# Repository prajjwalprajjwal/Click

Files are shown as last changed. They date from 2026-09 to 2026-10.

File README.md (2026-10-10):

# Clicker Project 🎮

Official repository for the Clicker handheld device ecosystem, encompassing production firmware, hardware schematics, PCB designs, automated asset build pipelines, and browser-based WebSerial flashing tools.

---

## 📁 Repository Structure

```text
Click/
├── README.md                          <-- Master documentation and system overview
├── PROJECT_RULES.md                  <-- Protected subsystems, NVS rules & coding freeze
├── CHANGELOG.md                      <-- Comprehensive release history & architecture decisions
├── platformio.ini                    <-- PlatformIO configuration & automated build flags
├── build_release.bat                 <-- 1-Click Interactive firmware release packager
├── run_flasher.bat                   <-- 1-Click Localhost WebSerial server runner
├── flash_device.bat                  <-- 1-Click Desktop CLI serial flasher
├── hardware/                         <-- Electrical schematics & mechanical designs
│   ├── vector_designs.ai             <-- Vector graphics & enclosure laser/artwork
│   └── PCB/                          <-- KiCad PCB manufacturing & CAD files
│       ├── Click1/                   <-- Active prototype KiCad PCB & schematic (ESP32-WROOM-32E)
│       ├── Click4/                   <-- Next-Gen RP2354A PCB (JLCPCB PCBA Production V0.0.1)
│       └── Resources/                <-- Edge cut DXF files and mechanical templates
├── server/                           <-- Cloudflare Worker + D1 Serverless Leaderboard Backend
│   ├── worker.js                     <-- Edge API routes (/api/leaderboard, /api/sync)
│   ├── schema.sql                    <-- D1 SQLite schema (devices, global_stats, sync_log)
│   ├── wrangler.toml                 <-- Cloudflare Worker deployment configuration
│   └── README.md                     <-- 3-minute zero-cost deployment guide
├── firmware/                         <-- Modular C++ embedded firmware
│   ├── assets/screens/               <-- 1-bit screen bitmaps & sprites (.png)
│   ├── scripts/
│   │   ├── pre_build_assets.py       <-- PlatformIO pre-build hook (auto-converts assets)
│   │   ├── convert_assets.py         <-- Converts PNGs to C PROGMEM bitmap headers
│   │   ├── flash.sh                  <-- Flashing utility for macOS / Linux
│   │   └── flash.bat                 <-- Flashing utility for Windows
│   └── src/                          <-- Application source code & applets
│       ├── main.cpp                  <-- Application entry point, serial protocol & registry
│       ├── system/                   <-- Core OS, drivers & power management (untouched by applets)
│       │   ├── Applet.h              <-- Base class interface for all applets
│       │   ├── OSManager.h / .cpp    <-- Applet scheduler & sleep lifecycle
│       │   ├── PowerManager.h        <-- Light/Deep sleep, UART isolation & I2C recovery
│       │   ├── Display.h             <-- SSD1306 OLED singleton & 400kHz fast I2C
│       │   ├── InputManager.h / .cpp <-- Debounced button state machine & hold triggers
│       │   ├── battery.hpp           <-- Battery voltage, percentage & charging status
│       │   └── device_info.hpp / .cpp<-- eFuse MAC ID & customizable owner name
│       ├── applets/                  <-- Self-contained, modular games & apps
│       │   ├── clicker/              <-- Sisyphus uphill clicker game & physics engine
│       │   ├── timing_game/          <-- "Just 10 Seconds" accuracy timing game
│       │   ├── flappy_bird/          <-- Flappy Bird arcade obstacle game
│       │   ├── settings/             <-- Hardware status, voltage & device ID screen
│       │   └── screensaver/          <-- Snowfall particle animation on idle
│       ├── fonts/                    <-- Custom Adafruit GFX typography headers
│       ├── screens/                  <-- Legacy milestone overlay renderers
│       └── generated_assets/         <-- Auto-generated C bitmap headers
├── web_flasher/                      <-- WebSerial flashing & leaderboard site (flashclick.uprajjwal.com.np)
│   ├── index.html                    <-- Web application entry point
│   ├── flasher.html                  <-- Full-featured WebSerial flasher, personalizer & leaderboard UI
│   ├── app.js                        <-- WebSerial engine, personalization & leaderboard sync
│   ├── style.css                     <-- Cyberpunk terminal responsive styling
│   ├── manifest.json                 <-- ESP Web Tools manifest configuration
│   └── versions.json                 <-- Firmware release registry
├── tools/                            <-- Build & developer utilities
│   ├── release/release_manager.py    <-- Interactive version bumper & binary packager
│   ├── flasher/serve_flasher.py      <-- Zero-config HTTP server for web_flasher
│   └── converters/                   <-- TTF font and image conversion scripts
└── docs/                             <-- Architectural specifications
    ├── hardware_and_pinouts.md       <-- Detailed pin profiles (ESP32 vs RP2354A)
    ├── device_identification_and_leaderboard.md <-- eFuse MAC & database schema
    └── leaderboard_architecture.md   <-- Cloudflare Worker API & score sync model
```

---

## ⚡ Hardware Platforms & Pin Profiles

Detailed technical schematics and electrical specifications can be found in [`docs/hardware_and_pinouts.md`](docs/hardware_and_pinouts.md).

> [!NOTE]
> **Active Hardware & Production Platforms**:
> - **Active Production Platform (Click 4 - RP2354A)**: Turnkey PCBA featuring the **Raspberry Pi RP2354A** MCU (Dual Cortex-M33, 512KB RAM, 4MB Flash). Features high-precision calibrated Li-Ion battery telemetry, 12MHz active sleep with $< 1\text{ mA}$ power consumption, dual SK6812 RGB LEDs, piezo sound, and PCF8563 RTC. Active default build environment: `env:rp2354`. Design files in `hardware/PCB/Click4/`.
> - **Legacy Prototype (Click 1 - ESP32-WROOM-32E)**: Hand-assembled prototype board maintained for backward compatibility under `env:esp32doit-devkit-v1`. Design files in `hardware/PCB/Click1/`.
> - **Power & Battery Deep-Dive**: For full architectural documentation on power management, battery discharge modeling, and silicon gotchas, read [**`docs/power_management_and_battery_architecture.md`**](docs/power_management_and_battery_architecture.md).

### Active Production Hardware Specs (Click 4: RP2354A)
- **Microcontroller**: Raspberry Pi RP2354A (Dual Cortex-M33 @ 48MHz, 512KB SRAM, 4MB on-chip Flash)
- **Display & RTC I2C Bus**: `CLICK_I2C = Wire1` (SDA = GP2, SCL = GP3, 400kHz Fast I2C)
- **User Inputs**: MODE = GP0 (Active LOW), ACTION = `BOOTSEL` / `QSPI_SS` (Active LOW)
- **Power & Battery**: STAT = GP1 (Active LOW charging from ETA6003 with 10k pullup), BAT_ADC = GP29 (ADC3 via 100k/100k divider)
- **Audio & Visual**: Buzzer = GP27 (via NPN BJT), RGB LEDs = GP11 (2× SK6812 DIN via PIO)
- **Power Management**: Same-Button Double-Click Wake protection (double-clicking the same key within 500ms), 3-stage sleep profile (8s dim, 15s display off, 30s deep sleep at 12MHz down-clocking $< 1\text{ mA}$), I2C bus preservation (0µA idle)

### Legacy Prototype Specs (Click 1: ESP32-WROOM-32E)
- **Microcontroller**: ESP32-WROOM-32E (Xtensa Dual-Core 240MHz, 4MB Flash)
- **Display I2C**: SDA = GPIO 21, SCL = GPIO 22 (400kHz Fast I2C)
- **User Inputs**: MODE = GPIO 14 (RTC ext0 wake), ACTION = GPIO 32 (RTC ext1 wake)
- **Power & Battery**: STAT = GPIO 33, BAT_ADC = GPIO 35 (100k/100k divider)
- **Sleep States**: Light sleep at 20s (OLED off, I2C pullups held), Deep sleep at 45s (RTC wakeup)

---

## 🕹️ Applet Ecosystem & Gameplay

The firmware features an event-driven `OSManager` hosting four built-in applets and an idle screensaver:

### 1. Sisyphus Clicker (Default Applet)
* **Theme**: Sisyphus rolling his eternal boulder up a steep mountain slope.
* **Dynamics**:
  * **Boulder Physics**: Smooth rotation and position tracking based on player clicks.
  * **Stamina & Fatigue**: Continuous clicking builds fatigue; stopping causes Sisyphus to catch his breath.
  * **Auditory Feedback**: 3 short beeps when the boulder rolls back downhill, with a gentle chime upon hitting bottom. Silent on startup into Sisyphus.
  * **Milestone Celebrations**: Overlay banners and RGB celebration pulses trigger on reaching milestone tiers.
  * **Persistence**: Dual-key NVS backup storage with checksum verification and wear-leveling.

### 2. Just Ten
* Precision stopwatch game challenging players to hold and release the button at exactly **10.0000 seconds**.
* Displays exact millisecond accuracy, tracks personal records, and flashes yellowish LEDs upon stopping.

### 3. Flappy Bird
* Real-time side-scrolling obstacle game featuring obstacle collision detection, velocity physics, and persistent high scores with red LED flash on game over.

### 4. Settings & System Applet
* Accessible by holding the **MODE** button.
* **Page 0 (SYSTEM)**: Shows live battery state (`[CHARGING]`, `[BATTERY]`, `[CHARGED]`), high-precision numerical voltage (`x.xxV`), and a graphical charge bar.
* **Page 1 (SYSTEM INFO)**: Center-aligned hardware telemetry displaying Firmware version, unique Device ID, and MCU specifications.

### 5. Snowfall Screensaver
* Ambient particle simulation that activates automatically when the device remains idle prior to entering sleep.

---

## 🎮 Controls & Navigation Guide

| Action | Control | Description |
|:---|:---|:---|
| **Cycle Applets** | `MODE` Button (Short Press) | Switch between **Clicker**, **Just Ten**, and **Flappy Bird** (click chime plays except before Sisyphus). |
| **Settings Menu** | `MODE` Button (Hold > 1s) | Toggle between the currently active applet and the **SYSTEM** settings screen. |
| **Toggle System Info** | `ACTION` Button (in Settings) | Toggle between Battery Telemetry (Page 0) and System Info (Page 1) screens. |
| **Primary Game Action** | `ACTION` Button (Short Press) | Push boulder in Sisyphus / Flap wings in Flappy Bird / Start & Stop in Just Ten. |
| **Wake from Sleep** | **Same-Button Double-Click** (two clicks on the same key within 500ms) | Wakes the device from low-power sleep back to the Sisyphus game (filters accidental single clicks & cross-key bumps). |
| **Factory Master Reset** | **Both Buttons Held** (> 4s) | Trigger master reset / clear NVS partitions and milestone progress. |

---

## 🛠️ Adding New Applets (Developer Guide)

The system firmware (`firmware/src/system/`) provides an isolated runtime environment. You or any contributor can add new games or micro-apps without touching, altering, or risking the core OS, sleep managers, or display drivers:

1. **Create an Applet Folder**: Create a directory in `firmware/src/applets/` (e.g., `firmware/src/applets/snake/`).
2. **Implement the `Applet` Interface**:
   ```cpp
   #pragma once
   #include "system/Applet.h"
   #include "system/Display.h"

   class SnakeApplet : public Applet {
   public:
       void init() override { /* Setup game state */ }
       void update() override { /* Real-time physics / tick loop */ }
       void draw() override { /* Draw frame on display */ }
       void cleanup() override { /* Teardown temporary state */ }
       void onActionClick() override { /* Handle ACTION button press */ }
   };
   ```
3. **Register in `firmware/src/main.cpp`**:
   ```cpp
   #include "applets/snake/SnakeApplet.h"
   SnakeApplet snakeApplet;

   // In setup():
   osManager.registerApplet(&snakeApplet);
   ```

All input debouncing, display clocking (400kHz Fast I2C), light sleep (15s), deep sleep (30s), and button wakeups continue working automatically in the background.

---

## 🚀 Building, Flashing & Updating

### 1. Web Flasher (Recommended)
* **Online**: Connect your device and visit [flashclick.uprajjwal.com.np](https://flashclick.uprajjwal.com.np).
* **Local Server**: Double-click [`run_flasher.bat`](run_flasher.bat) or run:
  ```bash
  python tools/flasher/serve_flasher.py
  ```

### 2. Desktop Command-Line Flashing
* **Windows**: Run [`flash_device.bat`](flash_device.bat).
* **macOS / Linux**:
  ```bash
  chmod +x firmware/scripts/flash.sh
  ./firmware/scripts/flash.sh
  ```

### 3. Building via PlatformIO
The project uses PlatformIO with an automated asset compilation hook:
```bash
# Compile firmware for Click 4 (Raspberry Pi RP2354A - Default target)
pio run -e rp2354

# Compile with interactive Hardware Diagnostics Suite enabled
pio run -e rp2354-debug

# Compile for legacy prototype (ESP32-WROOM-32E)
pio run -e esp32doit-devkit-v1

# Upload directly over USB serial
pio run --target upload

# Open serial monitor (115200 baud)
pio device monitor -b 115200
```

### 4. Automated Asset Pipeline
Screen graphics placed in `firmware/assets/screens/` are converted to C headers before every compile:
```bash
python firmware/scripts/convert_assets.py
```

### 5. Official Release Packaging
To build an official release, bump semantic versions, and generate 3-part manifests for WebSerial:
```bash
# Windows
.\build_release.bat

# Python direct
python tools/release/release_manager.py
```

## 🌐 Community Leaderboard & Edge Cloud Architecture

The Click ecosystem features a fully connected, zero-maintenance, zero-cost ($0/month) serverless stack running on **Cloudflare Workers** and **Cloudflare D1 (Serverless SQLite)**:

```mermaid
flowchart LR
    DEV["🎮 Clicker Device\n(ESP32 / RP2354A)"]
    WEB["💻 Web Flasher & Hub\n(flashclick.uprajjwal.com.np)"]
    CF["⚡ Cloudflare Worker\n(/api/sync, /api/leaderboard)"]
    D1[("🗄️ Cloudflare D1\n(SQLite at Edge)")]
    SITE["🏆 Community Leaderboard\n(click.uprajjwal.com.np)"]

    DEV <-->|"WebSerial (115200 Baud)\nGET_ID / GET_STATS / SET_NAME"| WEB
    WEB -->|"POST /api/sync\n(Atomic delta push)"| CF
    CF <-->|"ACID SQLite Queries\nAnti-Cheat Validation"| D1
    SITE <-->|"GET /api/leaderboard\n(Edge-cached JSON)"| CF
```

### 1. The "Community Boulder" Mechanic 🪨
* Unlike isolated single-player games, every single click registered on any Clicker device contributes to the **Global Community Boulder**.
* When players connect to the Web Flasher and sync their device, their delta clicks are atomically added to `global_stats.total_boulder_clicks`.
* The live web interface visualizes the worldwide community progress as one shared mountain ascent.

### 2. Anti-Cheat & Physical Rate Limiting 🛡️
* The Cloudflare Worker enforces strict human-velocity checks on every sync request:
  * Delta clicks are validated against elapsed time between syncs (enforcing a physical maximum cap of ~15–20 clicks per second).
  * Excessive or impossible spikes are flagged and rejected, ensuring the Community Boulder and leaderboard rankings remain authentic.
  * Every sync transaction is immutably audited in the `sync_log` table with delta claims and hash signatures.

### 3. Device Personalization & Custom Bootscreen ✨
* Clickers are uniquely identified by their hardware silicon signature:
  * **Raspberry Pi RP2354A**: Permanent 16-character hex Unique Board ID queried via `pico_get_unique_board_id()` (e.g. `E6614104033C71BF`).
  * **ESP32-WROOM-32E**: Factory 12-character hex eFuse MAC address via `ESP.getEfuseMac()` (e.g. `3C71BF89A1B2`).
* Through the Web Flasher interface, players can set or personalize their custom owner name (e.g. `"Prajjwal's Click"`).
* Custom names can be baked into binary firmware via magic rodata signatures (`CLICK_NAME_MAGIC_PREFIX`) or saved persistently to NVS storage (`clicker_cfg` namespace).
* Upon boot, the physical SSD1306 OLED screen proudly renders the personalized owner name on the boot splash screen.

### 4. Interactive Serial Telemetry Protocol 🔌
The firmware exposes a high-speed telemetry interface over USB CDC serial (115200 baud) for browser-based synchronization:
* `GET_STATS` / `STATS` &rarr; Flushes active clicks to storage and returns structured JSON telemetry:
  `{"event":"stats","name":"CLICKER","chip_id":"...","clicks":35200,"flappy":42,"just_ten":10.004,"uptime_hrs":12}`
* `SET_CLICKS <val>` &rarr; Sets lifetime click count and returns:
  `{"event":"clicks_updated","clicks":<val>}`
* `SET_STATS CLICKS=<n> FLAPPY=<n> JUST_TEN=<f>` &rarr; Restores all mini-game scores and returns:
  `{"event":"stats_restored","clicks":<n>,"flappy":<n>,"just_ten":<f>}`
* `PING` &rarr; Returns heartbeat response: `{"event":"pong"}`

### 5. Live Links & Deployment
* **Live Community Leaderboard**: [click.uprajjwal.com.np](https://click.uprajjwal.com.np)
* **Web Flasher & Device Hub**: [flashclick.uprajjwal.com.np](https://flashclick.uprajjwal.com.np)
* **Backend Source & Deployment Guide**: [`server/README.md`](server/README.md)

---

## ⚖️ License

This project (Firmware, PCB schematics & layouts, 3D mechanical designs, and assets) is licensed under the **Creative Commons Attribution-NonCommercial-ShareAlike 4.0 International License ([CC BY-NC-SA 4.0](LICENSE))**.

* **Personal & Educational Use**: ✅ You are welcome to view, modify, download, and fabricate units for your personal, non-commercial use.
* **Commercial Manufacturing & Sale**: ❌ Manufacturing, assembling, packaging, or selling physical units, kits, PCBs, or parts for commercial gain is strictly prohibited without prior written permission from the author.
* See [LICENSE](LICENSE) for complete terms.

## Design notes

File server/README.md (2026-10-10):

# Click Leaderboard & Global Boulder API (Cloudflare Worker + D1)

Zero-cost ($0/month), zero-maintenance serverless backend for the Click Community Leaderboard.

## 🚀 Quick Deploy in 3 Minutes

### 1. Log in to Cloudflare
In your terminal, navigate to this `server/` directory:
```bash
cd server
npx wrangler login
```

### 2. Create the D1 Database
Run:
```bash
npx wrangler d1 create click_db
```
This command will output your `database_id` (a UUID).
Copy that `database_id` into [`wrangler.toml`](file:///Users/prajjwal/Documents/GitHub/Click/server/wrangler.toml) replacing `YOUR_D1_DATABASE_ID_HERE`.

### 3. Initialize the Tables & Deploy
Run:
```bash
# Apply SQLite Schema to remote D1 database
npx wrangler d1 execute click_db --remote --file=schema.sql

# Deploy the Worker
npx wrangler deploy
```

Once deployed, Wrangler will give you a public URL like:
`https://click-leaderboard-api.<your-subdomain>.workers.dev`

You can also bind a custom domain in Cloudflare dashboard (e.g. `https://api.uprajjwal.com.np`).

---

## 📡 API Endpoints

### `GET /api/leaderboard`
Returns current community boulder stats and Top 10 leaderboards across all three minigames:
```json
{
  "global_boulder_clicks": 1420580,
  "total_devices": 38,
  "top_sisyphus": [
    { "device_name": "Prajjwal's Click", "total_clicks": 35200, "last_synced_at": "2026-09-13T08:00:00Z" }
  ],
  "top_flappy": [
    { "device_name": "SkyMaster", "flappy_high_score": 42, "last_synced_at": "2026-09-13T08:00:00Z" }
  ],
  "top_timing": [
    { "device_name": "PrecisionKing", "just_ten_best_ms": 4, "just_ten_time": 10.004, "last_synced_at": "2026-09-13T08:00:00Z" }
  ]
}
```

### `POST /api/sync`
Syncs stats from Web Flasher with human-speed rate limiting (`chip_id` is the 16-character RP2354A Unique Board ID or 12-character ESP32 eFuse MAC):
```json
{
  "chip_id": "3C71BF89A1B2",
  "name": "Prajjwal's Click",
  "clicks": 35200,
  "flappy": 42,
  "just_ten": 10.004,
  "uptime_hrs": 12
}
```
Response:
```json
{
  "success": true,
  "credited_delta": 350,
  "total_boulder_clicks": 1420580,
  "message": "Successfully synced! +350 clicks added to the Community Boulder."
}
```

### `GET /api/user?device_id=3C71BF89A1B2`
Retrieves registered player profile and stats for the given hardware chip ID:
```json
{
  "found": true,
  "device": {
    "chip_id": "3C71BF89A1B2",
    "device_name": "Prajjwal's Click",
    "total_clicks": 35200,
    "flappy_high_score": 42,
    "just_ten_time": 10.004,
    "just_ten_best_ms": 4
  }
}
```

---

## 🛡️ Anti-Cheat & Community Boulder Engine

1. **Human Click Velocity Validation**:
   - Caps delta clicks at humanly possible physical boundaries ($\le 20\text{ clicks/second}$).
   - Any client claiming abnormal click deltas relative to elapsed time since last sync is rejected or clamped to prevent botting/scripting.
2. **Atomic D1 SQLite Transactions**:
   - Updates both the individual device profile in `devices` and the collective boulder count in `global_stats` within an ACID transaction.
3. **Audit Trail**:
   - All claims are stored in `sync_log` with timestamp, claimed delta, credited delta, and hashed client IP.

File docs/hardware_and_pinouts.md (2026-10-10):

# Hardware Architecture & Pin Profiles Specification

This document provides the authoritative hardware reference for the Clicker project, documenting the active **Click 4 PCBA Platform (RP2354A)** and the legacy **Click 1 Prototyping Platform (ESP32-WROOM-32E)**.

> [!IMPORTANT]
> **Active Production Hardware**:
> 1. **Click 4 (RP2354A) - Primary Active Platform**:
>    - KiCad & PCBA Files: `hardware/PCB/Click4/` (`Click4.kicad_sch`, `Click4.kicad_pcb`, `Click4.step`).
>    - Features the Raspberry Pi **RP2354A** MCU (Dual Cortex-M33 with 4MB embedded QSPI Flash).
>    - Active default PlatformIO environment: `env:rp2354` in `platformio.ini`.
>    - Supports native USB 2.0 Full Speed flashing and debugging via `picotool`.
> 2. **Click 1 (ESP32-WROOM-32E) - Initial Hand-Assembled Prototype**:
>    - KiCad Files: `hardware/PCB/Click1/` (`click.kicad_sch`, `click.kicad_pcb`).
>    - Maintained for legacy compatibility under `env:esp32doit-devkit-v1`.

---

## Active Hardware Pinout & Specs (Click 4 PCBA - Raspberry Pi RP2354A)
*Authoritative pin routing defined in [`firmware/src/system/PinConfig.h`](file:///Users/prajjwal/Documents/GitHub/Click/firmware/src/system/PinConfig.h)*

- **Microcontroller**: Raspberry Pi RP2354A (QFN-56 package, 30 GPIOs: GP0–GP29, 512KB SRAM, 4MB on-chip QSPI Flash)
- **Display & RTC I2C Bus (`CLICK_I2C = Wire1`)**:
  - **SDA**: `GP2` (I2C1 SDA, Pin 4)
  - **SCL**: `GP3` (I2C1 SCL, Pin 5)
  - **Bus Speed**: 400kHz Fast I2C
  - **Peripherals**: 128×64 SSD1306 Monochrome OLED (`0x3C`) + NXP PCF8563 Real-Time Clock (`0x51`)
- **User Inputs**:
  - **MODE Button (`S1`)**: `GP0` (Active LOW, internal pull-up, level-sensitive wake capable)
  - **ACTION Button (`S2`)**: `BOOTSEL` / `QSPI_SS` (Active LOW, dual-purpose game click & bootloader pin)
- **Power & Battery Subsystem**:
  - **Battery Voltage Sense**: `GP29` (ADC3 / Pad 41) via 100kΩ / 100kΩ divider (2.0x factor, 12-bit ADC)
  - **Charger Status (`STAT`)**: `GP1` (Pad 3) &rarr; Driven by ETA6003 `STAT` pin (Active LOW while charging, 10kΩ pullup `R9` to +3V3)
  - **Battery Charger**: ETA6003Q3Q switching Li-Ion charging controller (`U5`) with 2.2µH power inductor (`L3`)
  - **Voltage Regulator**: Diodes Inc. AP2112K-3.3 (`U2`) 3.3V 600mA ultra-low-dropout regulator (EN tied to slide switch `SW1`)
- **Visual & Auditory Feedback**:
  - **RGB Lighting**: 2× SK6812/WS2812 addressable RGB LEDs daisy-chained on `GP11` (DIN) driven by PIO state machine
  - **Audio Buzzer**: Magnetic piezo buzzer driven via MMBT3904 NPN BJT on `GP27`
- **Native USB Interface**:
  - Direct USB DP/DM routing on RP2354 pads to 16-pin USB Type-C receptacle (`J1`) with 5.1kΩ CC resistors.
  - Native CDC serial telemetry & WebSerial flashing at 115200 baud.

---

## Legacy Hardware Pinout & Specs (Click 1 Prototype - ESP32-WROOM-32E)
*Maintained under `firmware/src/system/PinConfig.h` for ESP32 builds*

- **Microcontroller**: ESP32-WROOM-32E (Xtensa Dual-Core 240MHz, 4MB Flash)
- **Display I2C (`J2`)**: 128×64 SSD1306 Monochrome OLED
  - **SDA**: `GPIO 21` (Pad 33)
  - **SCL**: `GPIO 22` (Pad 36)
  - Bus Speed: 400kHz Fast I2C
- **User Inputs**:
  - **MODE Button (`S1`)**: `GPIO 14` (Pad 13) &rarr; Active LOW, internal pull-up, RTC ext0 wake capable
  - **ACTION Button (`S2`)**: `GPIO 32` (Pad 8) &rarr; Active LOW, internal pull-up, RTC ext1 wake capable
- **Power & Battery Subsystem**:
  - **Battery Voltage Sense**: `GPIO 35` via 100kΩ / 100kΩ resistor divider (12-bit ADC)
  - **Charger Status (`STAT`)**: `GPIO 33` from ETA6003 charging IC (Active LOW)
  - **Battery Charger**: ETA6003Q3Q Li-Ion charging management IC
  - **Voltage Regulator**: HT7833 3.3V 500mA LDO
- **USB & Debug Interface**:
  - **USB-to-UART Bridge**: CH340C with built-in clock oscillator
  - **UART Console**: `TXD0` = `GPIO 1`, `RXD0` = `GPIO 3` (isolated with pad holds in sleep)
  - **Real-Time Clock**: NXP PCF8563TS I2C RTC with 32.768 kHz crystal (`Y2`)
- **Connector**: 16-pin USB Type-C receptacle (`J1`) with 5.1kΩ CC pull-downs

---

## 1. Side-by-Side Comparison Matrix

| Subsystem / Feature | Active Platform (Click 4: RP2354A) | Legacy Prototype (Click 1: ESP32) | Hardware & Pinout Rationale |
|:---|:---|:---|:---|
| **Board Revision** | **Click 4** (`hardware/PCB/Click4/`) | **Click 1** (`hardware/PCB/Click1/`) | Production PCBA vs. Initial manual prototype |
| **MCU Silicon** | Raspberry Pi RP2354A (Dual Cortex-M33) | ESP32-WROOM-32E (Xtensa Dual-Core) | RP2354A features 512KB RAM & 4MB internal QSPI flash |
| **Default Build Env** | `env:rp2354` (PlatformIO) | `env:esp32doit-devkit-v1` | Compiled with earlephilhower arduino-pico core |
| **I2C SDA (Display/RTC)** | `GP2` (I2C1 SDA) | `GPIO 21` | Shared 400kHz Fast I2C bus for SSD1306 and PCF8563 |
| **I2C SCL (Display/RTC)** | `GP3` (I2C1 SCL) | `GPIO 22` | External pull-ups to +3V3 rail |
| **Primary Input (ACTION)**| `BOOTSEL` / `QSPI_SS` | `GPIO 32` | Dual-purpose hardware game click & flash bootloader |
| **Secondary Input (MODE)** | `GP0` (Active LOW) | `GPIO 14` | Applet switching & settings hold trigger |
| **Key Switches** | Cherry MX style PCB sockets | Tactile pushbuttons | High-end mechanical switch tactile feedback |
| **Battery Charger** | ETA6003Q3Q (`U5`) + 2.2µH Inductor | ETA6003Q3Q | High-efficiency switching Li-Ion charging |
| **Charger Status (`STAT`)**| `GP1` (Active LOW, 10kΩ pullup `R9`) | `GPIO 33` | LOW = Charging, HIGH = Battery / Unplugged |
| **Battery Sense (`ADC`)** | `GP29` (ADC3 via 100k/100k divider) | `GPIO 35` (100k/100k divider) | Calibrated non-linear Li-Ion SoC plateau mapping |
| **Voltage Regulator** | AP2112K-3.3 (600mA Low-Dropout LDO) | HT7833 (500mA LDO) | Hardware slide switch `SW1` directly toggles `EN` line |
| **USB Interface** | Native USB 2.0 Full Speed (Type-C) | CH340C USB-to-UART + Type-C | Direct D+/D- routing eliminates discrete bridge IC |
| **Audio / Haptics** | Magnetic Buzzer (GP27 via MMBT3904) | N/A | High-pitch auditory feedback for clicks & game events |
| **RGB Lighting** | 2× SK6812/WS2812 DIN on `GP11` | N/A | Dual addressable LEDs driven by PIO state machine |
| **Real-Time Clock** | NXP PCF8563TS (I2C1: GP2/GP3) | N/A | Dedicated battery-backed 32.768kHz RTC |

---

## 2. Power Architecture & Battery Management

> [!TIP]
> **Complete Technical Deep-Dive**: For exhaustive coverage of power optimization, battery fuel gauging, sleep currents, and silicon gotchas, see the dedicated master guide:
> 🔗 **[`docs/power_management_and_battery_architecture.md`](power_management_and_battery_architecture.md)**

### Click 4 Production Power Architecture
```mermaid
flowchart TD
    USB[USB-C Receptacle\nJ1 16-pin] -->|VBUS 5V| ETA[ETA6003Q3Q\nU5 Charger]
    BATT[LiPo Battery\nBC-25-3P Contact] <-->|Charge / Discharge| ETA
    ETA -->|SYS Rail| SW[Slide Switch\nSW1]
    SW -->|EN Pin| LDO[AP2112K-3.3\n600mA LDO]
    LDO -->|+3V3 Rail| MCU[Raspberry Pi\nRP2354A MCU]
    LDO -->|+3V3 Rail| OLED[128x64 OLED\nI2C1: GP2/GP3]
    LDO -->|+3V3 Rail| RTC[PCF8563 RTC\nI2C1: GP2/GP3]
    LDO -->|+3V3 Rail| LED[2x SK6812 LEDs\nDIN: GP11]
    LDO -->|+3V3 Rail| BUZZ[Piezo Buzzer\nGP27 Driver]
    ETA -->|STAT: GP1| MCU
    BATT -->|R11/R12 Divider| MCU[BAT_ADC: GP29]
```

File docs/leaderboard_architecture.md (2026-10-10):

# Web-Connected Leaderboard & Flashing Architecture

This document specifies the end-to-end integration architecture connecting the hardware Clicker device, the browser-based WebSerial flasher, and the community leaderboard.

---

## 1. System Architecture

```mermaid
flowchart LR
    subgraph Client["Player Hardware"]
        DEV["Clicker Device\n(RP2354A / ESP32)"]
    end

    subgraph Flashing["WebSerial Interface"]
        WF["Web Flasher & Device Hub\n(flashclick.uprajjwal.com.np)"]
    end

    subgraph Cloud["Serverless Edge Backend"]
        API["Cloudflare Worker\n(/api/sync, /api/leaderboard)"]
        DB[("Cloudflare D1\n(Serverless SQLite at Edge)")]
    end

    subgraph Web["Public Interface"]
        SITE["Community Leaderboard\n(click.uprajjwal.com.np)"]
    end

    DEV <-->|"WebSerial (115200 Baud)\nGET_STATS, SET_CLICKS"| WF
    WF -->|"POST /api/sync\n(Delta submission & anti-cheat)"| API
    API <-->|"ACID SQLite Transactions"| DB
    SITE <-->|"GET /api/leaderboard\n(Edge cached)"| API
```

---

## 2. Device Identity & Personalization Protocol

1. **Hardware Identity & Telemetry Interrogation**:
   - The user connects the Clicker via USB to `flashclick.uprajjwal.com.np` and clicks "Connect Device".
   - The browser opens a WebSerial port at 115200 baud and issues `\r\nGET_STATS\r\n`.
   - The firmware immediately flushes any active session clicks to persistent NVS storage, reads unique hardware identity (RP2354A 16-hex Unique Board ID or ESP32 12-hex eFuse MAC), queries all applets, and returns structured JSON:
     ```json
     {"event":"stats","name":"Prajjwal's Click","chip_id":"E6614104033C71BF","clicks":35200,"flappy":42,"just_ten":10.004,"uptime_hrs":12}
     ```
2. **Personalization & Bootscreen Customization**:
   - The owner name can be embedded into the firmware image via binary magic rodata signatures (`__CLICK_NAME__:<name>:__END_NAME___`) during web flashing, or stored in NVS under `clicker_cfg`.
   - On every boot or reset, the SSD1306 OLED boot screen dynamically renders this custom handle.
3. **Delta Submission & Global Boulder Sync**:
   - The browser parses the JSON telemetry and issues a `POST /api/sync` payload to the Cloudflare Worker edge API:
     ```json
     {
       "chip_id": "E6614104033C71BF",
       "name": "Prajjwal's Click",
       "clicks": 35200,
       "flappy": 42,
       "just_ten": 10.004,
       "uptime_hrs": 12
     }
     ```

---

## 3. The "Community Boulder" Shared Mechanic 🪨

Rather than just isolated individual rankings, every click on every Clicker contributes to the **Global Community Boulder**:
* When a device syncs, the backend calculates:
  $$\Delta_{\text{clicks}} = \text{claimed\_clicks} - \text{last\_synced\_clicks}$$
* If valid, $\Delta_{\text{clicks}}$ is atomically added to `global_stats.total_boulder_clicks`:
  ```sql
  UPDATE global_stats SET total_boulder_clicks = total_boulder_clicks + ? WHERE id = 1;
  ```
* The web app renders the cumulative global progress as a shared mountain climb.

---

## 4. Server-Side Anti-Cheat & Physical Rate Limiting 🛡️

To prevent automated bot scripts or artificial click injection from corrupting the Community Boulder:
1. **Human Click Speed Cap**:
   - Maximum sustained human finger speed is capped at $\le 20 \text{ clicks/second}$.
2. **Elapsed Time Validation**:
   - Time difference $\Delta t = \text{current\_time} - \text{last\_synced\_at}$.
   - Maximum plausible delta: $\Delta_{\text{max}} = 20 \times \Delta t$.
   - Any payload claiming $\Delta_{\text{clicks}} > \Delta_{\text{max}}$ (or negative deltas) is flagged, rejected, or clamped.
3. **Audit Log**:
   - Every sync attempt is recorded in `sync_log` table with `chip_id`, `delta_claimed`, `delta_credited`, and hashed IP address.

---

## 5. Cloudflare Worker API Endpoints

### A. `GET /api/leaderboard`
Returns community stats and Top 10 rankings across all games:
```json
{
  "global_boulder_clicks": 1420580,
  "total_devices": 38,
  "top_sisyphus": [
    { "device_name": "Prajjwal's Click", "total_clicks": 35200, "last_synced_at": "2026-09-13T08:00:00Z" }
  ],
  "top_flappy": [
    { "device_name": "SkyMaster", "flappy_high_score": 42, "last_synced_at": "2026-09-13T08:00:00Z" }
  ],
  "top_timing": [
    { "device_name": "TimeLord", "just_ten_best_ms": 4, "just_ten_time": 10.004, "last_synced_at": "2026-09-13T08:00:00Z" }
  ]
}
```

### B. `POST /api/sync`
Submits hardware metrics with rate-limited crediting:
```json
{
  "chip_id": "3C71BF89A1B2",
  "name": "Prajjwal's Click",
  "clicks": 35200,
  "flappy": 42,
  "just_ten": 10.004,
  "uptime_hrs": 12
}
```
Response:
```json
{
  "success": true,
  "credited_delta": 350,
  "total_boulder_clicks": 1420580,
  "message": "Successfully synced! +350 clicks added to the Community Boulder."
}
```

### C. `GET /api/user?device_id=3C71BF89A1B2`
Retrieves stored profile and metrics for a specific hardware unit.

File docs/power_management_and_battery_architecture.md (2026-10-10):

# Power Management & Battery Architecture Deep-Dive ⚡🔋

*An engineering case study on micro-power optimization, battery fuel gauging, and silicon-level gotchas in the Clicker handheld ecosystem.*

---

## 📖 Executive Summary

The **Clicker** is an open-hardware, ultra-tactile gaming handheld featuring mechanical keyboard switches, a 128×64 SSD1306 OLED display, dual addressable SK6812/WS2812 RGB LEDs, a piezo buzzer, an NXP PCF8563 real-time clock, and a single-cell Li-Ion/LiPo battery, all driven by the high-density **Raspberry Pi RP2354A** microcontroller.

While creating games on microcontrollers is straightforward, engineering a production-grade battery-powered handheld is deceptively challenging:
1. **Tiny Battery, High Expectations**: A pocketable handheld relies on a small (150–350mAh) Lithium-Polymer cell. Without aggressive power management, standard 133MHz clocking, OLED charge pumps, and addressable LEDs will drain the battery in under 2 hours.
2. **The "Surface Charge" Illusion**: Users hate seeing battery gauges display 100% and drop to 85% within five seconds of unplugging. Mapping voltage linearly to percentage fails completely on real lithium chemistry.
3. **Silicon & Driver Traps**: Hardware register overrides in embedded USB stacks, floating CMOS input buffers, and addressable LED ghost leakage can quietly draw milliamps in standby, draining the cell while the device is in a drawer.

This document details every power challenge faced on the Clicker platform, the root causes identified through hardware debugging, the exact software/firmware solutions implemented, and key takeaways for engineers and tech writers.

---

## 🛠️ Hardware Power Topology

```mermaid
flowchart TD
    USB["🔌 USB Type-C Receptacle\n(5V VBUS + 5.1k CC)"] -->|5V Power| ETA["⚡ ETA6003Q3Q Charger\n(Switching Li-Ion Controller)"]
    ETA -->|STAT Pin / GPIO 1\n(Active LOW)| MCU["🧠 RP2354A MCU\n(Dual Cortex-M33 @ 48MHz)"]
    
    BATT["🔋 Li-Ion / LiPo Cell\n(3.7V Nom, 4.2V Max)"] <-->|Charge / Discharge| ETA
    BATT -->|100kΩ / 100kΩ Divider| ADC["📊 ADC3 / GPIO 29\n(Battery Voltage Monitor)"]
    
    ETA -->|SYS Power Rail| SW["🔘 Slide Switch (SW1)\n(Hardware Master Cut)"]
    SW -->|Enable Pin| LDO["🔌 AP2112K-3.3\n(600mA Ultra-Low-Dropout)"]
    
    LDO -->|+3V3 Main Power Rail| MCU
    LDO -->|+3V3 Main Power Rail| OLED["📺 SSD1306 128x64 OLED\n(I2C1: GP2 / GP3)"]
    LDO -->|+3V3 Main Power Rail| RTC["⏰ PCF8563 RTC\n(I2C1: GP2 / GP3)"]
    LDO -->|+3V3 Main Power Rail| LED["💡 2x SK6812 RGB LEDs\n(DIN: GP11)"]
    LDO -->|+3V3 Main Power Rail| BUZZ["🔊 Piezo Buzzer\n(BJT Driver: GP27)"]
```

### Component Breakdown
| Component | Function | Normal Draw | Sleep / Quiescent Draw | Key Challenge |
|:---|:---|:---|:---|:---|
| **RP2354A** | Dual Cortex-M33 MCU | 18–35 mA (at 133MHz) | < 0.8 mA (at 12MHz `__wfi()`) | QSPI BOOTSEL button cannot wake from `xosc_dormant()` |
| **ETA6003** | Li-Ion Switching Charger | N/A (Charging: 200–500mA) | < 10 µA standby | STAT pin requires pullup to detect unplugged state |
| **SSD1306** | 128×64 Monochrome OLED | 8–18 mA (charge pump active) | < 5 µA (`DISPLAYOFF`) | Contrast settings drastically impact active current |
| **2× SK6812** | Addressable RGB LEDs | 10–30 mA per LED when lit | 0.8–1.2 mA quiescent each | Floating DIN pin causes ghost glow and leakage |
| **PCF8563** | Real-Time Clock | 0.25 µA | 0.25 µA | Unused CLKOUT pin oscillates at 32.768kHz by default |
| **Piezo Buzzer** | Audio feedback | 15–25 mA during tone | 0.0 µA (transistor cut off) | Base pin must never float |

---

## 🔬 The 6 Major Power Mysteries & Engineering Solutions

---

### Case 1: The Phantom VBUS Trap (`sie_status` Silicon Override)

#### The Problem
When the USB-C cable was unplugged, the OLED display continued to report `[CHARGING]`, and the RGB LEDs stayed in their USB breathing pattern indefinitely. The device never knew it was running on battery power!

#### Root Cause Investigation
In firmware, we initially queried the RP2350 USB hardware register to detect cable presence:
```cpp
bool vbus_present = (usb_hw->sie_status & USB_SIE_STATUS_VBUS_DETECTED_BITS) != 0;
```
However, looking into the low-level Arduino-Pico / TinyUSB device controller driver (`dcd_rp2040.c`), we discovered this initialization sequence:
```c
usb_hw->pwr = USB_USB_PWR_VBUS_DETECT_BITS | USB_USB_PWR_VBUS_DETECT_OVERRIDE_EN_BITS;
```
Because the standard Raspberry Pi Pico board lacks a hardware VBUS sensing pin wired to the USB peripheral, the TinyUSB driver **hardcodes a silicon-level override** that forces `sie_status` to report VBUS as permanently present! Reading this register on RP2350 always returns `true`, even with no cable attached.

#### The Fix
We investigated the physical PCB schematic ([`hardware/PCB/Click4/Click4.kicad_pcb`](file:///Users/prajjwal/Documents/GitHub/Click/hardware/PCB/Click4/Click4.kicad_pcb)) and verified that **Pad 9 (`STAT`)** of the ETA6003 charge controller is connected directly to **RP2354 GPIO 1**, with an external 10kΩ pull-up resistor `R9` to `+3V3`:
- When USB is plugged in and the battery is actively charging, the ETA6003 pulls `STAT` **LOW** (0V).
- When the battery is full or the USB cable is unplugged, the internal open-drain transistor releases `STAT`, and `R9` pulls it **HIGH** (3.3V).

In [PinConfig.h](file:///Users/prajjwal/Documents/GitHub/Click/firmware/src/system/PinConfig.h#L46-L48) and [battery.hpp](file:///Users/prajjwal/Documents/GitHub/Click/firmware/src/system/battery.hpp#L104-L111):
```cpp
#define CHARGER_STAT_PIN 1

static bool isCharging() {
    return digitalRead(CHARGER_STAT_PIN) == LOW;
}
```
Now, the moment the USB cable is pulled, `digitalRead(1)` reads `HIGH` within 10 milliseconds, instantly stopping the breathing LED and transitioning to battery mode.

---

### Case 2: The Non-Linear Battery "Free Fall" (100% $\to$ 85% in Seconds)

#### The Problem
After fully charging the device and unplugging it, the battery percentage showed 100%, but within 5 to 10 seconds of clicking, it dropped to 95%, 90%, and 85%.

#### Why Lithium Batteries Are Not Linear
A standard linear conversion maps voltage directly between 3.3V (0%) and 4.2V (100%):
$$\text{Linear \%} = \frac{V - 3.30}{4.20 - 3.30} \times 100$$
This model fails on Lithium-Ion / Lithium-Polymer chemistry for three physical reasons:

1. **Surface Charge Relaxation**: When a battery finishes charging at 4.20V, a temporary electrostatic layer ("surface charge") forms on the electrode plates. As soon as charging stops, chemical diffusion equalizes the cell, and the open-circuit voltage naturally relaxes from 4.20V down to **4.08V–4.12V**, even with zero discharge!
2. **Internal Resistance ($IR$) Voltage Drop**: Under operating load, the battery terminal voltage is given by Ohm's Law:
   $$V_{\text{terminal}} = V_{\text{OCV}} - (I_{\text{load}} \times R_{\text{internal}})$$
   A compact 200mAh LiPo has an internal resistance of $0.5\Omega - 1.0\Omega$. When the RP2354 and OLED turn on ($I_{\text{load}} \approx 20\text{ mA}$), terminal voltage drops by 15–25mV instantly.
3. **The Flat Discharge Plateau**: Over 60% of a LiPo cell's stored energy is delivered between **3.70V and 3.90V**. Only 5% of energy exists above 4.10V.

If your code maps $4.08\text{V} \to 90\%$, then natural surface charge relaxation and turning on the screen will cause a 10% drop within seconds, alarming the user!

#### The Fix: Piecewise Li-Ion Calibration & Discharge Damping
We implemented an authentic consumer-grade fuel gauge model in [battery.hpp](file:///Users/prajjwal/Documents/GitHub/Click/firmware/src/system/battery.hpp#L57-L215):

```cpp
static int calculatePercentageFromVoltage(float v, bool charging) {
    float effectiveV = v;
    if (charging) {
        // Compensate for charging IR rise (~40mV)
        if (v < 4.00f) effectiveV = v - 0.04f;
        else if (v < 4.15f) effectiveV = v - 0.04f * (1.0f - (v - 4.00f) / 0.15f);
    }

    // Calibrated Non-Linear Li-Ion Plateau Model
    if (effectiveV >= 4.08f) return 100; // 100% cushion: holds 100% across natural relaxation
    if (effectiveV >= 4.00f) return 90 + (effectiveV - 4.00f) / (4.08f - 4.00f) * 10;
    if (effectiveV >= 3.90f) return 75 + (effectiveV - 3.90f) / (4.00f - 3.90f) * 15;
    if (effectiveV >= 3.80f) return 52 + (effectiveV - 3.80f) / (3.90f - 3.80f) * 23; // Nominal plateau
    if (effectiveV >= 3.72f) return 30 + (effectiveV - 3.72f) / (3.80f - 3.72f) * 22;
    if (effectiveV >= 3.62f) return 12 + (effectiveV - 3.62f) / (3.72f - 3.62f) * 18;
    if (effectiveV >= 3.48f) return 3  + (effectiveV - 3.48f) / (3.62f - 3.48f) * 9;  // Low knee
    if (effectiveV >= 3.35f) return (effectiveV - 3.35f) / (3.48f - 3.35f) * 3;
    return 0;
}
```

#### Temporal Damping Rules
- **Post-Unplug Grace Period**: A 2-minute relaxation timer freezes percentage decrements immediately following an unplug event, allowing the double-layer capacitance in the battery to stabilize.
- **Slew-Rate Limiting**: On battery, the displayed percentage is capped to decrement at most **1% every 35 seconds**. Rapid dips from brief buzzer chirps or LED flashes are filtered out entirely.

---

### Case 3: The Missing Decimal Bug (`Voltage: V`)

#### The Problem
In the Settings telemetry screen, the battery voltage rendered as `"Voltage: V"`, with the numbers completely blank!

#### Root Cause
The RP2354 firmware is compiled with GCC ARM Embedded using `newlib-nano` libc. To keep binary footprints small (saving ~12KB of flash), `newlib-nano` **omits floating-point formatters from `printf` and `snprintf` by default**.
When `snprintf(buf, sizeof(buf), "Voltage: %.2fV", voltage)` was executed:
- `%.2f` was treated as an unhandled specifier and produced an empty string.
- The output string became literally `"Voltage: V"`.

#### The Fix
1. **Integer Decomposition**: In [SettingsApplet.h](file:///Users/prajjwal/Documents/GitHub/Click/firmware/src/applets/settings/SettingsApplet.h#L53-L58), we broke the float into whole and fractional integer parts:
   ```cpp
   int vWhole = (int)voltage;
   int vFrac = (int)(voltage * 100.0f + 0.5f) % 100;
   snprintf(buf, sizeof(buf), "%d.%02dV", vWhole, vFrac);
   ```
   This is 100% portable, executes in under 1 microsecond, and uses zero heap/float library overhead.
2. **Linker Flag Safeguard**: In [platformio.ini](file:///Users/prajjwal/Documents/GitHub/Click/platformio.ini#L27), added `-Wl,-u,_printf_float` to link the floating-point `printf` routine across the firmware.

---

### Case 4: Accidental Pocket Clicks & Double-Click Wake Architecture

#### The Problem
When the device went to sleep in a user's pocket or bag, inadvertent bumps and single clicks would accidentally wake the device and cause unwanted game clicks. Furthermore, previous attempts to aggressively tear down the I2C bus and switch PLL clocks during sleep caused the OLED I2C peripheral to hang upon wake, forcing the user to power cycle via the physical ON/OFF switch (`SW1`).

#### Silicon Hardware Architecture
- The **MODE button** is on **GPIO 0**, which belongs to **IO_BANK0** (active LOW with internal pull-up).
- The **ACTION button** is connected to **`BOOTSEL` (`QSPI_SS`)**. On the RP2350/RP2354, the QSPI interface belongs to the **QSPI pad bank** and is read via the `BOOTSEL` hardware accessor.

#### The Solution: Same-Button Double-Click Wake & 3-Stage Sleep Architecture
1. **3-Stage Power-Saving Profile**:
   - **Stage 1 (8 seconds idle)**: OLED contrast drops to `0x05`, decreasing display current consumption by ~60%.
   - **Stage 2 (15 seconds idle - `lightSleepTimeout`)**: OLED display turns OFF completely (`SSD1306_DISPLAYOFF`).
   - **Stage 3 (30 seconds idle - `deepSleepTimeout`)**: The MCU enters true **DEEP SLEEP**:
     - System clock down-clocks from 48MHz to 12MHz direct crystal clock via `set_sys_clock_khz(12000, false)`.
     - Digital input buffers on unused CMOS GPIOs are disabled to prevent shoot-through.
     - ADC converter core is completely powered down (`hw_clear_bits(&adc_hw->cs, ADC_CS_EN_BITS)`).
     - WS2812 DIN and buzzer base pins are clamped to 0V GND.
     - CPU enters ARM Cortex-M33 `__wfi()` sleep, dropping total board current to **$< 1\text{ mA}$**.
2. **Double-Click on the SAME Button (`click-click` within 500ms)**:
   - The first click wakes the MCU core internally, but **does not turn on the device**: the OLED, LEDs, and buzzer remain completely OFF.
   - The system checks if a second click occurs on the **SAME button** within a **500ms window**:
     - If the user clicked `ACTION`, only a second click on `ACTION` wakes the device.
     - If the user clicked `MODE`, only a second click on `MODE` wakes the device.
     - Clicking one key and then pressing another key is rejected as accidental pocket contact, keeping the device asleep.
   - If no second click occurs, the window times out (500ms) and the MCU returns directly to `__wfi()` sleep.
   - Continuous holds ($> 3\text{s}$) from a button squeezed in a bag or pocket are ignored.
3. **I2C Bus Preservation**:
   - The I2C bus (`Wire1` on GP2/GP3) is kept intact during sleep. When idle, SDA and SCL remain pulled HIGH by external 4.7kΩ resistors, drawing $0\text{ µA}$.
   - The SSD1306 is placed in low-power standby via `SSD1306_DISPLAYOFF` without bus teardowns or glitchy SCL pulse trains.
   - Upon confirmed same-button double click, `set_sys_clock_khz(48000, false)` restores 48MHz, and `SSD1306_DISPLAYON` restores the display in $< 1\text{ ms}$ with 100% reliability.

#### Results
- Eliminates unwanted accidental pocket clicks completely.
- Clicking one key and then another will NOT wake the device; only double-clicking the **SAME** key within 500ms wakes it.
- Preserves the fast 30s deep sleep profile ($< 1\text{mA}$ micro-power standby) and 15s screen off.
- Display turns on instantly without any I2C lockups or power-switch resets.

---

### Case 5: Ghost LED Glow & Sleep Current Leakage

#### The Problem
When the device went to sleep, one of the two RGB LEDs sometimes remained dimly lit with a faint green or red glow, slowly draining the battery.

#### Root Cause
The SK6812/WS2812 NeoPixel protocol uses high-speed 800kHz single-wire pulse-width modulation. When the RP2354 goes to sleep, if the GPIO output pin is left floating (High-Z), capacitive charge on the PCB trace or inductive noise from the OLED power rail can couple into the LED's high-impedance `DIN` pin. The internal SK6812 shift register interprets this noise as valid data bits, turning on its internal constant-current driver.

#### The Fix: Hardware Latch & Ground Clamp
In [WS2812.h](file:///Users/prajjwal/Documents/GitHub/Click/firmware/src/system/WS2812.h#L111-L140), we created `clearAndHaltForSleep()`:
1. **Dual Zero Frame**: Send two consecutive frames of pure 0s (`0x000000`) and wait 10ms to ensure both cascaded SK6812 ICs latch into their zero state.
2. **Peripheral Disconnect**: De-mux GP11 from the PIO state machine and switch it to standard SIO GPIO output.
3. **Solid Ground Clamp & Pull-Down**: Clear the output bit, drive GP11 LOW (0V), and enable the internal hardware pull-down resistor (`gpio_pull_down(11)`).

In addition, we eliminated other standby leaks:
- **RTC CLKOUT**: The PCF8563 default state outputs a continuous 32.768kHz square wave on CLKOUT. In [main.cpp](file:///Users/prajjwal/Documents/GitHub/Click/firmware/src/main.cpp#L166-L170), we write `0x00` to register `0x0D`, disabling CLKOUT and saving ~15µA.
- **Floating CMOS Inputs**: Disabled digital input buffers on all unused Bank 0 GPIOs via `gpio_set_input_enabled(pin, false)` to prevent shoot-through currents in floating input transistors.

---

### Case 6: Charging Breathing LED vs. In-Game LED Effects

#### The Problem
1. While plugged into the charger, switching between applets caused the breathing LED to abruptly turn off and restart because applet `cleanup()` and `init()` routines called `WS2812Driver::clear()`.
2. Conversely, when we made charging breathing indestructible, in-game LED cues (like the yellow flash on Just Ten game over, or the red flash on Flappy Bird death) could not be seen while charging.

#### The Fix: Hierarchical Priority Engine
We established an intelligent state machine in [WS2812.h](file:///Users/prajjwal/Documents/GitHub/Click/firmware/src/system/WS2812.h) and [main.cpp](file:///Users/prajjwal/Documents/GitHub/Click/firmware/src/main.cpp#L343-L357):

```mermaid
stateDiagram-v2
    [*] --> Off: On Battery Idle
    Off --> InGameEffect: Flash / Celebration Triggered
    InGameEffect --> Off: Effect Timer Expires (clear())
    
    [*] --> ChargingBreathe: USB Plugged In
    ChargingBreathe --> ChargingBreathe: Applet Switch (clear() ignored)
    ChargingBreathe --> InGameEffect: Game Win / Over Triggered
    InGameEffect --> ChargingBreathe: Effect Timer Expires (clear() auto-resumes)
    ChargingBreathe --> Off: USB Unplugged
```

1. **Applet Switch Protection**: When `WS2812Driver::clear()` is called while charging, if the current effect is `CHARGING_BREATHE`, the call is ignored. The breathing cycle continues uninterrupted.
2. **Transient Game Preemption**: In-game triggers (`flash()`, `startCelebration()`) are allowed to temporarily override `CHARGING_BREATHE`.
3. **Seamless Resume**: In `main.cpp`, `loop()` checks `!WS2812Driver::isBusy()`. While the 500ms flash plays, the charging loop stays hands-off. As soon as the flash timer expires, `clear()` detects that `isChargingHardware()` is true and seamlessly switches back to `CHARGING_BREATHE`.

---

## 📊 Power Measurements & Battery Life Analysis

Calculated for a standard **300mAh 3.7V (1.11Wh) Lithium-Polymer cell**:

| Operating State | System Clock | Display State | Audio / LEDs | Current Draw | Estimated Battery Life |
|:---|:---|:---|:---|:---|:---|
| **Active Gameplay (Sisyphus)** | 48 MHz | ON (Normal Contrast) | Buzzer chirps, LED idle | ~18–22 mA | **~14–16 Hours** |
| **Idle Screen Dimmed** | 48 MHz | ON (Contrast 0x05) | OFF | ~11–13 mA | **~24 Hours** |
| **Standby Sleep Mode** | 12 MHz (`__wfi()`) | OFF (`DISPLAYOFF`) | Clamped to GND | **< 0.8 mA** | **~375+ Hours (~15 Days)** |
| **Hardware Cutoff (Switch Off)**| 0 Hz | OFF | Cut at AP2112K EN | **< 0.01 mA** | **Shelf Life (> 1 Year)** |

---

## ✍️ Gemini Notebook / Blog Post Writing Prompts

When you paste this documentation into Google Gemini or your blog writing workflow, use these prompts to generate engaging technical articles:

### Prompt 1: The Narrative Angle (Engineering Story)
> *"Write an engaging, first-person developer story about the hidden challenges of building a physical handheld gaming device. Use the Clicker project as the case study. Focus on the emotional rollercoaster of thinking hardware is broken vs. finding out that the USB silicon registers had hardcoded overrides. Emphasize why hardware-software co-design matters."*

### Prompt 2: The Deep-Tech Angle (Embedded Systems & Battery Physics)
> *"Generate a technical tutorial for embedded C++ developers explaining why naive battery voltage reading fails on Lithium-Polymer cells. Break down internal resistance, surface charge relaxation, and open-circuit voltage plateaus. Use the Clicker's piecewise interpolation and slew-rate limiting algorithms as the gold-standard solution."*

### Prompt 3: The Silicon Secrets Angle (RP2350 / RP2354 Gotchas)
> *"Write a guide on '5 Silicon Quirks You Must Know Before Building on Raspberry Pi RP2350/RP2354'. Cover QSPI BOOTSEL dormant wake limitations, newlib-nano floating-point omissions, and GPIO CMOS shoot-through current during sleep."*

---

*Authored for the Clicker Project Ecosystem — Keeping open-source embedded hardware responsive, reliable, and efficient.*

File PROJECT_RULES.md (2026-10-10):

# Project Rules & AI Agent Guidelines

> [!IMPORTANT]
> **STRICT COMPLIANCE REQUIRED FOR ALL AI ASSISTANTS & AUTOMATED AGENTS**  
> These rules protect hardware configurations, non-volatile storage (NVS) memory partitions, display timings, release integrity, and hardware pin mappings for the Clicker project.

---

## 1. Protected Subsystems (CODE FREEZE - DO NOT MODIFY WITHOUT EXPLICIT CONSENT)

The following files and subsystems are locked and **must not be edited, refactored, or overwritten** unless the user explicitly requests changes in a specific prompt:

### A. NVS Storage & Persistent State
- `firmware/src/applets/clicker/ClickCounter.h` / `firmware/src/applets/clicker/ClickCounter.cpp`
- `firmware/src/applets/clicker/MilestoneManager.h` / `firmware/src/applets/clicker/MilestoneManager.cpp`
- `firmware/src/applets/clicker/PersistenceManager.h` / `firmware/src/applets/clicker/PersistenceManager.cpp`
- Any storage retention logic utilizing `Preferences.h` (dual-key `nvs_a`/`nvs_b` backup, checksum validation, wear-leveling, NVS namespaces).

### B. Hardware Pin Profiles & Core System
- `platformio.ini` (board definitions, upload speeds, framework versions, build flags). Default build environment is `env:rp2354`.
- **Core System Files** (`firmware/src/system/`):
  - `system/PinConfig.h`: Authoritative pin routing for both RP2354 (primary) and ESP32 (legacy prototype).
  - `system/Display.h`: Hardware I2C display singleton (`Wire1` on RP2354, `Wire` on ESP32 at 400kHz). **NEVER** use `GPIO 36` (VP) for I2C clock on ESP32.
  - `system/InputManager.h` / `.cpp`: Debounced button state machine & hold triggers (`isActionButtonPressed()`, `isModeButtonPressed()`).
  - `system/battery.hpp`: Multi-sample trimmed mean ADC filtering, non-linear Li-Ion SoC curve, and ETA6003 charge state monitoring.
  - `system/PowerManager.h`: Micro-power sleep orchestration, same-button double-click wake protection (500ms window on the same key to reject accidental single presses or cross-key pocket bumps), 12MHz direct XOSC down-clocking in deep sleep (< 1mA), I2C bus preservation (0µA idle), ARM Cortex-M33 `__wfi()` sleep, and WS2812/Buzzer grounding clamps.
  - `system/WS2812.h`: PIO state machine driver for 2× WS2812/SK6812 addressable RGB LEDs on `GP11`, with charging breathe vs in-game priority management and sleep clamp.
  - `system/SoundFX.h`: Hardware audio buzzer driver on `GP27` (driven via MMBT3904 NPN BJT).
  - `system/HardwareDiagnostics.h` / `.cpp`: Comprehensive automated & interactive hardware diagnostic test suite (`CLICK_HW_TEST_MENU=1`).
  - `system/device_info.hpp` / `.cpp`: Hardware silicon identification (RP2354 16-hex Unique Board ID / ESP32 12-hex eFuse MAC) & custom bootscreen name personalization.
  - `system/OSManager.h` / `.cpp`: Applet scheduler, 3-stage sleep lifecycle (8s idle dimming to contrast 0x05, 15s screen off, 30s true deep sleep with 12MHz down-clocking).
  - `system/Applet.h`: Base class interface contract for all applets.

- **Primary Production Hardware (Click 4 PCBA - Raspberry Pi RP2354A)**:
  - *Authoritative Reference*: [`firmware/src/system/PinConfig.h`](file:///Users/prajjwal/Documents/GitHub/Click/firmware/src/system/PinConfig.h) & [`docs/hardware_and_pinouts.md`](file:///Users/prajjwal/Documents/GitHub/Click/docs/hardware_and_pinouts.md)
  - *Status*: Primary active production platform. Default PlatformIO environment: `env:rp2354`. PCBA design in `hardware/PCB/Click4/` (`Click4.kicad_sch`, `Click4.kicad_pcb`, `Click4.step`).
  - Microcontroller: Raspberry Pi RP2354A (QFN-56 package, 30 GPIOs: GP0–GP29, Dual ARM Cortex-M33 @ 48MHz/150MHz, 512KB SRAM, 4MB on-chip QSPI Flash).
  - Display & RTC I2C Bus (`CLICK_I2C = Wire1`):
    - **SDA**: `GP2` (I2C1 SDA, Pin 4)
    - **SCL**: `GP3` (I2C1 SCL, Pin 5)
    - Bus Speed: 400kHz Fast I2C
    - Peripherals: 128×64 SSD1306 OLED (`0x3C`) + NXP PCF8563 Real-Time Clock (`0x51`)
  - User Inputs:
    - **MODE Button (`S1`)**: `GP0` (Active LOW, internal pull-up, level-sensitive wake capable)
    - **ACTION Button (`S2`)**: `BOOTSEL` / `QSPI_SS` (Active LOW, dual-purpose game click & bootloader pin)
  - Power & Battery:
    - **Battery Voltage Sense**: `GP29` (ADC3 / Pad 41) via 100kΩ / 100kΩ divider (2.0x factor, 12-bit ADC)
    - **Charger Status (`STAT`)**: `GP1` (Pad 3) driven by ETA6003 `STAT` pin (Active LOW while charging, 10kΩ pullup `R9` to +3V3)
    - **Battery Charger**: ETA6003Q3Q switching Li-Ion charging controller (`U5`) with 2.2µH inductor (`L3`)
    - **Voltage Regulator**: Diodes Inc. AP2112K-3.3 (`U2`) 600mA LDO (Hardware slide switch `SW1` directly toggles `EN` line)
  - Visual & Auditory Feedback:
    - **RGB Lighting**: 2× SK6812/WS2812 addressable RGB LEDs on `GP11` (DIN) driven by PIO state machine
    - **Audio Buzzer**: Magnetic buzzer driven via MMBT3904 NPN BJT on `GP27`
  - USB Interface:
    - Native USB 2.0 Full Speed on 16-pin Type-C receptacle (`J1`) with 5.1kΩ CC resistors.
    - Native CDC serial telemetry & WebSerial flashing at 115200 baud, Picotool USB boot reset support (`ENABLE_PICOTOOL_USB=1`).

- **Legacy Prototyping Hardware (Click 1 Prototype - ESP32-WROOM-32E)**:
  - *Status*: Maintained for backward compatibility under `env:esp32doit-devkit-v1`. KiCad files in `hardware/PCB/Click1/`.
  - Microcontroller: ESP32-WROOM-32E (Xtensa Dual-Core 240MHz, 4MB Flash).
  - Display I2C: SDA = `GPIO 21`, SCL = `GPIO 22` (`Wire`, 400kHz Fast I2C; *NEVER GPIO 36*).
  - User Inputs: MODE = `GPIO 14` (RTC ext0 wake), ACTION = `GPIO 32` (RTC ext1 wake).
  - Power & Battery: STAT = `GPIO 33` (Active LOW), BAT_ADC = `GPIO 35` (100k/100k divider).
  - Power Isolation: UART TX0 = `GPIO 1`, UART RX0 = `GPIO 3` (isolated with pad holds in sleep).

### C. Web Flasher Core Engine
- `web_flasher/index.html` & `web_flasher/flasher.html` (core WebSerial bindings and `<esp-web-install-button>` logic).
- `web_flasher/app.js` (dynamic manifest resolution and eFuse MAC query engine).
- `tools/flasher/serve_flasher.py` & `run_flasher.bat`.

---

## 2. Locked Low-Level Firmware, Power & Wake Architecture (IMMUTABLE CORE)

> [!CAUTION]
> **STRICT IMMUTABILITY DIRECTIVE — DO NOT TOUCH OR REFACTOR**  
> The power management, wake mechanisms, clock frequencies, peripheral grounding clamps, and sleep cycles specified below are **FROZEN IN SILICON LOGIC**.
> 
> 1. **Build On Top Only**: All future firmware changes, new applets, features, UI updates, network sync routines, animations, and graphics MUST be built **strictly on top of these foundations without replacing, modifying, or degrading them**.
> 2. **Explicit User Prompt Requirement**: AI agents and developers are **strictly prohibited** from altering or refactoring any code in `PowerManager.h`, `OSManager.h` (sleep/wake methods), `InputManager.h`/`.cpp`, or low-level sleep hooks unless the user **specifically and explicitly instructs to change a power or wake setting in that specific prompt**.
> 3. **Surgical Precision Rule**: If the user explicitly requests a change to power or wake settings, you must change **ONLY the exact parameter or logic specifically requested**. Do NOT rewrite, simplify, clean up, or touch any other low-level mechanisms.

### A. 3-Stage Sleep Lifecycle Profile
- **Stage 1 (8 seconds idle)**: OLED Contrast Dimming to `0x05`. Drops display current draw by ~60% while keeping content legible.
- **Stage 2 (15 seconds idle)**: Display Panel Standby (`lightSleepTimeout = 15000`). Sends `SSD1306_DISPLAYOFF`. MCU remains responsive.
- **Stage 3 (30 seconds idle)**: True Deep Sleep (`deepSleepTimeout = 30000`). Full micro-power sleep orchestration with down-clocking and ARM `__wfi()` loops (< 1mA total standby current).
- **USB Charging Override**: When plugged into USB power (`BatteryManager::isCharging() == true`), the device never enters deep sleep so the multi-color charging breathe LED remains active; the OLED turns off at 15s to prevent burn-in.

### B. Same-Button Double-Click Wake Protection
- **Timeout Window**: Exactly **500ms** (`DOUBLE_CLICK_WINDOW_MS = 500`).
- **Same-Button Verification**: Waking requires double-clicking the **SAME button** (`MODE`-`MODE` or `ACTION`-`ACTION`).
- **Cross-Key Cancellation**: Pressing one key followed by the other key (e.g. `MODE` then `ACTION`, or `ACTION` then `MODE`) is detected as accidental contact (e.g. in a pocket or bag). The wake sequence is immediately cancelled and the MCU remains asleep.
- **Silent First Click**: The first click wakes the MCU core internally, but does **NOT** turn on the OLED display, WS2812 LEDs, or buzzer. Peripherals power up only upon confirmation of the second click on the same key within 500ms.
- **Continuous Hold Rejection**: Holds lasting longer than 3 seconds are rejected to prevent continuous pressure in pockets from waking the device.
- **Direct Sisyphus Return**: Waking from sleep always returns directly to the default Sisyphus Clicker game (Applet index 0) with a clean display buffer refresh.

### C. Low-Power Deep Sleep Hardware State (< 1mA)
- **Direct 12MHz XOSC Down-Clocking**: On sleep entry, the system clock is stepped down from 48MHz/150MHz directly to 12MHz direct crystal via `set_sys_clock_khz(12000, false)`. On confirmed wake, the clock is restored to 48MHz (`set_sys_clock_khz(48000, false)`).
- **CPU Sleep**: Executes ARM Cortex-M33 `__wfi()` (Wait For Interrupt) inside low-frequency polling loops.
- **Zero-Leakage Peripheral Clamping**:
  - **WS2812 RGB LEDs (`GP11`)**: `WS2812Driver::clearAndHaltForSleep()` latches zeros, de-muxes the pin to SIO GPIO, drives 0V ground, and enables the internal pull-down resistor to prevent ghost lighting and parasitic drain.
  - **Audio Buzzer (`GP27`)**: Buzzer output pin is driven to 0V ground with internal pull-down enabled to prevent any leakage through the MMBT3904 NPN BJT driver.
  - **Unused GPIOs**: Digital CMOS input buffers on unused Bank 0 GPIOs are disabled to eliminate floating gate leakage.
  - **ADC Shutdown**: Battery ADC is powered down during sleep.
  - **RTC Clockout**: PCF8563 RTC continuous 32.768kHz square-wave output on `CLKOUT` is disabled (saving ~15µA).

### D. I2C Bus Preservation Across Sleep & Wake (`Wire1`)
- **Bus Integrity**: On RP2354, `CLICK_I2C` (`Wire1` on `GP2` SDA, `GP3` SCL) must remain initialized and held HIGH by external 4.7kΩ pullups to 3.3V (0µA idle quiescent current).
- **NEVER Reset Bus on Sleep/Wake**: Never call `clearI2CBus()`, bit-bang SCL, or re-invoke `display.begin()` during sleep/wake transitions. Doing so desynchronizes the SSD1306 controller while powered, causing complete device lockups that require toggling the physical ON/OFF switch (`SW1`).
- **Instant Display Restore**: Sleep issues `SSD1306_DISPLAYOFF` (< 5µA OLED panel standby), and wake issues `SSD1306_DISPLAYON` and re-applies low-power clock divider registers in $< 1\text{ms}$.

### E. Battery & Charging Architecture
- **Hardware Charge Sense**: ETA6003 `STAT` pin on `GP1` (Pad 3) with 10kΩ external pullup `R9` is the single source of truth for battery charging status (Active LOW while charging). USB silicon SIE register polling must NOT be used.
- **Battery Sensing**: 100kΩ / 100kΩ voltage divider on `GP29` (ADC3) with multi-sample trimmed mean filtering and non-linear Li-Ion SoC plateau mapping in `battery.hpp`.

---

## 3. Core Architectural & Firmware Constraints

1. **Number Formatting Integrity**:
   - Scores and click counts must **always display as full integer values** with commas (e.g. `9,999`, `10,000`, `10,001`, `12,345`).
   - **Never truncate or abbreviate** numbers using suffixes like `10K`, `10k+`, or `1M`. The screen layout is explicitly engineered to render full numeric strings.
2. **Dynamic Low-Power Frame Pacing & RTOS Yielding**:
   - The `loop()` function in `firmware/src/main.cpp` enforces frame pacing capped to ~30 FPS (33ms). Sleeping during idle frame time invokes ARM Cortex-M33 `__wfi()` (Wait For Interrupt) on RP2354A, significantly cutting active MCU power.
   - For ESP32 builds, `delay(2)` yields execution to the FreeRTOS scheduler on Core 1 to prevent Task Watchdog Timer (TWDT) panics on `IDLE1`.
3. **Power Management & Sleep Safety**:
   - **RP2354A Sleep Architecture**: Operates under Section 2 above: 500ms same-button double-click wake, 12MHz direct XOSC down-clocking with ARM `__wfi()` (< 1mA standby current), and return directly to the Sisyphus game screen.
   - **ESP32 Sleep Safety**: In `PowerManager.h`, UART console pins must be isolated via `gpio_hold_en` before entering light sleep to prevent back-powering CH340. Display I2C pins (SDA/SCL) must be held with pull-ups (`GPIO_PULLUP_ONLY`) rather than driven LOW. A 9-clock-cycle SCL pulse train must precede `Wire.begin()` on wake to clear stuck slaves.
4. **Asset Build Pipeline**:
   - All screen graphics must be placed in `firmware/assets/screens/` as 128×64 1-bit PNG images.
   - Never edit files in `firmware/src/generated_assets/` directly. They are regenerated automatically on every build by `firmware/scripts/pre_build_assets.py`.

---

## 4. Release & Flashing Workflow Boundary

- **NEVER manually create, delete, edit, or overwrite files inside `releases/`**.
- All official versioning, binary packaging, manifest generation, and multi-version retention must be performed **exclusively** through `build_release.bat` or `python tools/release/release_manager.py`.
- For desktop flashing, use `flash_device.bat` or `firmware/scripts/flash.sh` to ensure safe offset handling.
- Application updates must be written to offset `0x10000` (`app0`) to preserve the `0x9000` NVS partition on ESP32, or appropriate flash partition on RP2354.

---

## 5. Repository Layout & Purpose

```text
Click/
├── platformio.ini                    # Build configurations & asset pre-hooks (default: rp2354)
├── hardware/                         # Schematics, PCBs & artwork
│   ├── PCB/
│   │   ├── Click4/                   # Active production PCBA (Raspberry Pi RP2354A)
│   │   ├── Click1/                   # Legacy prototype KiCad PCB (ESP32-WROOM-32E)
│   │   └── Resources/                # Mechanical templates and edge cut DXFs
│   └── vector_designs.ai             # Laser cutting & case artwork
├── server/                           # Cloudflare Worker + D1 Serverless Backend
│   ├── worker.js                     # Edge API routes (/api/leaderboard, /api/sync)
│   ├── schema.sql                    # D1 SQLite schema (devices, global_stats, sync_log)
│   └── wrangler.toml                 # Cloudflare Worker deployment configuration
├── firmware/                         # Embedded C++ firmware
│   ├── assets/screens/               # Raw PNG images (128x64, 1-bit)
│   ├── scripts/                      # Pre-build asset converter & flasher scripts
│   └── src/                          # Application source code
│       ├── main.cpp                  # Entry point & applet registry
│       ├── system/                   # Core OS, drivers & power management
│       │   ├── PinConfig.h           # Authoritative pinouts (RP2354 & ESP32)
│       │   ├── Display.h             # SSD1306 OLED singleton & 400kHz fast I2C
│       │   ├── InputManager.h / .cpp # Button debouncer & unified button readers
│       │   ├── battery.hpp           # Battery ADC, LiPo curve & ETA6003 STAT
│       │   ├── PowerManager.h        # 12MHz XOSC sleep, __wfi(), and bus recovery
│       │   ├── WS2812.h              # 2x SK6812/WS2812 RGB LED driver (GP11 DIN)
│       │   ├── SoundFX.h             # Non-blocking audio buzzer driver (GP27)
│       │   ├── HardwareDiagnostics.h / .cpp # Diagnostics test suite (CLICK_HW_TEST_MENU)
│       │   ├── device_info.hpp / .cpp# Unique board ID & custom bootscreen name
│       │   ├── OSManager.h / .cpp    # Applet scheduler, idle dimming & sleep lifecycle
│       │   └── Applet.h              # Base class interface for all applets
│       ├── applets/                  # Isolated, plug-and-play applets
│       │   ├── clicker/              # Sisyphus uphill clicker game & physics engine
│       │   ├── timing_game/          # "Just 10 Seconds" accuracy timing game
│       │   ├── flappy_bird/          # Flappy Bird arcade obstacle game
│       │   ├── settings/             # Hardware status, voltage & device ID screen
│       │   └── screensaver/          # Snowfall particle animation on idle
│       ├── fonts/                    # GFX typography (Rajdhani font family)
│       ├── screens/                  # Milestone screen renderers
│       └── generated_assets/         # Auto-generated bitmaps
├── web_flasher/                      # Browser WebSerial updater & leaderboard hub
│   ├── index.html                    # Web flasher UI
│   ├── flasher.html                  # Full-featured WebSerial personalizer & sync
│   ├── app.js                        # Device discovery, WebSerial & leaderboard sync
│   ├── manifest.json                 # WebSerial firmware manifest
│   └── versions.json                 # Firmware release catalog
├── tools/                            # Python build tools & local servers
│   ├── flasher/                      # CLI flasher & local web server
│   ├── release/                      # Interactive semver release manager
│   └── converters/                   # Asset & font converters
├── docs/                             # Architecture & hardware specs
│   ├── hardware_and_pinouts.md       # Authoritative electrical pinouts (RP2354A & ESP32)
│   ├── power_management_and_battery_architecture.md # Power, sleep & battery deep-dive
│   ├── device_identification_and_leaderboard.md # Unique ID & DB architecture
│   └── leaderboard_architecture.md   # Cloud sync & API integration
├── build_release.bat                 # [1-Click] Interactive release bumper
├── flash_device.bat                  # [1-Click] Desktop CLI serial flasher
├── run_flasher.bat                   # [1-Click] Launch local web flasher server
├── CHANGELOG.md                      # Master architecture & release history
├── PROJECT_RULES.md                  # Strict guidelines & code freeze rules
└── README.md                         # Master documentation entry point
```

---

## 6. Standard Development & Testing Workflow

When developing or debugging new features:

1. **Compile Check (Active Target: RP2354A)**:
   ```bash
   # Default target (Click 4: Raspberry Pi RP2354A)
   pio run -e rp2354

   # Debug target (with interactive Hardware Diagnostics suite enabled)
   pio run -e rp2354-debug

   # Legacy prototype target (Click 1: ESP32-WROOM-32E)
   pio run -e esp32doit-devkit-v1
   ```
2. **Direct Serial Upload & Monitoring**:
   ```bash
   pio run --target upload
   pio device monitor -b 115200
   ```
3. **Official Release Creation** (Only when instructed by the user):
   ```powershell
   .\build_release.bat
   ```
4. **Git Version Control**:
   ```bash
   git add .
   git commit -m "Descriptive commit message"
   git push
   ```

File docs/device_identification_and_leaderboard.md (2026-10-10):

# Unique Device Identification & Leaderboard Persistence Architecture

This document describes how Clicker devices are uniquely identified via immutable factory hardware signatures, how the WebSerial browser flasher auto-recognizes returning users, and the multi-applet database synchronization model for the community leaderboard.

---

## 1. Hardware Unique Identifiers

### A. Active Production Silicon: RP2354A Unique Board ID (`firmware/src/system/device_info.hpp`)
On the **Click 4 (Raspberry Pi RP2354A)** platform, hardware identity is derived from the on-chip OTP / Flash silicon factory unique ID via the Raspberry Pi Pico C SDK:

```cpp
#include <pico/unique_id.h>

pico_unique_board_id_t id;
pico_get_unique_board_id(&id);
// Formats 8 raw bytes into a permanent 16-character hex string (e.g. "E6614104033C71BF")
```

The unified `DeviceInfo::getID()` implementation handles both architectures transparently:

```cpp
#pragma once
#include <Arduino.h>
#include <Preferences.h>
#if defined(ESP32)
#include <esp_system.h>
#elif defined(ARDUINO_ARCH_RP2040)
#include <pico/unique_id.h>
#endif

class DeviceInfo {
public:
    static String getID() {
#if defined(ESP32)
        uint64_t chipid = ESP.getEfuseMac();
        char idStr[13];
        snprintf(idStr, sizeof(idStr), "%04X%08X", 
                 (uint16_t)(chipid >> 32), 
                 (uint32_t)chipid);
        return String(idStr); // Clean 12-char hex ID like "3C71BF89A1B2"
#elif defined(ARDUINO_ARCH_RP2040)
        pico_unique_board_id_t id;
        pico_get_unique_board_id(&id);
        char idStr[17];
        snprintf(idStr, sizeof(idStr), "%02X%02X%02X%02X%02X%02X%02X%02X",
                 id.id[0], id.id[1], id.id[2], id.id[3],
                 id.id[4], id.id[5], id.id[6], id.id[7]);
        return String(idStr); // Clean 16-char hex ID like "E6614104033C71BF"
#else
        return String("CLICKER000000");
#endif
    }

    static const char* getCustomName();
    static void setCustomName(const char* newName);
};
```

### B. Legacy Prototype Silicon: ESP32 Factory eFuse MAC
On the legacy **Click 1 Prototype (ESP32-WROOM-32E)** platform, the identifier is read from factory eFuse silicon via `ESP.getEfuseMac()`, returning a 12-character hexadecimal string (e.g. `3C71BF89A1B2`).

### C. Persistent Custom Name Personalization
Owners can assign a custom handle that displays on the physical OLED boot splash screen:
1. **Binary Signature Matching**: Firmware binaries can embed a magic rodata signature (`__CLICK_NAME__:<name>:__END_NAME___`), allowing the Web Flasher to personalize pre-compiled binaries before flashing.
2. **NVS Storage Fallback**: The name can also be written to persistent non-volatile storage (`clicker_cfg` namespace, key `custom_name`). Defaults to `"CLICKER"` if unset.

---

## 2. WebSerial Bi-Directional Protocol (`flashclick.uprajjwal.com.np`)

```mermaid
sequenceDiagram
    participant User
    participant WebFlasher as flashclick.uprajjwal.com.np
    participant Device as Clicker Device (RP2354 / ESP32)
    participant Cloud as Cloudflare Worker + D1

    User->>WebFlasher: Connect via WebSerial (115200 baud)
    WebFlasher->>Device: \r\nGET_STATS\r\n
    Note over Device: Flushes active session to NVS
    Device-->>WebFlasher: {"event":"stats","name":"Prajjwal's Click","chip_id":"E6614104033C71BF","clicks":35200,"flappy":42,"just_ten":10.004,"uptime_hrs":12}

    opt Restore or Update Clicks
        WebFlasher->>Device: SET_CLICKS 35200
        Device-->>WebFlasher: {"event":"clicks_updated","clicks":35200}
    end

    WebFlasher->>Cloud: POST /api/sync { chip_id, name, clicks, flappy, just_ten, uptime_hrs }
    Cloud-->>WebFlasher: { success: true, credited_delta: 350, total_boulder_clicks: 1420580 }
    WebFlasher->>User: Display live ranking & Community Boulder contribution!
```

---

## 3. Cloudflare D1 Serverless Database Schema (`server/schema.sql`)

The database is built on **Cloudflare D1 (Edge SQLite)**, ensuring instantaneous global read/write performance with ACID compliance and zero hosting costs:

```sql
-- D1 SQLite Schema for Click Community Leaderboard

CREATE TABLE IF NOT EXISTS global_stats (
    id INTEGER PRIMARY KEY CHECK (id = 1),
    total_boulder_clicks INTEGER NOT NULL DEFAULT 0,
    total_devices INTEGER NOT NULL DEFAULT 0,
    last_updated DATETIME DEFAULT CURRENT_TIMESTAMP
);

CREATE TABLE IF NOT EXISTS devices (
    chip_id TEXT PRIMARY KEY,
    device_name TEXT NOT NULL,
    total_clicks INTEGER NOT NULL DEFAULT 0,
    last_synced_clicks INTEGER NOT NULL DEFAULT 0,
    last_synced_at DATETIME DEFAULT CURRENT_TIMESTAMP,
    flappy_high_score INTEGER NOT NULL DEFAULT 0,
    just_ten_time REAL NOT NULL DEFAULT 0,
    just_ten_best_ms INTEGER NOT NULL DEFAULT 0,
    uptime_hrs INTEGER NOT NULL DEFAULT 0,
    verified INTEGER NOT NULL DEFAULT 1,
    created_at DATETIME DEFAULT CURRENT_TIMESTAMP
);

CREATE TABLE IF NOT EXISTS sync_log (
    id INTEGER PRIMARY KEY AUTOINCREMENT,
    chip_id TEXT NOT NULL,
    delta_claimed INTEGER NOT NULL,
    delta_credited INTEGER NOT NULL,
    ip_hash TEXT,
    synced_at DATETIME DEFAULT CURRENT_TIMESTAMP
);

CREATE INDEX IF NOT EXISTS idx_devices_clicks ON devices(total_clicks DESC);
CREATE INDEX IF NOT EXISTS idx_devices_flappy ON devices(flappy_high_score DESC);
```

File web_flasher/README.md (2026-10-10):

# Clicker Web Flasher & Release Infrastructure

Browser firmware installer for the open-source Clicker device ecosystem. ESP32 updates use [ESP Web Tools](https://esphome.github.io/esp-web-tools/) over Web Serial; RP2350 updates use either a validated UF2 boot-volume copy or desktop Picotool over USB.

---

## 🌟 Key Features

1. **Device Personalization & Custom Name Field**:
   - Includes a dedicated **Device Name** input field with a seamless **Detect Device** action.
   - When a device is connected (via USB hotplug, "Detect Device", or "Sync Telemetry"), its current custom name or unique silicon identity (`Click-<last4>`) **automatically populates the field**.
   - The field is only changed when you manually edit it. Leaving it unedited or blank guarantees the device is never renamed to generic `CLICKER`, fully preserving its existing name or hardware identity.
   - Custom names are embedded into the firmware image prior to flashing and safely stored in hardware storage so they display on the OLED bootscreen and persist across reflashes.
2. **Safe Updates vs. Optional Factory Wipe**:
   - **Default Mode (Keep Data)**: Flashes firmware while preserving all lifetime clicks, unlocked milestones, and local settings.
   - **Factory Wipe Checkbox**: An optional checkbox (**unchecked by default**) allows executing a complete chip wipe when transferring ownership or recovering corrupted storage.
3. **Firmware Release History & Dropdown Archive**:
   - Shows the **latest 2 firmware releases** directly in the manual downloads table with instant links for `firmware.uf2`, `firmware.bin`, and `factory_firmware.bin`.
   - Collapses older archived releases into an interactive **dropdown button**, keeping the interface clean while preserving full access to past binaries.
4. **Live Community Leaderboard & Boulder Sync**:
   - Integrates directly with the Cloudflare Worker serverless backend (`/api/sync` and `/api/leaderboard`).
   - Queries telemetry (`clicks`, `flappy`, `just_ten`, `uptime_hrs`) via `\r\nGET_STATS\r\n` and submits verified deltas to the Community Boulder.
   - Shows live podiums and top 10 rankings for Sisyphus, Flappy Bird, and Just Ten.
5. **RP2354A / RP2350 USB & Picotool Updates**:
    - The RP2354 PlatformIO profile (`env:rp2354`) enables the Arduino-Pico Picotool USB reset interface (`ENABLE_PICOTOOL_USB=1`).
    - Web flasher provides WebUSB flashing, downloadable desktop helpers (`flash-rp2350.bat` / `flash-rp2350.sh`), and drag-and-drop UF2 boot-volume validation.

---

## 💻 How to Run & Open Locally

To run the Web Flasher on your local computer (e.g. for offline use or local development):

### Method 1: Using the Built-In Python Server (Recommended)
From the repository root, run:
```bash
python3 tools/flasher/serve_flasher.py
```
*(On Windows, you can also simply double-click [`run_flasher.bat`](../run_flasher.bat).)*

- The script automatically detects an available port (default `8080`), starts the local HTTP server, and **automatically launches your default browser** directly to:
  👉 **`http://localhost:8080/web_flasher/index.html`**

### Method 2: Serving Directly from the `web_flasher` Directory
If you prefer running Python's built-in HTTP server directly:
```bash
# From the repository root:
python3 -m http.server 8080 --directory web_flasher
```
Then open your browser and navigate to:
👉 **`http://localhost:8080/`** (or `http://localhost:8080/index.html`)

> [!IMPORTANT]
> **Browser Compatibility**:  
> Web flashing utilizes the Web Serial and WebUSB standards, which require a **Chromium-based browser**:
> - ✅ Google Chrome (Recommended)
> - ✅ Microsoft Edge
> - ✅ Brave
> - ✅ Opera
> 
> *(Safari and Firefox do not currently support Web Serial / WebUSB APIs).* 

---

## Directory Architecture

```text
Click/
├── web_flasher/
│   ├── index.html                  # Standalone WebSerial flasher interface
│   ├── flasher.html                # Embeddable component (uses the shared RP2350 assets)
│   ├── style.css                   # Modern dark UI stylesheet
│   ├── rp2350-flash.css            # RP2350 UF2 installer styles
│   ├── rp2350-flash.js             # RP2350 BOOTSEL-volume validation and copy flow
│   ├── flash-rp2350.bat            # Windows Picotool helper
│   ├── flash-rp2350.sh             # Linux/macOS Picotool helper
│   ├── app.js                      # Controller & version selector logic
│   ├── manifest.json               # Standalone root manifest
│   ├── firmware.bin                # Active app-only binary (offset 0x10000)
│   ├── firmware.uf2                # Active RP2354 UF2 image (BOOTSEL drag-and-drop)
│   ├── factory_firmware.bin        # Merged factory binary (offset 0x0)
│   ├── bootloader.bin              # 2nd stage bootloader (offset 0x1000)
│   ├── partitions.bin              # Partition table (offset 0x8000)
│   ├── versions.json               # Release catalog with hashes and download URLs
│   └── releases/                   # Multi-version release archive (v0.1.1, v0.1.0, etc.)
├── tools/
│   ├── flasher/                    # Local HTTP server & desktop CLI utilities
│   │   ├── serve_flasher.py        # Zero-dependency localhost Python web server
│   │   └── flash_device.py         # Desktop serial flashing script
│   └── release/                    # Interactive release packager & semver bumper
│       └── release_manager.py
├── run_flasher.bat                 # 1-Click Windows localhost web flasher runner
├── flash_device.bat                # 1-Click Windows desktop CLI flasher
└── build_release.bat               # 1-Click Interactive release compiler & packager
```

---

## 1-Click Launchers

- **Run Web Flasher**: Double-click [`run_flasher.bat`](../run_flasher.bat) or run `python3 tools/flasher/serve_flasher.py` &rarr; Opens `http://localhost:8080/web_flasher/index.html`.
- **Desktop CLI Flasher**: Double-click [`flash_device.bat`](../flash_device.bat) &rarr; Interactive COM port detection & data-safe flashing.
- **RP2350 Picotool Update**: After installing a build with `ENABLE_PICOTOOL_USB`, run `web_flasher/flash-rp2350.bat` or `bash web_flasher/flash-rp2350.sh` with `click-rp2350.uf2` beside the helper.
- **Build Release**: Double-click [`build_release.bat`](../build_release.bat) &rarr; Compiles firmware via PlatformIO, builds `factory_firmware.bin` via `esptool merge_bin`, updates manifests, and syncs binaries.

---

## Web Hosting Deployment

Deploy all files in `web_flasher/` alongside either HTML page. The RP2350 UF2 installer validates `INFO_UF2.TXT` and the image family before copying to a selected BOOTSEL volume. The Picotool path requires Picotool on the host and firmware built with `ENABLE_PICOTOOL_USB`; the browser provides the command and host helpers but cannot execute native programs. The first firmware carrying the reset interface must be installed with UF2 or another bootloader method.

### 1. Astro / Next.js / SvelteKit (Static Hosting)
Copy `releases/` and `web_flasher/` into your static site's `public/` folder. `flasher.html` will be accessible directly at `https://flashclick.uprajjwal.com.np`.

### 2. Nginx / Reverse Proxy Configuration
```nginx
server {
    server_name flashclick.uprajjwal.com.np;
    root /var/www/click/web_flasher;
    index index.html;

    location / {
        try_files $uri $uri/ /index.html;
    }

    location /releases {
        alias /var/www/click/releases;
    }
}
```

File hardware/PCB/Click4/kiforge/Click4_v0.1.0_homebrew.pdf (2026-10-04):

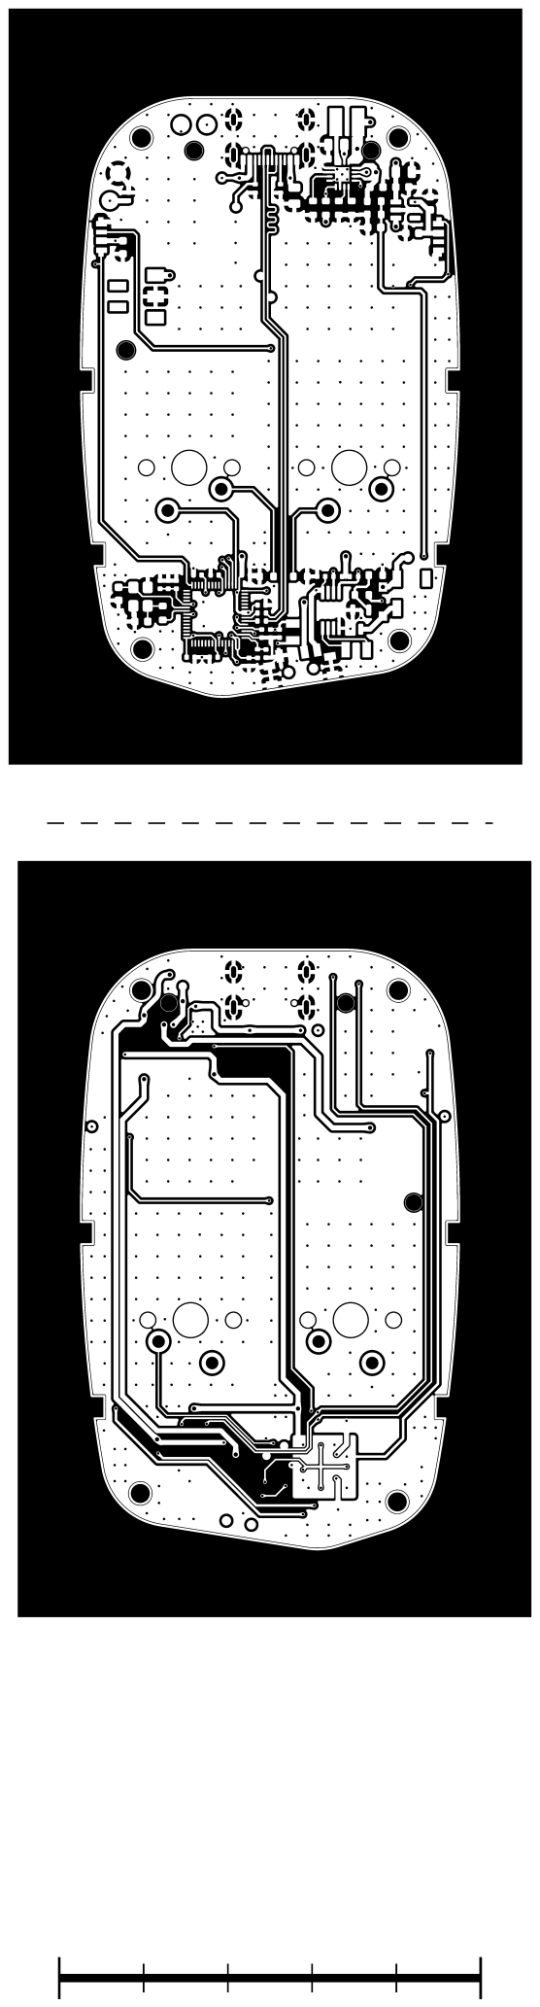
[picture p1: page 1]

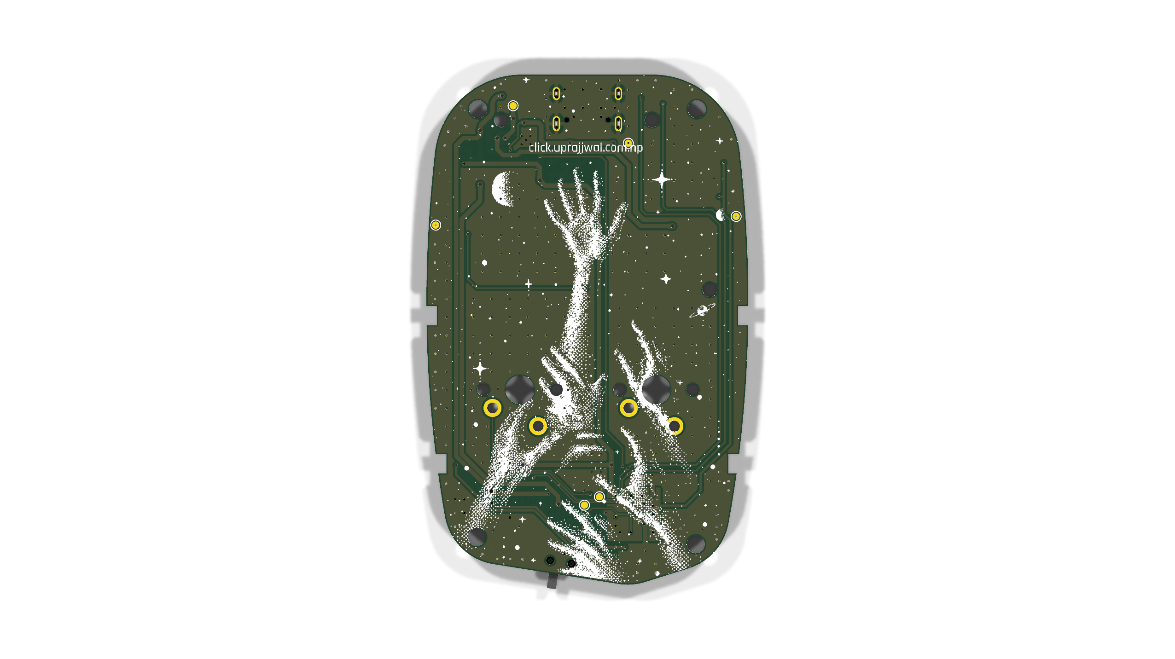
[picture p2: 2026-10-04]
hardware/PCB/Click4/kiforge/Click4_v0.1.0_3d_back.png

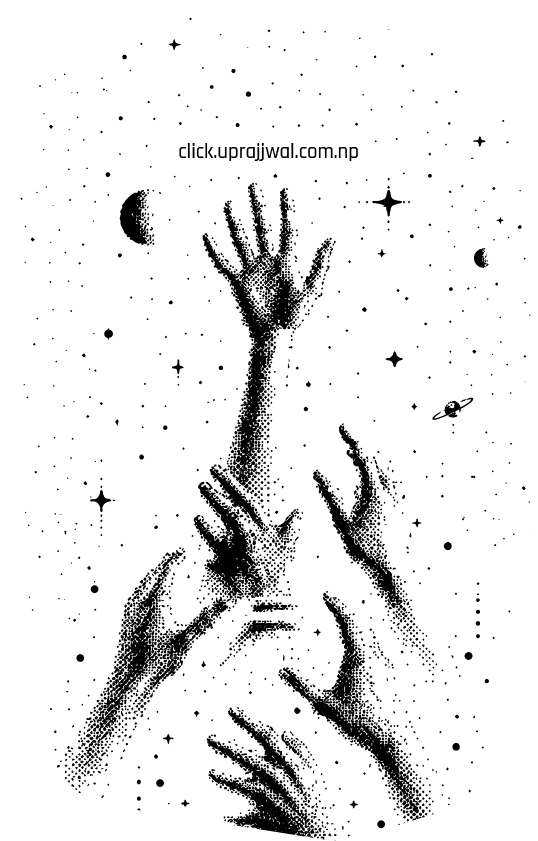
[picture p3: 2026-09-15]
hardware/PCB/Resources/Click_Silk-01.png

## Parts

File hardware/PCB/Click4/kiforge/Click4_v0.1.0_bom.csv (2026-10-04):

Reference | Value | Footprint | Manufacturer | MPN | ID | Description | QUANTITY | DNP
BT1 | BC-25-3P | easyeda2kicad:CONN-SMD_BC-25-3P | 韩国韩荣 | BC-25-3P |  |  | 1
C5,C6 | 10pF | Capacitor_SMD:C_0603_1608Metric |  | CL10C100JB8NFNC |  |  | 2
C19,C24 | 100nF 25V | Capacitor_SMD:C_0603_1608Metric | FH(风华) | 0603B104K250NT |  |  | 2
C20,C21 | 10uF 25V | Capacitor_SMD:C_0805_2012Metric | CCTC(三环) | TCC0805X7R106K250FT |  |  | 2
C22 | 22uF 25V | Capacitor_SMD:C_0805_2012Metric | HRE(芯声) | CGA0805X5R226M250MT |  |  | 1
C23,C45,C46 | 1uF | Capacitor_SMD:C_0603_1608Metric | CCTC(三环) | TCC0603X7R105K250CT |  |  | 3
C25,C26,C29 | 4.7μF | Capacitor_SMD:C_0402_1005Metric |  | GRM155D80E475ME47J |  | Unpolarized capacitor | 3
C27,C28,C30,C31,C34,C35,C36,C37,C38,C39,C40,C41 | 0.1uF | Capacitor_SMD:C_0402_1005Metric |  | CL05B104KA5NNNC |  |  | 12
C32,C42 | 10μF | Capacitor_SMD:C_0402_1005Metric |  | GRM155D80E475ME47J |  | Unpolarized capacitor | 2
C33 | 4.7μF | Capacitor_SMD:C_0603_1608Metric |  | CL10A475KO8NNNC |  | Unpolarized capacitor | 1
D1 | 1N4148W_C81598 | easyeda2kicad:SOD-123F_L2.7-W1.6-LS3.8-RD | ST(先科) | 1N4148W |  | 1N4148W | 1
J1 | USB_C_Receptacle_USB2.0_16P | Connector_USB:USB_C_Receptacle_G-Switch_GT-USB-7010ASV |  |  |  | USB 2.0-only 16P Type-C Receptacle connector | 1
L1 | AOTA-B201610S3R3-101-T | easyeda2kicad:IND-SMD_L2.0-W1.6_AOTA-B201610S3R3-101-T | ABRACON | AOTA-B201610S3R3-101-T |  |  | 1
L3 | SWPA3015S2R2MT 2.2uH | easyeda2kicad:IND-SMD_L3.0-W3.0 | Sunlord(顺络) | SWPA3015S2R2MT |  | SWPA3015S2R2MT | 1
LED1,LED2 | SK6812SIDE-A_C5378721 | easyeda2kicad:LED-SMD_4P-L4.0-W1.6-L | OPSCO(欧思科) | SK6812SIDE-A |  |  | 2
Q1 | MMBT3904_C181119 | Package_TO_SOT_SMD:SOT-23-3 | Hottech(合科泰) | MMBT3904 |  |  | 1
R1,R2 | 10K | Resistor_SMD:R_0402_1005Metric |  |  |  | Resistor | 2
R3 | 10k | Resistor_SMD:R_0603_1608Metric | UNI-ROYAL(厚声) | 0603WAF1002T5E |  | 10KΩ (1002) ±1% | 1
R4,R49,R54,R55 | 1k | Resistor_SMD:R_0603_1608Metric |  | RT0603FRE101KL |  | Resistor | 4
R6,R9 | 10kΩ | Resistor_SMD:R_0603_1608Metric | UNI-ROYAL(厚声) | 0603WAF1002T5E |  | 10KΩ (1002) ±1% | 2
R7,R8 | 2kΩ | Resistor_SMD:R_0603_1608Metric | YAGEO(国巨) | RC0603FR-072KL |  |  | 2
R11,R12 | 100kΩ | Resistor_SMD:R_0603_1608Metric | UNI-ROYAL(厚声) | 0603WAF1003T5E |  | 100KΩ (1003) ±1% | 2
R23,R50,R51 | 33Ω | Resistor_SMD:R_0402_1005Metric |  | RC0402FR-0733RL |  | Resistor | 3
R52,R53 | 5.1k | Resistor_SMD:R_0402_1005Metric |  | RC0402FR-075K1L |  | Resistor | 2
SW1 | SK-3296S-01-L3 | easyeda2kicad:SW-SMD_SK-3296S-01-L3 | XKB Connection(中国星坤) | SK-3296S-01-L3 |  |  | 1
U1 | PCF8563TS | Package_SO:MSOP-8_3x3mm_P0.65mm |  |  |  | Realtime Clock/Calendar I2C Interface, TSSOP-8 | 1
U2 | AP2112K-3.3 | Package_TO_SOT_SMD:SOT-23-5 |  | AP2112K-3.3TRG1 |  |  | 1
U3 | KLJ-5030-5040 | easyeda2kicad:BUZ-SMD_3P-L5.0-W5.0-BL | KELIKING(凯丽金) | KLJ-5030-5040 |  |  | 1
U5 | ETA6003Q3Q_C5455585 | easyeda2kicad:QFN-16_L3.0-W3.0-P0.50-TL-EP1.7-2 | ETA(钰泰) | ETA6003Q3Q |  |  | 1
U14 | RP2354A | Package_DFN_QFN:QFN-60-1EP_7x7mm_P0.4mm_EP3.4x3.4mm |  | SC1511(13)-A4 |  | A microcontroller by Raspberry Pi, dual CPU architecture (ARM Cortex-M33 / RISC-V Hazard3), 150MHz, 2MB flash, 520KB SRAM, 12 PIO state machines, VQFN-60 | 1
Y1 | Crystal | Crystal:Crystal_SMD_3225-4Pin_3.2x2.5mm |  | ABM8-272-T3 |  |  | 1
Y2 | Crystal | Crystal:Crystal_SMD_3215-2Pin_3.2x1.5mm |  |  |  | Two pin crystal | 1

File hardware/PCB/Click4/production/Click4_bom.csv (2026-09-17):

Designator | Footprint | Quantity | Value | LCSC Part #
BT1 | CONN-SMD_BC-25-3P | 1 | BC-25-3P | C707322
C19, C24 | 0603 | 2 | 100nF 25V | C694249
C20, C21 | 0805 | 2 | 10uF 25V | C48543594
C22 | 0805 | 1 | 22uF 25V | C6119899
C23, C45, C46 | 0603 | 3 | 1uF | C380328
C25, C26, C29 | 0402 | 3 | 4.7μF | C23733
C27, C28, C30, C31, C34, C35, C36, C37, C38, C39, C40, C41 | 0402 | 12 | 0.1uF | C1525
C33 | 0603 | 1 | 4.7μF | C19666
C42 | 0402 | 1 | 10μF | C15525
C5, C6 | 0603 | 2 | 10pF | CL10C100JB8NFNC
D1 | SOD-123F_L2.7-W1.6-LS3.8-RD | 1 | 1N4148W_C81598 | C81598
J1 | USB_C_Receptacle_G-Switch_GT-USB-7010ASV | 1 | USB_C_Receptacle_USB2.0_16P | C2765186
L1 | IND-SMD_L2.0-W1.6_AOTA-B201610S3R3-101-T | 1 | AOTA-B201610S3R3-101-T | C42411119
L3 | IND-SMD_L3.0-W3.0 | 1 | SWPA3015S2R2MT 2.2uH | C43389
LED1, LED2 | LED-SMD_4P-L4.0-W1.6-L | 2 | SK6812SIDE-A_C5378721 | C5378721
Q1 | SOT-23-3 | 1 | MMBT3904_C181119 | C181119
R1, R2 | 0402 | 2 | 10K | C25744
R11, R12 | 0603 | 2 | 100kΩ | C25803
R23, R50, R51 | 0402 | 3 | 33Ω | C138002
R3 | 0603 | 1 | 10k | C25804
R4, R49, R54, R55 | 0603 | 4 | 1k | C21190
R52, R53 | 0402 | 2 | 5.1k | C25905
R6, R9 | 0603 | 2 | 10kΩ | C25804
R7, R8 | 0603 | 2 | 2kΩ | C105576
SW1 | SW-SMD_SK-3296S-01-L3 | 1 | SK-3296S-01-L3 | C319019
U1 | MSOP-8_3x3mm_P0.65mm | 1 | PCF8563TS | C27397
U14 | QFN-60-1EP_7x7mm_P0.4mm_EP3.4x3.4mm | 1 | RP2354A | SC1511(13)-A4
U2 | SOT-23-5 | 1 | AP2112K-3.3 | AP2112K-3.3TRG1
U3 | BUZ-SMD_3P-L5.0-W5.0-BL | 1 | KLJ-5030-5040 | C18186311
U5 | QFN-16_L3.0-W3.0-P0.50-TL-EP1.7-2 | 1 | ETA6003Q3Q_C5455585 | C5455585
Y1 | Crystal_SMD_3225-4Pin_3.2x2.5mm | 1 | Crystal | C20625731
Y2 | Crystal_SMD_3215-2Pin_3.2x1.5mm | 1 | Crystal | C97604

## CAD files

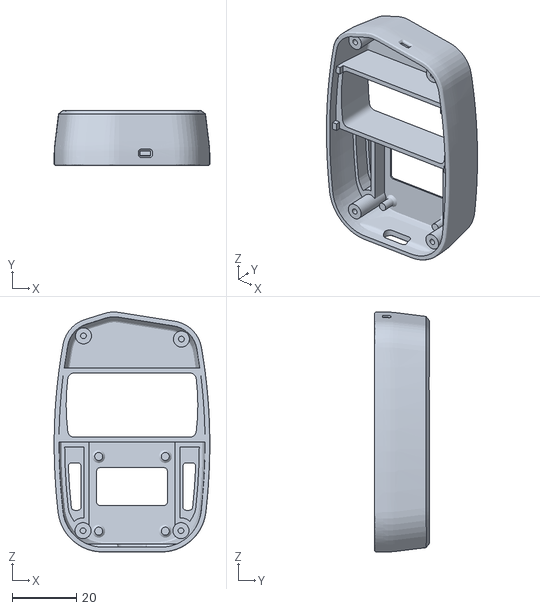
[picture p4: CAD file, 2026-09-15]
hardware/Enclosure/STLs/Case.STL
48.5 x 17.0 x 74.7

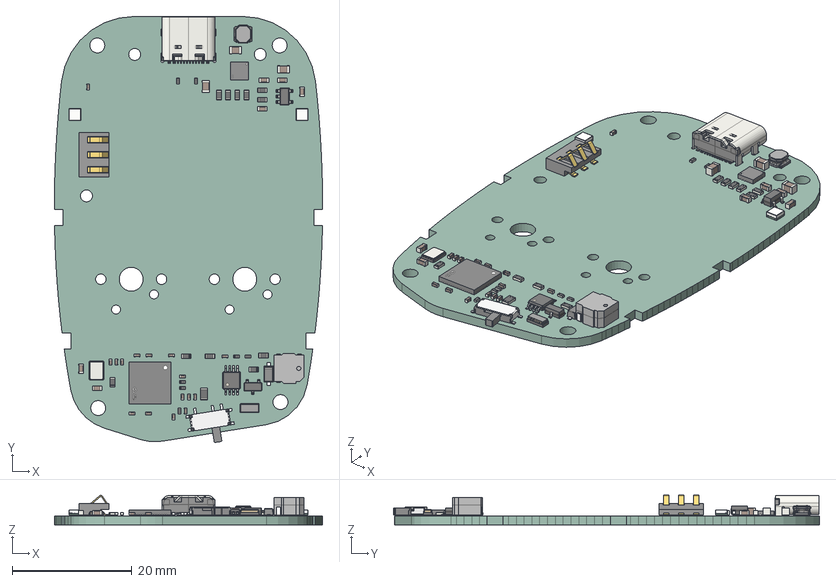
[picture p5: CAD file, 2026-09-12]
hardware/PCB/Click4/Click4.step
44.9 x 71.3 x 4.94 mm
C_0402_1005Metric x 16
C_0603_1608Metric x 6
R_0805_2012Metric
QFN-60_L7.0-W7.0-P0.40-TL-EP3.4
IND-SMD_L3.0-W3.0-H1.5
R_0603_1608Metric x 11
SOD-123F_L2.7-W1.6-LS3.8-RD
R_0402_1005Metric x 7
SOT-23-3
SOT-23-5
PCB x 2
POXY x 2
UNMASKED PCB x 2
PADS x 2
DIE PADS x 2
DIE PADS2 x 2
DIE RIM x 2
DIE x 2
DIODES x 2
BOND WIRES x 2
Crystal_SMD_3225-4Pin_3.2x2.5mm
Crystal_SMD_3215-2Pin_3.2x1.5mm
CONN-SMD_BC-25-3P
C_0805_2012Metric x 3
USB_C_Receptacle_16P_TopMnt_Horizontal_GCT_USB4105-xx-A
MSOP-8_3x3mm_P0.65mm
BUZ-SMD_3P-L5.0-W5.0-H3.0-BL
QFN-16_L3.0-W3.0-P0.50-TL-EP1.7-2
Click4_PCB

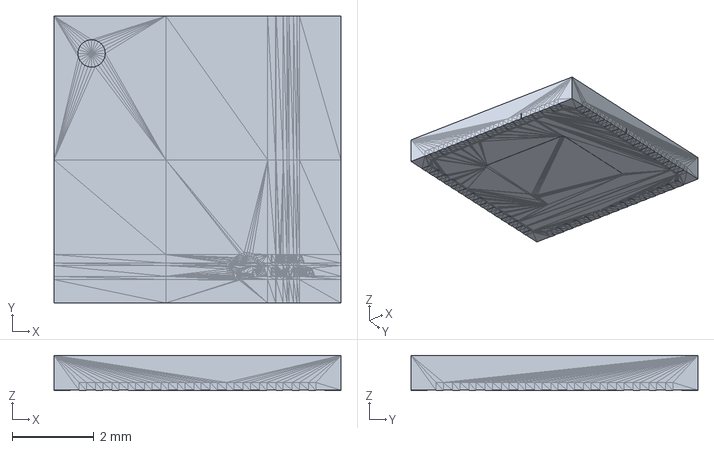
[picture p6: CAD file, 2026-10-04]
hardware/PCB/Click4/kiforge/3dmodels/QFN-60_L7.0-W7.0-P0.40-TL-EP3.4.step
7.00 x 7.00 x 0.861 mm

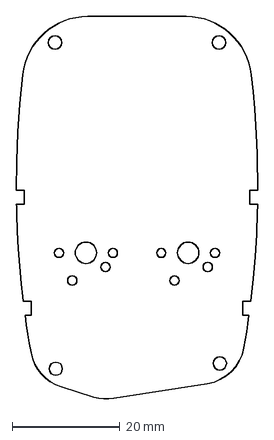
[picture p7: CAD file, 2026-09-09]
hardware/PCB/Resources/Click4Edgecut.DXF
44.9 x 71.2 mm

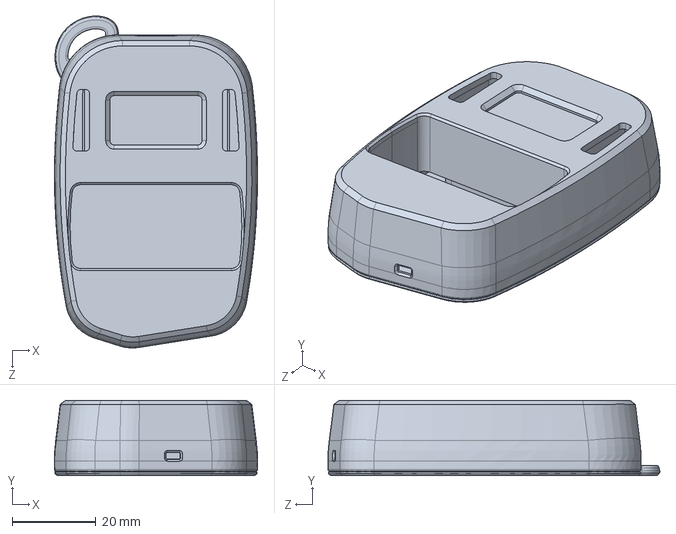
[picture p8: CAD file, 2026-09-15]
hardware/Enclosure/Click 4.SLDPRT
48.5 x 18.0 x 79.3 mm

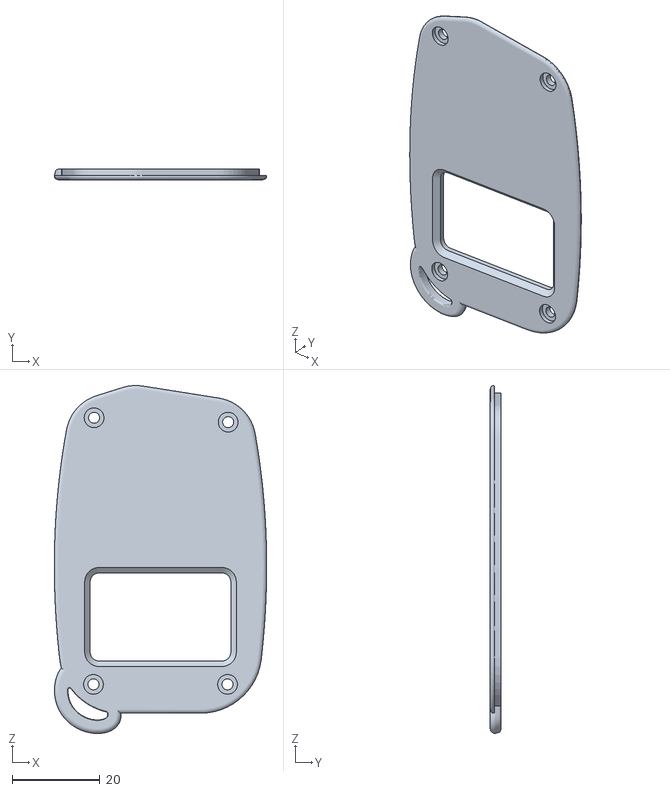
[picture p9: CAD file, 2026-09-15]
hardware/Enclosure/STLs/Back Plate w Hook.STL
48.3 x 2.40 x 79.2

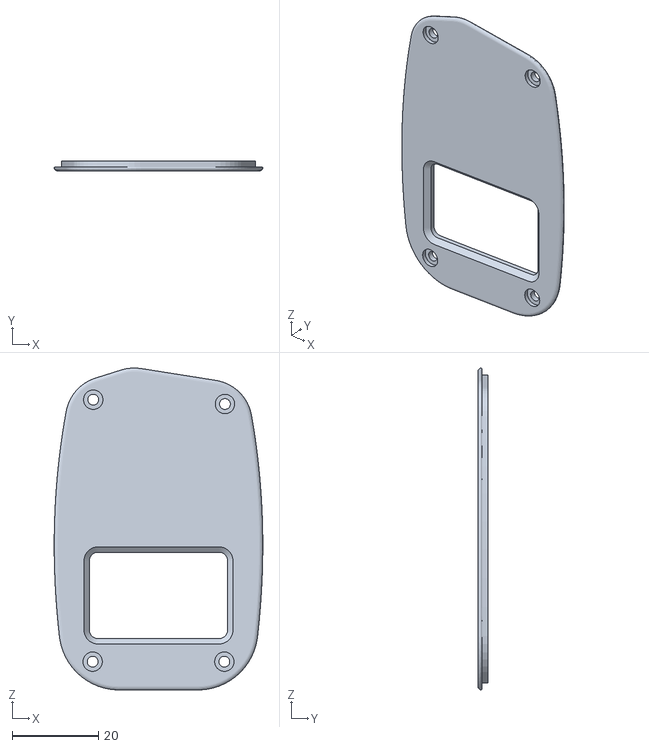
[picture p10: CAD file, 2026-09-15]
hardware/Enclosure/STLs/Back Plate w window.STL
48.3 x 2.40 x 74.6

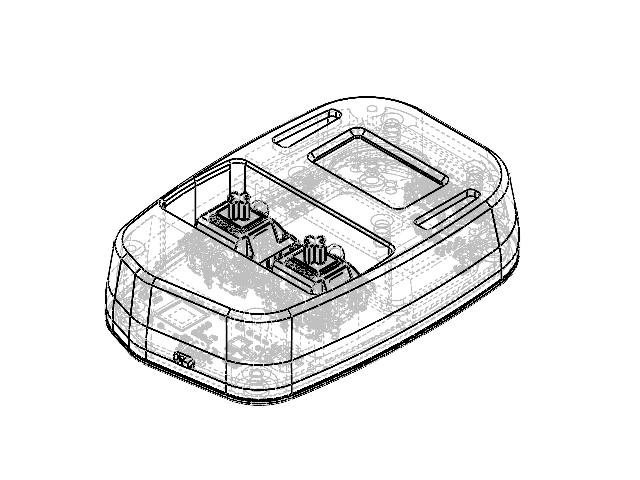
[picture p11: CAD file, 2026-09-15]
hardware/Enclosure/Assem4.SLDASM
Click 4
MX Series-Cherry Key x 2
Click4_PCB

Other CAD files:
hardware/Enclosure/Click4_PCB.SLDPRT
hardware/Enclosure/STLs/Case for Hook.STL

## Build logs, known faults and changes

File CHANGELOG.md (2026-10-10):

# Clicker Project Changelog & Architecture Master Log

> [!NOTE]
> **Living Document & AI Agent Instruction**: This document serves as the master record of all major architectural, memory storage, web updater, hardware revision, and firmware release decisions. AI agents and developers must append new entries to this changelog whenever significant system, storage, hardware, or release infrastructure changes occur.

---

## Core Architectural Decisions

### 1. NVS Partition Storage & Data Preservation Strategy
- **Partition Location**: `0x9000` (length `0x5000` / 20 KB).
- **Application Binary (`app0`)**: `0x10000` (65536 decimal, length `0x140000` / 1.25 MB).
- **Retention Guarantee**: Standard firmware updates strictly write to offset `0x10000` (`app0`). The `0x9000` NVS partition is preserved across updates, retaining all user lifetime clicks, completed cycles, unlocked milestones, and settings via `Preferences.h`.
- **Dual-Key Backup & Wear-Leveling**: Click stats and high scores are preserved using alternating NVS keys (`nvs_a` / `nvs_b`) with CRC checksum verification to safeguard against interrupted writes or power drops.
- **Power Efficiency**: Zero idle network activity (no background Wi-Fi/Bluetooth threads in core firmware) to preserve battery life.

### 2. Dual-Binary Distribution System
- **`firmware.bin` (Offset `0x10000`)**: Application-only binary used by WebSerial manifests and the `flash_device` CLI for data-preserving updates.
- **`factory_firmware.bin` (Offset `0x0`)**: All-in-one merged image combining bootloader (`0x1000`), partition table (`0x8000`), boot selector (`0xE000`), and application code (`0x10000`). Used for third-party tools ([web.esphome.io](https://web.esphome.io), raw `esptool.py` at `0x0`, and blank board recovery).

### 3. Supported Flashing Channels vs Third-Party Tools
- **Supported Data-Preserving Channels**:
  * **Official Web Flasher** (`web_flasher/index.html` or custom domain `flashclick.uprajjwal.com.np`): Safe browser-based updating with optional erase prompt.
  * **Desktop CLI Flasher** (`flash_device.bat` / `firmware/scripts/flash.sh`): Interactive terminal tool with safe offset `0x10000` preservation.
- **Third-Party Tool Caveat (`web.esphome.io`)**: Inherently destructive because it forces a full chip erase, wiping the `0x9000` NVS storage. Documented as a full factory reset / blank board recovery method only.

### 4. Release & Automation Architecture
- **Interactive Release Manager (`build_release.bat`)**: Automated compilation, 3-part binary packaging, semantic version bumping (`Major`, `Minor`, `Patch`), and 5-version retention in `releases/`.
- **Merged Binary Builder**: Automated creation of `factory_firmware.bin` (offset `0x0`) via `esptool merge_bin` to prevent unbootable devices on third-party flashers.
- **Automated Pre-Build Assets**: SCons pre-build hook (`firmware/scripts/pre_build_assets.py`) automatically compiles raw PNGs from `firmware/assets/screens/` into C PROGMEM headers prior to PlatformIO compilation.

---

## Release History & Changes

### [v0.1.1] - 2026-10-10

- **Persistent Custom Device Name Preservation Across Reflashes**:
  - **NVS-First Precedence & Auto-Persistence**: Updated `DeviceInfo::getCustomName()` so that whenever a custom name is flashed or set, it is immediately written to non-volatile storage (`clicker_cfg` -> `custom_name`). Subsequent reflashes with standard/unpatched binaries (where `g_device_name_signature` contains default `"CLICKER"`) no longer overwrite or mask the user's custom name.
  - **Serial Command Name Management**: Added `SET_NAME=<name>` and `RENAME <name>` serial command support in `firmware/src/main.cpp`, plus support for `NAME=` in `RESTORE` and `SET_STATS`. Preserves original casing.
  - **Web Flasher Cache & Memory**: Updated `web_flasher/app.js`, `flasher.html`, and `rp2350-flash.js` to cache device custom names in `localStorage` keyed by hardware unique ID (`click_name_<chip_id>`). When connecting or flashing, the modal input is automatically pre-filled with the device's existing name rather than resetting to blank or `"CLICKER"`.
  - **Cloudflare Worker D1 Leaderboard Protection**: Updated `/api/sync` in `server/worker.js` so that if an incoming sync request reports default `"CLICKER"`, any existing established custom name in the D1 database is preserved and returned, preventing leaderboard name wipes.
- **Dual-Target Release Automation (RP2354A + ESP32)**:
  - Enhanced `tools/release/release_manager.py` to compile both `rp2354` and `esp32doit-devkit-v1` targets, package `firmware.uf2` into `web_flasher/releases/v0.1.1/` alongside `firmware.bin` and `factory_firmware.bin`, and synchronize `versions.json`.

### [v1.0.4] - 2026-10-05

- **Same-Button Double-Click Wake Protection**:
  - Implemented accidental mistake click filter requiring two clicks on the **SAME key** (MODE-MODE or ACTION-ACTION within 500ms) to wake.
  - The first click wakes the MCU core internally, keeping the SSD1306 OLED, WS2812 RGB LEDs, and buzzer completely OFF.
  - Clicking one key and then pressing another key is rejected as accidental pocket contact, keeping the device asleep.
  - If no second click occurs on the same key within 500ms, the MCU remains asleep and returns to `__wfi()`. Continuous holds (> 3s) are safely rejected.
- **Fast 3-Stage Power Profile & Deep Sleep (< 1mA Standby)**:
  - Preserved the full 3-stage battery lifecycle optimized for fast wake: 8s idle contrast dimming (0x05), 15s display off (`lightSleepTimeout`), and 30s true deep sleep (`deepSleepTimeout`).
  - In deep sleep, MCU down-clocks to 12MHz direct crystal clock via `set_sys_clock_khz(12000, false)`, ADC is shut down, floating CMOS GPIO buffers disabled, and LEDs/buzzer clamped to 0V ground.
- **I2C Bus Preservation Across Sleep & Wake**:
  - Eliminated I2C peripheral teardown glitches that previously hung the SSD1306 controller and required physical ON/OFF switch (`SW1`) toggling.
  - `Wire1` remains intact during sleep with lines pulled HIGH (0µA idle), allowing instant, rock-solid wake in $< 1\text{ ms}$.
- **Raspberry Pi RP2354A Production Support (`env:rp2354`)**:
  - Full hardware and firmware integration for the Click 4 PCBA running dual Cortex-M33 at 48MHz with 4MB embedded QSPI Flash.
  - Native USB 2.0 Full Speed support for WebSerial communications and `picotool` flashing.
- **Micro-Power Sleep Mode (< 0.8mA Standby)**:
  - Implemented low-power ARM Cortex-M33 `__wfi()` sleep loop in `PowerManager.h`.
  - **Universal Button Wakeup**: Either button (`MODE` on GP0 or `ACTION` on `BOOTSEL`/`QSPI_SS`) participates in the double-click wake sequence.
  - Returns directly to Sisyphus on wake.
- **Hardware Charging Sense Fix (`STAT` on GP1)**:
  - Replaced faulty `usb_hw->sie_status` software detection (which is overridden to 1 permanently by the TinyUSB driver in silicon) with true hardware ETA6003 `STAT` pin sensing on GP1 with 10kΩ pullup `R9`. Unplugging USB cable is detected instantly.
- **Calibrated Non-Linear Li-Ion / LiPo SoC Curve**:
  - Replaced naive linear voltage mapping with an authentic piecewise Lithium-Polymer plateau curve in `battery.hpp`.
  - Added full-charge 100% cushion down to 4.08V to eliminate rapid post-unplug voltage drops.
  - Added 2-minute post-unplug surface charge relaxation freeze and 35-second-per-1% slew rate limiter to prevent sudden optical drops.
- **Reliable Battery Voltage Formatting (`x.xxV`)**:
  - Implemented integer decomposition in `SettingsApplet.h` to bypass `newlib-nano`'s default exclusion of `%f` floating-point formatters.
  - Added `-Wl,-u,_printf_float` linker flag in `platformio.ini`.
- **Intelligent Charging LED State Machine**:
  - Continuous, smooth multicolor breathing pattern while plugged into USB.
  - Applet switches via MODE button do not interrupt or flicker the breathing LED.
  - In-game transient event cues (Just 10 yellow stop flash, Flappy Bird red game-over flash, Sisyphus milestone celebration) temporarily display over the breathing pattern and automatically return to charging breathe when complete.
- **Ghost LED & Quiescent Leakage Elimination**:
  - Added `WS2812Driver::clearAndHaltForSleep()` which double-latches zeros, switches pin multiplexer from PIO to SIO, drives GP11 LOW (0V), and enables internal pull-down.
  - Disabled PCF8563 RTC CLKOUT continuous 32.768kHz oscillation.
  - Disabled digital input buffers on all unused Bank 0 GPIOs.
- **Documentation Master Release**:
  - Created [`docs/power_management_and_battery_architecture.md`](docs/power_management_and_battery_architecture.md): Exhaustive engineering deep-dive on micro-power optimization, battery fuel gauging, and silicon-level gotchas.
  - Updated [`docs/hardware_and_pinouts.md`](docs/hardware_and_pinouts.md) with authoritative RP2354A pin mapping and power architecture.

#### Added
- **Edge Serverless Leaderboard Backend (`server/`)**:
  - Zero-cost ($0/month), zero-maintenance edge backend powered by Cloudflare Workers and Cloudflare D1 (Serverless SQLite).
  - Schema defined in `server/schema.sql` (`global_stats`, `devices`, `sync_log`) with fast B-Tree indexing.
  - Endpoints:
    - `GET /api/leaderboard`: Returns real-time community boulder statistics and top 10 rankings for Sisyphus, Flappy Bird, and Just Ten.
    - `POST /api/sync`: Atomic score submission with rate limiting and delta crediting.
    - `GET /api/user`: Queries registered handle and stats by 12-character eFuse MAC.
- **The "Community Boulder" Shared Mechanic**:
  - Transforms solitary clicking into a global cooperative experience: all player clicks are aggregated into a single massive global boulder counter (`global_stats.total_boulder_clicks`).
  - Web interface visualizes the worldwide community progress as a shared ascent up Mount Olympus.
- **Server-Side Anti-Cheat & Human-Speed Rate Limiting**:
  - Algorithms enforce physical human limitations (~15–20 clicks/second maximum sustained rate).
  - Validates delta clicks against time elapsed since the device's previous sync.
  - Blocks impossible score injections and logs all delta claims into `sync_log`.
- **Custom Bootscreen Name & Device Personalization (`device_info.hpp` / `device_info.cpp`)**:
  - Persistent custom device name storage in NVS (`device` namespace).
  - Dynamically renders the owner's custom name (e.g. `"Prajjwal's Click"`) directly on the SSD1306 OLED boot screen.
- **WebSerial Bi-Directional Command Protocol (`main.cpp`)**:
  - Integrated ASCII serial interface over UART0 (115200 baud):
    - `GET_ID`: Returns unique 12-char factory eFuse MAC (`ID:<chip_id>`).
    - `GET_NAME`: Returns saved owner name (`NAME:<name>`).
    - `SET_NAME:<name>`: Writes new owner handle to NVS without reflashing firmware.
    - `GET_STATS`: Extracts live metrics from active applets (`CLICKS:<n>,FLAPPY:<n>,JUST_TEN:<n>`).
    - `RESET_STATS`: Allows zeroing active applet metrics.
- **Unified Web Flasher & Live Leaderboard Hub (`web_flasher/`)**:
  - Re-architected `flasher.html`, `index.html`, and `app.js` with responsive dark cyberpunk aesthetic.
  - Embedded live leaderboard tab with real-time podium cards for all three mini-games.
  - Two-way WebSerial connection tool to personalize device names and sync scores in one click.
  - Automatic fallback to bundled `leaderboard.json` if edge API is unreachable.

---

### [v0.1.0] - 2026-09-12

#### Added
- **Modular Firmware Architecture (`firmware/src/system/` & `firmware/src/applets/`)**:
  - Isolated core system firmware from game and applet logic to make adding new applets trivial without touching core OS/hardware code.
  - Core system layer (`Display.h`, `OSManager`, `PowerManager`, `InputManager`, `battery.hpp`, `device_info.hpp`, `Applet.h`) centralized into `firmware/src/system/`.
  - Applets organized into self-contained directories (`applets/clicker/`, `applets/timing_game/`, `applets/flappy_bird/`, `applets/settings/`, `applets/screensaver/`).
  - Removed obsolete legacy `input.hpp`.
  - Updated `platformio.ini` include flags so system and applet headers are resolved cleanly.
- **Sisyphus Clicker Game Engine (`CounterApplet`, `CounterRenderer`, `SisyphusSprites`)**:
  - Complete thematic overhaul: Sisyphus rolling a boulder up a mountain slope.
  - Multi-frame sprite animations: 25 FPS pushing cycle, 8 FPS walking cycle, and 10 FPS ambient cloud drift.
  - Physics-based boulder rotation and progress tracking.
  - Dynamic stamina and fatigue gauge: Sustained rapid clicking induces physical fatigue; Sisyphus rests and recovers stamina when clicking pauses.
  - Full integer display formatting: Fixed issues where counts over 10,000 were truncated or suffixed with abbreviations; numbers now render with full comma separators (e.g. `10,000+`, `25,480`).
  - Milestone celebration overlays: Graphic banners trigger upon crossing milestones (1, 5, 10, 50, 100, 500, 1000, 5000, 10000+).
- **Flappy Bird Minigame (`FlappyBirdApplet`)**:
  - Full arcade obstacle game featuring real-time collision detection, flapping velocity mechanics, score rendering, and persistent high score tracking.
- **Advanced Power Management Architecture (`PowerManager.h`)**:
  - **Light Sleep (20s Idle)**: Shuts down SSD1306 OLED, releases RF/ADC, and arms RTC GPIO wakeups.
  - **Deep Sleep (45s Idle)**: Complete power domain shutdown with instantaneous button wake.
  - **UART Pad Isolation**: Enforces `gpio_hold_en` on `UART_TX0` (GPIO 1) and `UART_RX0` (GPIO 3) during sleep to eliminate phantom current leakage back-feeding into the CH340 USB-UART converter.
  - **Display Bus Lockup Prevention**: Keeps I2C SDA and SCL pulled HIGH during sleep rather than driven to 0V.
  - **9-Cycle SCL Bus Recovery**: Sends 9 clock pulses on SCL upon wake to unstick any hung I2C slave devices before calling `Wire.begin()`.
- **Hardware Documentation & PCB Archival**:
  - **Active Prototype Board (Click 1)**: Added KiCad schematic and PCB layout files to `hardware/PCB/Click1/`. Documents the manually assembled ESP32-WROOM-32E prototype that actively executes all current embedded firmware in `firmware/`.
  - **Production Board (Click 4 - JLCPCB PCBA)**: Added complete turnkey PCBA design files to `hardware/PCB/Click4/` (schematic, PCB layout, and 3D STEP models).
  - Microcontroller: RP2354A (QFN-56 package, 30 GPIOs: GP0-GP29, 512KB SRAM, 4MB Flash)
  - *Finalized Production Routing (Implemented in v1.0.4 & `PinConfig.h`)*:
    - Display & RTC I2C: SDA = GP2, SCL = GP3 (`Wire1` at 400kHz)
    - User Inputs: MODE = GP0, ACTION = BOOTSEL / QSPI_SS
    - Power & Battery: STAT = GP1 (Active LOW, ETA6003), BAT_ADC = GP29 (ADC3)
    - Audio & LEDs: Buzzer = GP27 (NPN BJT), 2× WS2812/SK6812 DIN = GP11
    - Voltage Regulator: AP2112K-3.3 with EN tied to physical slide switch SW1

#### Fixed & Optimized
- **Display Stabilization**: Added 500ms delay in `setup()` to allow SSD1306 power-on reset (POR) capacitors to stabilize before issuing initialization commands.
- **FreeRTOS Watchdog Panic**: Inserted `delay(2)` yield in `main.cpp` `loop()` to feed the Core 1 Task Watchdog Timer (`IDLE1` task).
- **Memory Leaks**: Eliminated heap fragmentation and unreleased display buffers in `CounterRenderer` and `PersistenceManager`.
- **Battery Curve Precision**: Calibrated 32-sample oversampled EMA filter with piece-wise LiPo discharge table and 5% hysteresis lock in `battery.hpp`.

---

### [v1.0.2] - 2026-08-26

#### Added
- Pre-build automated asset conversion pipeline integrated into PlatformIO (`pre_build_assets.py`).
- Pin assignment swaps and power optimization for battery voltage monitoring on GPIO 35 and charger status on GPIO 33.
- Web flasher binary and manifest synchronization.

---

### [v1.0.1] - 2026-08-23

#### Added
- Multi-applet architecture managed by `OSManager`.
- Timing game applet ("Just 10 Seconds") with millisecond accuracy evaluation.
- Snowfall screensaver (`HomeApplet`) activating on system idle.
- Battery percentage and hardware identification display in `SettingsApplet`.

---

### [v1.0.0] - 2026-08-20

#### Added
- Interactive Desktop CLI Flasher (`flash_device.bat` / `tools/flasher/flash_device.py`).
- All-in-One Factory Binary Merger (`factory_firmware.bin` at `0x0`).
- Interactive Release Manager (`build_release.bat` / `tools/release/release_manager.py`).
- Web Flasher Interface (`web_flasher/index.html` & `web_flasher/flasher.html`).
- Code freeze rules and project guidelines (`PROJECT_RULES.md`).

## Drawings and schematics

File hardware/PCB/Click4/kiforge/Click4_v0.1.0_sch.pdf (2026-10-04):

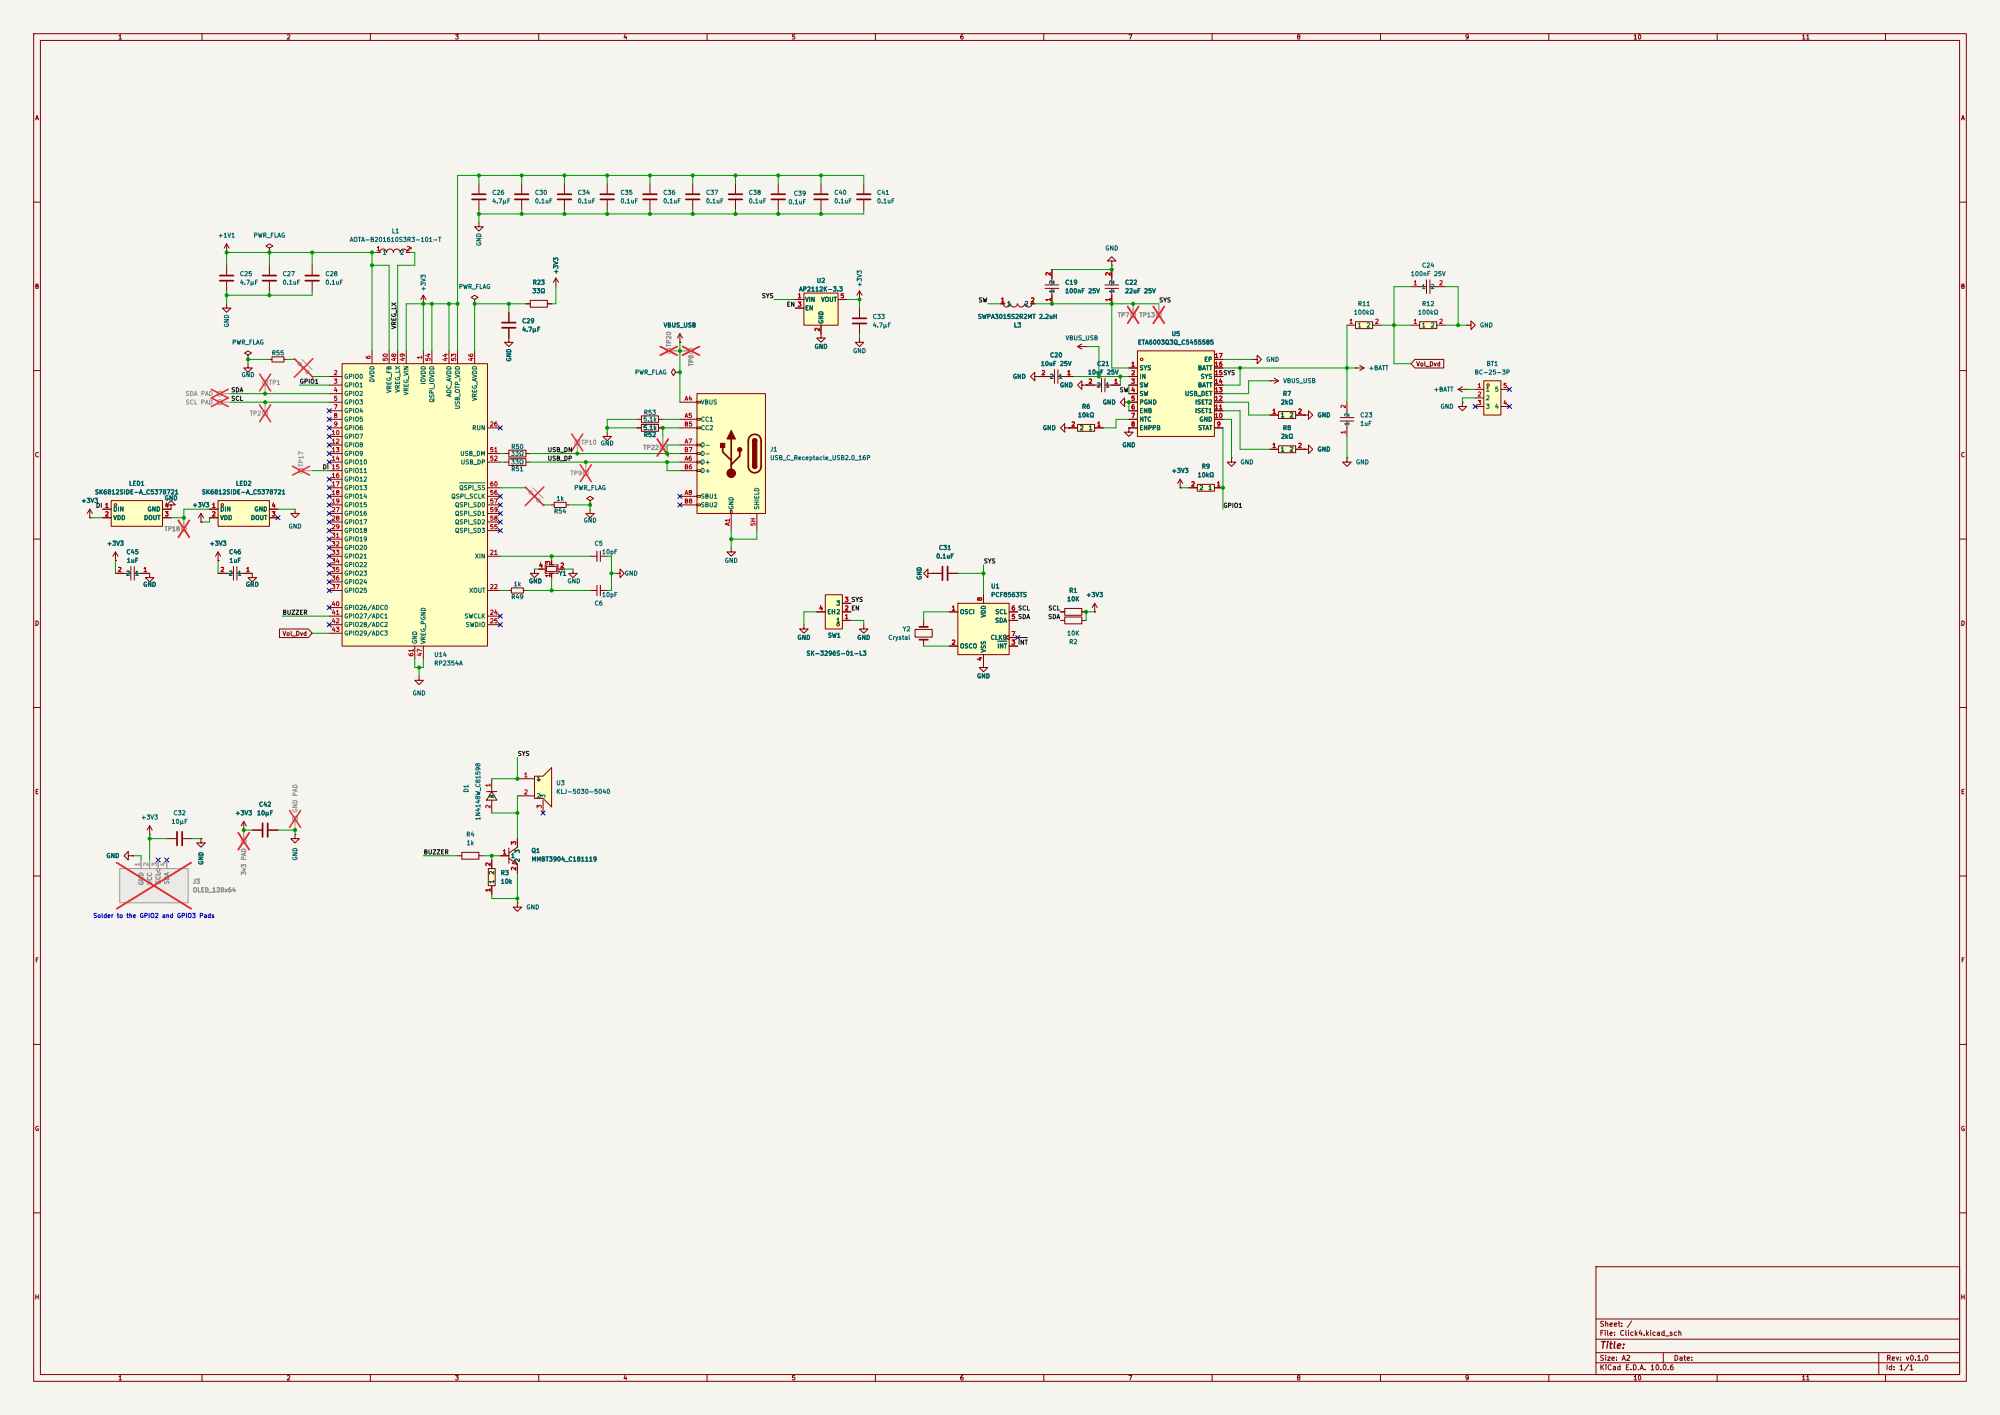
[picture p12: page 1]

2 SCL 3 SDA 4 GND 3v3 PAD +3V3 GND

Solder to the GPIO2 and GPIO3 Pads

Size: A2 | Rev: v0.1.0
KiCad E.D.A. 10.0.6 | Id: 1/1

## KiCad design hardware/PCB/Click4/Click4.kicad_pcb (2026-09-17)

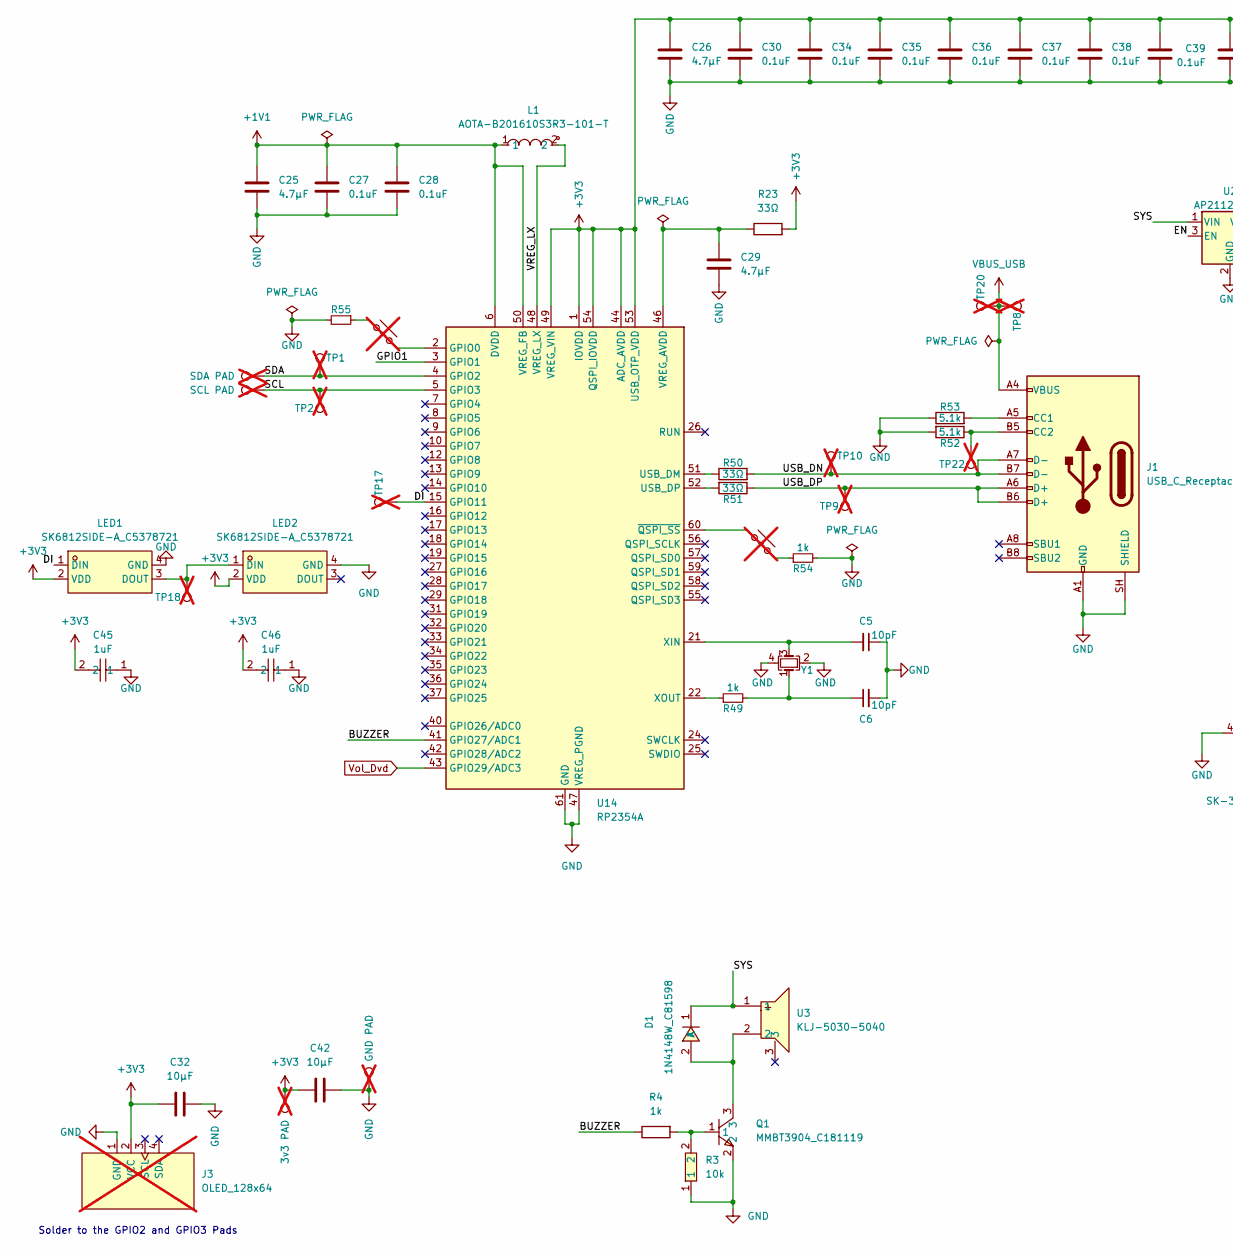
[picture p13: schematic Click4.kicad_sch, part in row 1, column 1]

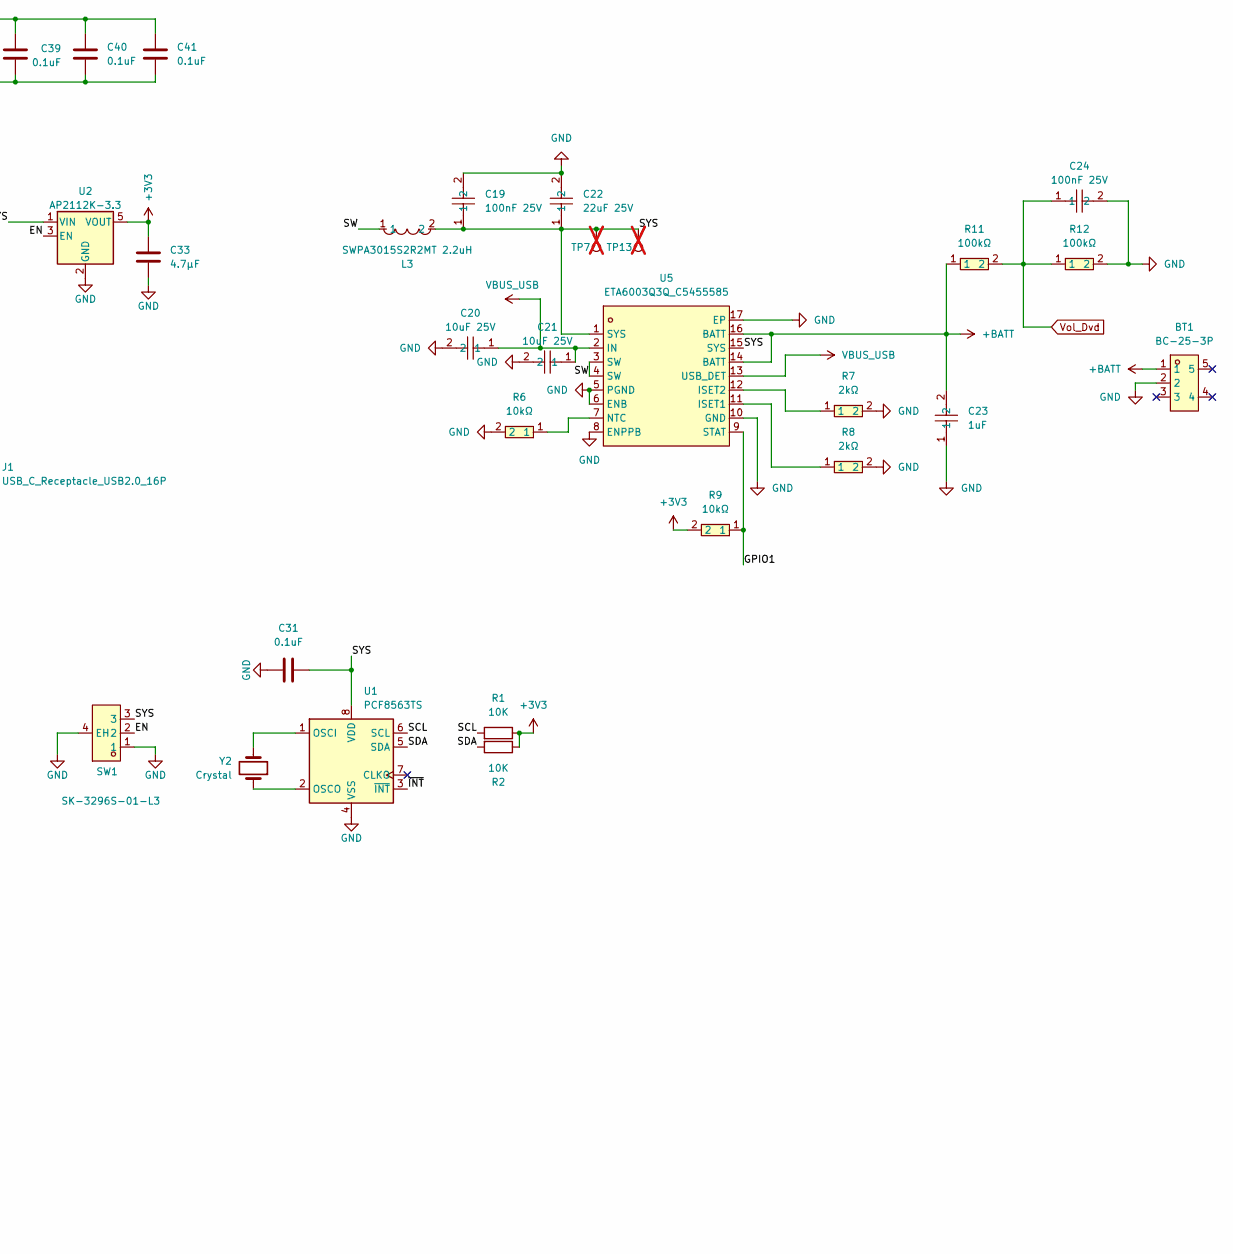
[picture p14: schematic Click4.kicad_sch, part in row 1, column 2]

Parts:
BT1: BC-25-3P; CONN-SMD_BC-25-3P; MPN BC-25-3P; LCSC Part C707322
C5, C6: 10pF; C_0603_1608Metric; MPN CL10C100JB8NFNC
C19, C24: 100nF 25V; C_0603_1608Metric; MPN 0603B104K250NT; LCSC Part C694249
C20, C21: 10uF 25V; C_0805_2012Metric; MPN TCC0805X7R106K250FT; LCSC Part C48543594
C22: 22uF 25V; C_0805_2012Metric; MPN CGA0805X5R226M250MT; LCSC Part C6119899
C23, C45, C46: 1uF; C_0603_1608Metric; MPN TCC0603X7R105K250CT; LCSC Part C380328
C25, C26, C29: 4.7μF; C_0402_1005Metric; MPN GRM155D80E475ME47J; LCSC Part C23733
C27, C28, C30, C31, C34, C35, C36, C37, C38, C39, C40, C41: 0.1uF; C_0402_1005Metric; MPN CL05B104KA5NNNC; LCSC Part C1525
C32: 10μF; C_0402_1005Metric; MPN GRM155D80E475ME47J
C33: 4.7μF; C_0603_1608Metric; MPN CL10A475KO8NNNC; LCSC Part C19666
C42: 10μF; C_0402_1005Metric; MPN GRM155D80E475ME47J; LCSC Part C15525
D1: 1N4148W_C81598; SOD-123F_L2.7-W1.6-LS3.8-RD; MPN 1N4148W; LCSC Part C81598
J1: USB_C_Receptacle_USB2.0_16P; USB_C_Receptacle_G-Switch_GT-USB-7010ASV; LCSC Part C2765186
J3: OLED_128x64; not fitted
L1: AOTA-B201610S3R3-101-T; IND-SMD_L2.0-W1.6_AOTA-B201610S3R3-101-T; MPN AOTA-B201610S3R3-101-T; LCSC Part C42411119
L3: SWPA3015S2R2MT 2.2uH; IND-SMD_L3.0-W3.0; MPN SWPA3015S2R2MT; LCSC Part C43389
LED1, LED2: SK6812SIDE-A_C5378721; LED-SMD_4P-L4.0-W1.6-L; MPN SK6812SIDE-A; LCSC Part C5378721
Q1: MMBT3904_C181119; SOT-23-3; MPN MMBT3904; LCSC Part C181119
R1, R2: 10K; R_0402_1005Metric; LCSC Part C25744
R3: 10k; R_0603_1608Metric; MPN 0603WAF1002T5E; LCSC Part C25804
R4, R49, R54, R55: 1k; R_0603_1608Metric; MPN RT0603FRE101KL; LCSC Part C21190
R6, R9: 10kΩ; R_0603_1608Metric; MPN 0603WAF1002T5E; LCSC Part C25804
R7, R8: 2kΩ; R_0603_1608Metric; MPN RC0603FR-072KL; LCSC Part C105576
R11, R12: 100kΩ; R_0603_1608Metric; MPN 0603WAF1003T5E; LCSC Part C25803
R23, R50, R51: 33Ω; R_0402_1005Metric; MPN RC0402FR-0733RL; LCSC Part C138002
R52, R53: 5.1k; R_0402_1005Metric; MPN RC0402FR-075K1L; LCSC Part C25905
S1, S2: MX_PCB_1.00u; not fitted
SW1: SK-3296S-01-L3; SW-SMD_SK-3296S-01-L3; MPN SK-3296S-01-L3; LCSC Part C319019
TP1, TP2, TP7, TP8, TP9, TP10, TP13, TP17, TP18, TP20, TP22: TestPoint; TestPoint_Pad_D1.0mm; not fitted
TP3: SDA PAD; TestPoint_Pad_D2.0mm; not fitted
TP4: SCL PAD; TestPoint_Pad_D2.0mm; not fitted
TP5: 3v3 PAD; TestPoint_Pad_D2.0mm; not fitted
TP6: GND PAD; TestPoint_Pad_D2.0mm; not fitted
U1: PCF8563TS; MSOP-8_3x3mm_P0.65mm; LCSC Part C27397
U2: AP2112K-3.3; SOT-23-5; MPN AP2112K-3.3TRG1
U3: KLJ-5030-5040; BUZ-SMD_3P-L5.0-W5.0-BL; MPN KLJ-5030-5040; LCSC Part C18186311
U5: ETA6003Q3Q_C5455585; QFN-16_L3.0-W3.0-P0.50-TL-EP1.7-2; MPN ETA6003Q3Q; LCSC Part C5455585
U14: RP2354A; QFN-60-1EP_7x7mm_P0.4mm_EP3.4x3.4mm; MPN SC1511(13)-A4
Y1: Crystal; Crystal_SMD_3225-4Pin_3.2x2.5mm; MPN ABM8-272-T3; LCSC Part C20625731
Y2: Crystal; Crystal_SMD_3215-2Pin_3.2x1.5mm; LCSC Part C97604

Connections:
+1V1: C25.1, C27.2, C28.2, L1.1, U14.6 (DVDD), U14.23 (DVDD), U14.39 (DVDD), U14.50 (VREG_FB)
+3V3: C26.1, C30.2, C32.1, C33.1, C34.2, C35.2, C36.2, C37.2, C38.2, C39.2, C40.2, C41.2, C42.1, C45.2, C46.2, J3.2 (VCC), LED1.2 (VDD), LED2.2 (VDD), R1.1, R2.1, R9.2, R23.2, TP5.1 (1_1), U2.5 (VOUT), U14.1 (IOVDD), U14.11 (IOVDD), U14.20 (IOVDD), U14.30 (IOVDD), U14.38 (IOVDD), U14.44 (ADC_AVDD), U14.45 (IOVDD), U14.49 (VREG_VIN), U14.53 (USB_OTP_VDD), U14.54 (QSPI_IOVDD)
+BATT: BT1.1, C23.2, R11.1, U5.14 (BATT), U5.16 (BATT)
/BUZZER: R4.1, U14.41 (GPIO27/ADC1)
/DI: LED1.1 (DIN), TP17.1 (1_1), U14.15 (GPIO11)
/EN: SW1.2, U2.3 (EN)
/GPIO1: R9.1, U5.9 (STAT), U14.3 (GPIO1)
/SCL: R1.2, TP2.1 (1_1), TP4.1 (1_1), U1.6 (SCL), U14.5 (GPIO3)
/SDA: R2.2, TP1.1 (1_1), TP3.1 (1_1), U1.5 (SDA), U14.4 (GPIO2)
/SW: L3.1, U5.3 (SW), U5.4 (SW)
/SYS: C19.1, C22.1, C31.1, D1.1 (K), L3.2, SW1.3, TP7.1 (1_1), TP13.1 (1_1), U1.8 (VDD), U2.1 (VIN), U3.1, U5.1 (SYS), U5.15 (SYS)
/USB_DN: J1.A7 (D-), J1.B7 (D-), R50.2, TP10.1 (1_1)
/USB_DP: J1.A6 (D+), J1.B6 (D+), R51.1, TP9.1 (1_1)
/VREG_LX: L1.2, U14.48 (VREG_LX)
/~INT: U1.3 (~INT)
GND: BT1.2, C5.1, C6.2, C19.2, C20.2, C21.2, C22.2, C23.1, C24.2, C25.2, C26.2, C27.1, C28.1, C29.2, C30.1, C31.2, C32.2, C33.2, C34.1, C35.1, C36.1, C37.1, C38.1, C39.1, C40.1, C41.1, C42.2, C45.1, C46.1, J1.A1 (GND), J1.A12 (GND), J1.B1 (GND), J1.B12 (GND), J1.SH (SHIELD), J3.1 (GND), LED1.4 (GND), LED2.4 (GND), Q1.2, R3.1, R6.2, R7.2, R8.2, R12.2, R52.2, R53.1, R54.2, R55.2, SW1.1, SW1.4 (EH), TP6.1 (1_1), U1.4 (VSS), U2.2 (GND), U5.5 (PGND), U5.6 (ENB), U5.8 (ENPPB), U5.10 (GND), U5.17 (EP), U14.47 (VREG_PGND), U14.61 (GND), Y1.2, Y1.4
unnamed: C6.1, R49.2, Y1.1
unnamed: D1.2 (A), Q1.3, U3.2
unnamed: J1.A5 (CC1), R53.2
unnamed: J1.B5 (CC2), R52.1, TP22.1 (1_1)
unnamed: LED1.3 (DOUT), LED2.1 (DIN), TP18.1 (1_1)
unnamed: Q1.1, R3.2, R4.2
unnamed: R54.1, S2.2
unnamed: R55.1, S1.1
unnamed: U1.1 (OSCI), Y2.2
unnamed: U1.2 (OSCO), Y2.1
unnamed: R8.1, U5.11 (ISET1)
unnamed: R7.1, U5.12 (ISET2)
unnamed: R6.1, U5.7 (NTC)
unnamed: S1.2, U14.2 (GPIO0)
unnamed: R50.1, U14.51 (USB_DM)
unnamed: R51.2, U14.52 (USB_DP)
unnamed: C29.1, R23.1, U14.46 (VREG_AVDD)
unnamed: C5.2, U14.21 (XIN), Y1.3
unnamed: R49.1, U14.22 (XOUT)
unnamed: S2.1, U14.60 (~QSPI_SS)
VBUS_USB: C20.1, C21.1, J1.A4 (VBUS), J1.A9 (VBUS), J1.B4 (VBUS), J1.B9 (VBUS), TP8.1 (1_1), TP20.1 (1_1), U5.2 (IN), U5.13 (USB_DET)
Vol_Dvd: C24.1, R11.2, R12.1, U14.43 (GPIO29/ADC3)

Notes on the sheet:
Solder to the GPIO2 and GPIO3 Pads

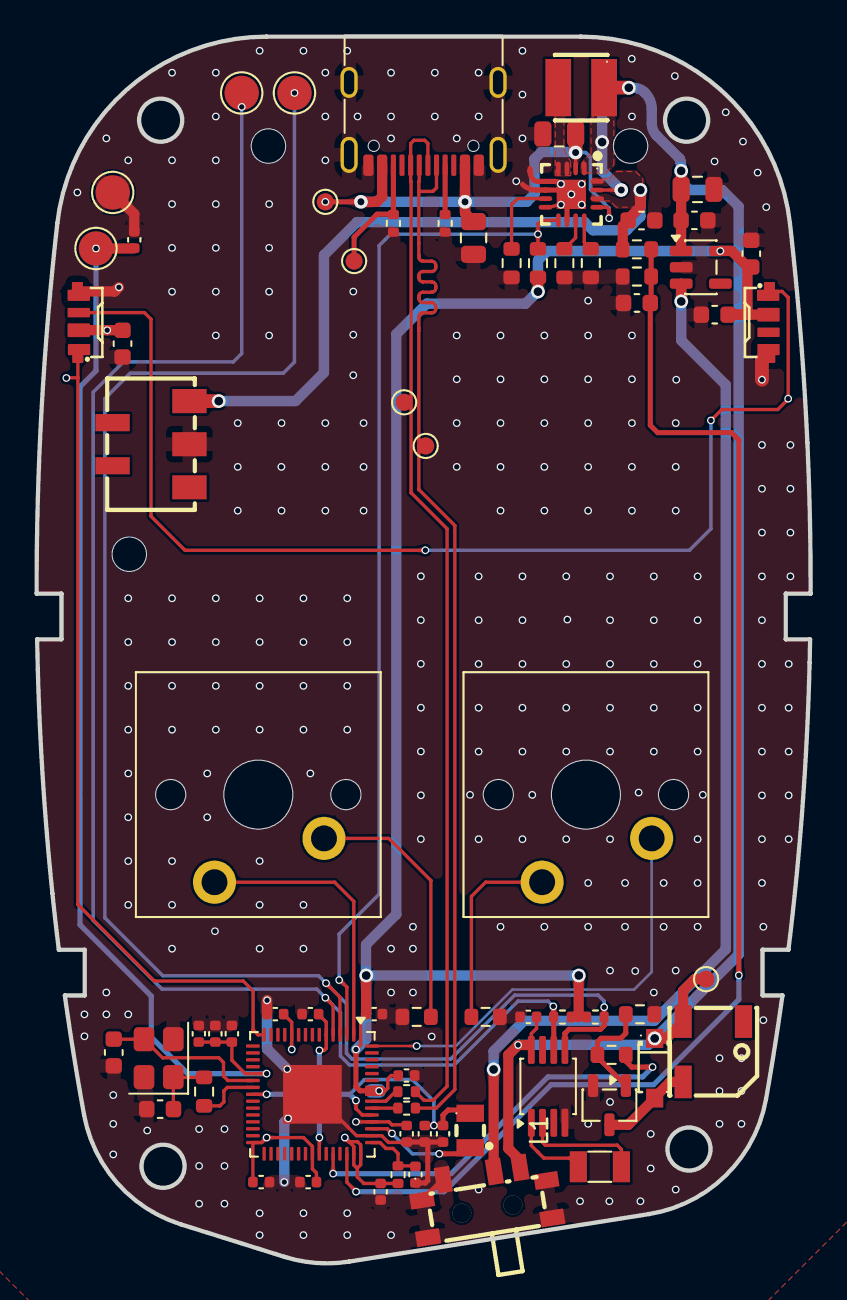
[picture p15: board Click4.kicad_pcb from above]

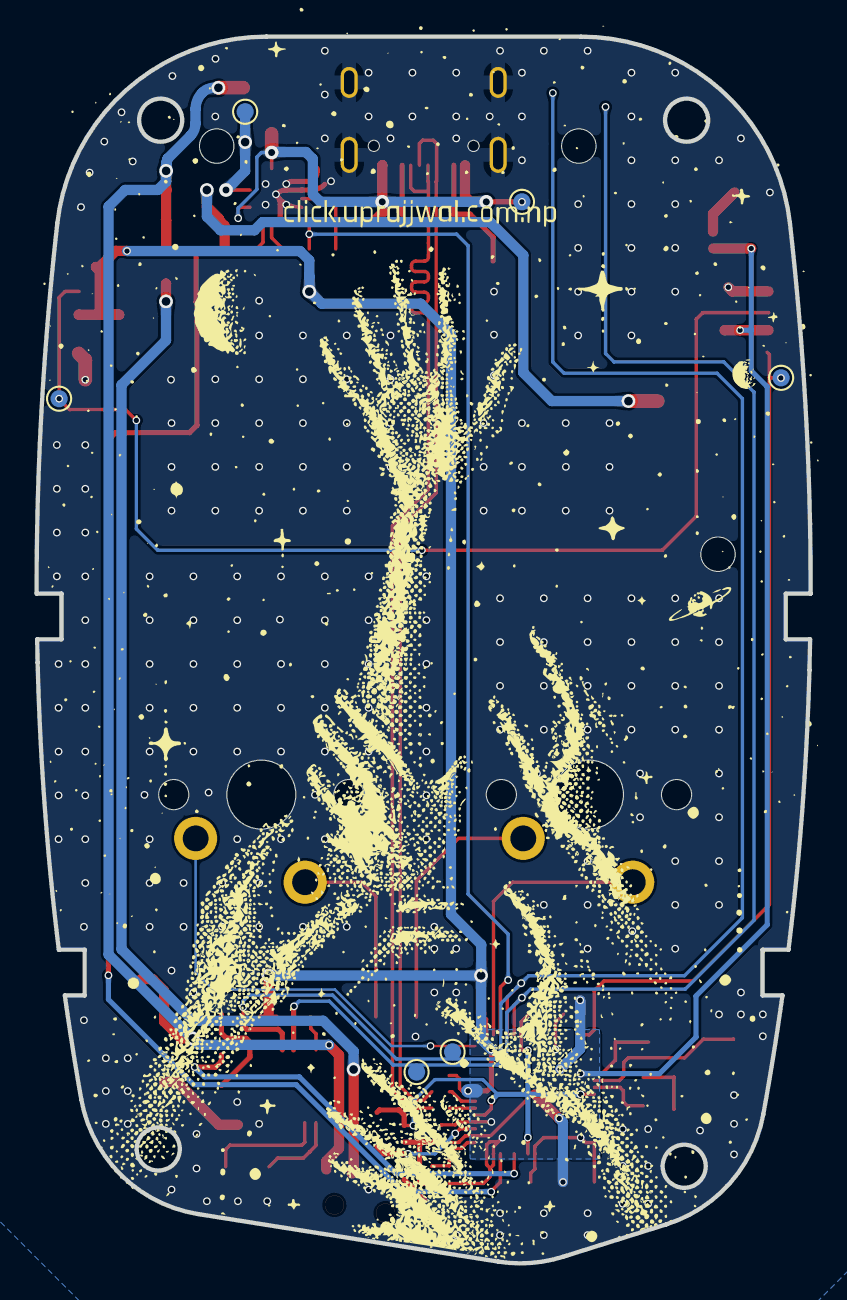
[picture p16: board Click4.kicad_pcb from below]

Board: 2 copper layers, 44.9 x 71.1 mm, 78 parts (6 on the bottom side), 37 nets.

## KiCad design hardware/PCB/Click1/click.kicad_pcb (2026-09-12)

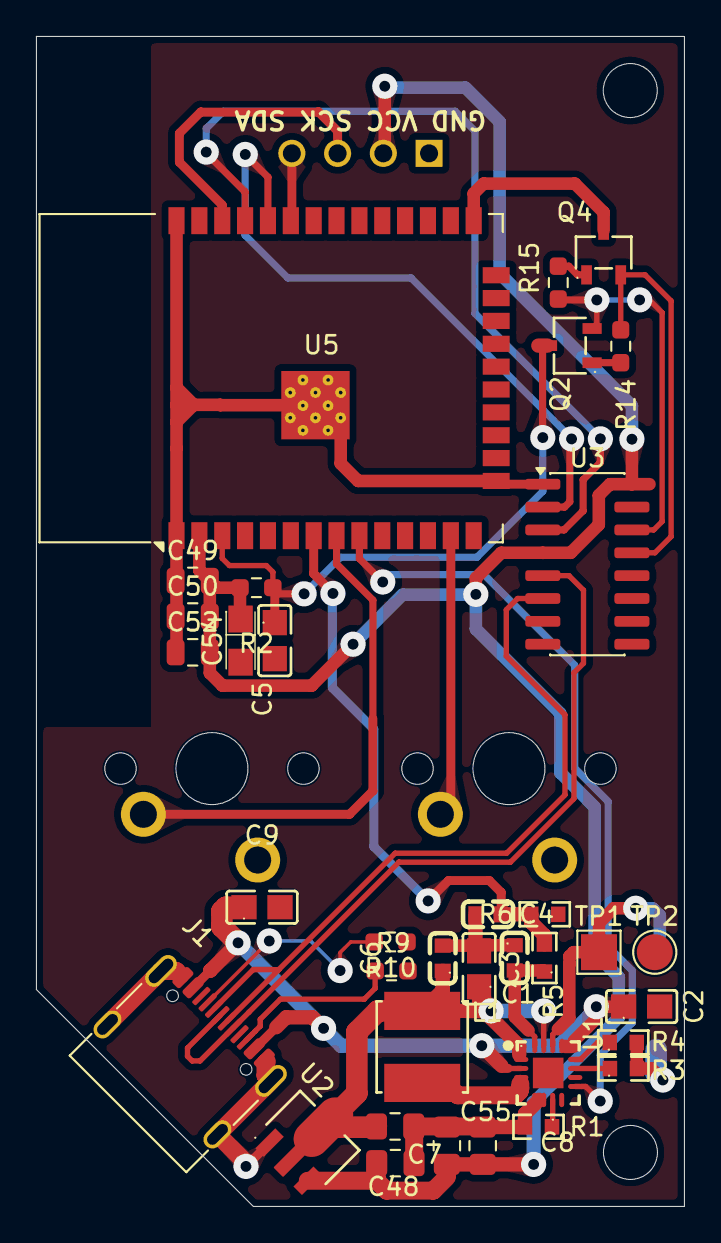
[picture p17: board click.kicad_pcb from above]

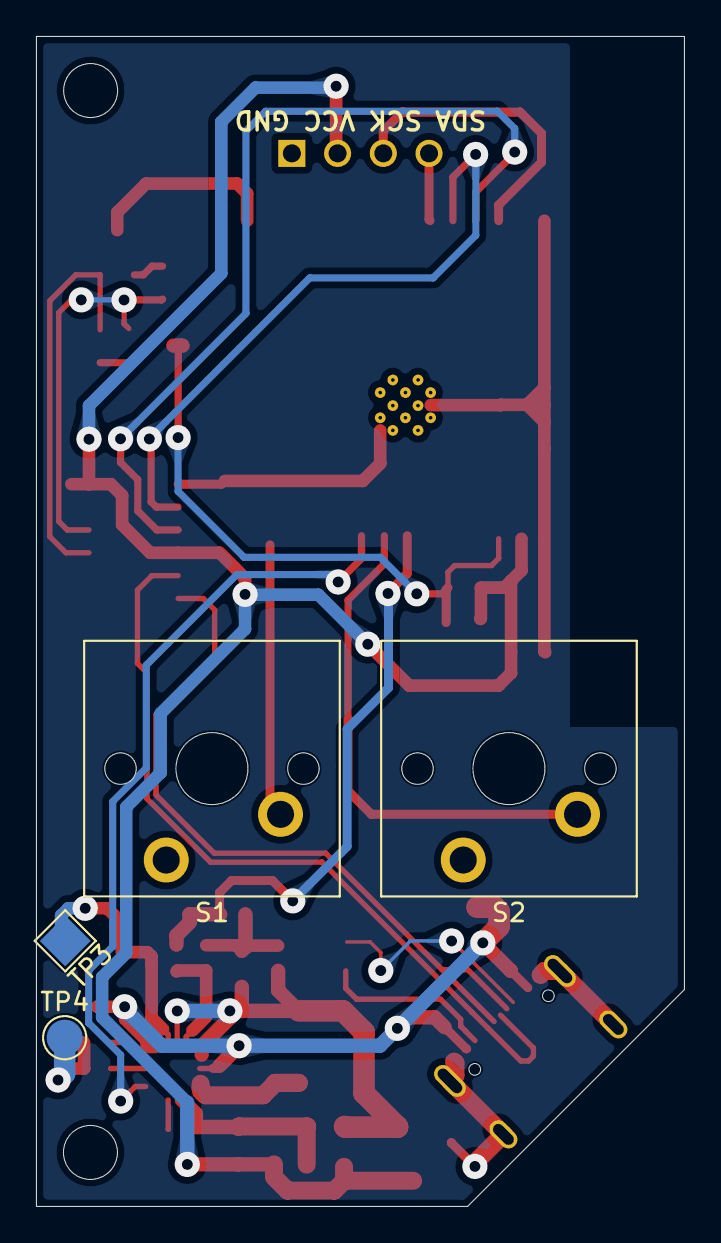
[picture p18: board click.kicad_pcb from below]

Board: 2 copper layers, 36.0 x 65.0 mm, 40 parts (5 on the bottom side), 27 nets.

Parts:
C1: 1uF; C0603
C2, C9: 10uF 25V; C0805
C3: 22uF 25V; C0805
C4, C6: 100nF 25V; C0603
C5: CL21B105KBFNNNE; C0805
C7, C8: 22uF X5R 25V; C_0805_2012Metric_Pad1.18x1.45mm_HandSolder
C48, C55: 100n; C_0805_2012Metric_Pad1.18x1.45mm_HandSolder
C49: 33pF C0G 50V; C_0805_2012Metric
C50: 100nF X7R 50V; C_0805_2012Metric
C52: 22uF X5R 25V; C_0805_2012Metric
C54: TAN 100uF 6.3V; CASE-A_3216
J1: USB_C_Receptacle_USB2.0_16P; USB_C_Receptacle_G-Switch_GT-USB-7010ASV
J2: OLED_128x64
L1: 2.2uH 3.2A; IND-SMD_L5.0-W5.0
Q2, Q4: MMBT3904_C181119; SOT-23-3_L2.9-W1.6-P1.90-LS2.8-BR
R1: 10kΩ; R0603
R2: 10K 1%; R_0603_1608Metric_Pad0.98x0.95mm_HandSolder
R3, R4: 2kΩ; R0603
R5, R6: 100kΩ; R0603
R9, R10: 5k1; R_0603_1608Metric_Pad0.98x0.95mm_HandSolder
R14, R15: 10k; R_0603_1608Metric_Pad0.98x0.95mm_HandSolder
S1, S2: MX_PCB_1.00u
TP1, TP3: TestPoint; TestPoint_Pad_2.0x2.0mm
TP2, TP4: TestPoint; TestPoint_Pad_D2.0mm
U1: ETA6003Q3Q_C5455585; QFN-16_L3.0-W3.0-P0.50-TL-EP1.7-2
U2: HT7833; SOT-89_L4.5-W2.5-P1.50-LS4.2-BR
U3: CH340C; SOIC-16_3.9x9.9mm_P1.27mm
U5: ESP32-WROOM-32E; ESP32-WROOM-32D

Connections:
+3V3: C8.2, C48.1, C49.2, C50.2, C52.2, C54.1, C55.1, J2.2 (VCC), R2.2, U2.3 (OUT), U3.4 (V3), U3.16 (VCC), U5.2 (VDD)
+BATT: C1.2, R5.1, TP1.1 (1_1), TP3.1 (1_1), U1.14 (BATT), U1.16 (BATT)
/D+: J1.A6 (D+), J1.B6 (D+), U3.5 (UD+)
/D-: J1.A7 (D-), J1.B7 (D-), U3.6 (UD-)
/DTR: Q4.2, R14.1, U3.13 (~DTR)
/EN: C5.1, Q2.3, R2.1, U5.3 (EN)
/IO0: Q4.3, U5.25 (IO0)
/RTS: Q2.2, R15.1, U3.14 (~RTS)
/RXD: U3.3 (RXD), U5.35 (TXD0/IO1)
/STAT: U1.9 (STAT), U5.9 (IO33)
/TXD: U3.2 (TXD), U5.34 (RXD0/IO3)
ETA_VOUT_PWR: C3.1, C6.1, C7.2, L1.2, U1.1 (SYS), U1.15 (SYS), U2.2 (IN)
GND: C1.1, C2.2, C3.2, C4.2, C5.2, C6.2, C7.1, C8.1, C9.2, C48.2, C49.1, C50.1, C52.1, C54.2, C55.2, J1.A1 (GND), J1.A12 (GND), J1.B1 (GND), J1.B12 (GND), J1.SH (SHIELD), J2.1 (GND), R1.2, R3.2, R4.2, R6.2, R9.1, R10.1, S1.2, S2.2, TP2.1 (1_1), TP4.1 (1_1), U1.5 (PGND), U1.6 (ENB), U1.8 (ENPPB), U1.10 (GND), U1.17 (EP), U2.1 (GND), U3.1 (GND), U5.1 (GND), U5.15 (GND), U5.38 (GND), U5.39 (GND)
unnamed: J1.A5 (CC1), R10.2
unnamed: J1.B5 (CC2), R9.2
unnamed: J2.3 (SCL), U5.36 (IO22)
unnamed: J2.4 (SDA), U5.33 (IO21)
unnamed: L1.1, U1.3 (SW), U1.4 (SW)
unnamed: Q2.1, R14.2
unnamed: Q4.1, R15.2
unnamed: R3.1, U1.11 (ISET1)
unnamed: R4.1, U1.12 (ISET2)
unnamed: R1.1, U1.7 (NTC)
unnamed: S1.1, U5.13 (IO14)
unnamed: S2.1, U5.8 (IO32)
VBUS_USB: C2.1, C9.1, J1.A4 (VBUS), J1.A9 (VBUS), J1.B4 (VBUS), J1.B9 (VBUS), U1.2 (IN), U1.13 (USB_DET)
Vol_Dvd: C4.1, R5.2, R6.1, U5.7 (IO35)

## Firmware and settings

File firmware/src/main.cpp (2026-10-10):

#include <Arduino.h>
#include <Wire.h>

// Core System
#include "system/Display.h"
#include "system/OSManager.h"
#include "system/device_info.hpp"
#include "system/WS2812.h"
#include "system/SoundFX.h"

// Modular Applets
#include "applets/clicker/CounterApplet.h"
#include "applets/timing_game/TimingGameApplet.h"
#include "applets/flappy_bird/FlappyBirdApplet.h"
#include "applets/settings/SettingsApplet.h"
#include "applets/screensaver/HomeApplet.h"

// Typography
#include "fonts/ThemeFonts.h"

#if __has_include("generated_assets/bootscreen.h")
  #include "generated_assets/bootscreen.h"
#endif

Adafruit_SSD1306 display(128, 64, &CLICK_I2C, OLED_RST_PIN);

OSManager osManager;
HomeApplet homeApplet;
CounterApplet counterApplet;
TimingGameApplet timingGameApplet;
SettingsApplet settingsApplet;
FlappyBirdApplet flappyBirdApplet;

void onModeButtonClick() {
    if (osManager.recordActivity(1)) {
        return; // Screen was asleep/off; first click wakes the screen silently
    }
    // Requirement 2: Do NOT beep just before Sisyphus game!
    uint8_t curIdx = osManager.getCurrentAppletIndex();
    uint8_t nextIdx = (curIdx + 1) % 4; // 0 is Sisyphus
    if (nextIdx != 0) {
        SoundFX::playClick(); // Only click when switching into other applets!
    }
    Applet* applet = osManager.getCurrentApplet();
    if (applet == &homeApplet) {
        osManager.switchToApplet(0); // Exit screensaver back to Clicker
        return;
    }
    if (applet) {
        applet->onModeClick();
    }
    osManager.switchToNextApplet();
}

void onModeButtonHold() {
    if (osManager.recordActivity(1)) {
        return;
    }
    Applet* applet = osManager.getCurrentApplet();
    if (applet) {
        applet->onModeHold();
    }
    // Hold MODE button toggles Settings page
    if (applet == &settingsApplet) {
        osManager.switchToApplet(0); // Return to Clicker
    } else {
        osManager.switchToApplet(3); // Jump to Settings
    }
}

void onActionButtonClick() {
    if (osManager.recordActivity(2)) {
        return; // Screen was off; wake display
    }
    Applet* applet = osManager.getCurrentApplet();
    if (applet == &homeApplet) {
        osManager.switchToApplet(0); // Wake from screensaver to Clicker
        return;
    }
    if (applet) {
        applet->onActionClick();
    }
}

void onActionButtonHold() {
    if (osManager.recordActivity(2)) {
        return;
    }
    Applet* applet = osManager.getCurrentApplet();
    if (applet == &homeApplet) {
        osManager.switchToApplet(0); // Wake from screensaver to Clicker
        return;
    }
    if (applet) {
        applet->onActionHold();
    }
}

void onBothButtonsHeld() {
    if (osManager.recordActivity(0)) {
        return;
    }
    Applet* applet = osManager.getCurrentApplet();
    if (applet) {
        applet->onBothHeld();
    }
}

static Preferences sysPrefs;
static uint32_t totalUptimeMinutes = 0;
static uint32_t lastUptimeCheckMs = 0;
static void handleSerialTelemetry();

#if defined(CLICK_HW_TEST_MENU)
#include "system/HardwareDiagnostics.h"
#endif

void setup() {
#if defined(CLICK_HW_TEST_MENU)
    HardwareDiagnostics::run();
#endif

    Serial.begin(115200);

    // Early preload of state so telemetry can answer immediately even during boot
    counterApplet.preloadState();
    flappyBirdApplet.preloadState();
    timingGameApplet.preloadState();
    sysPrefs.begin("sys_uptime", false);
    totalUptimeMinutes = sysPrefs.getUInt("minutes", 0);
    lastUptimeCheckMs = millis();

    // Responsive early delay loop checking for incoming telemetry
    for (int i = 0; i < 50; i++) {
        handleSerialTelemetry();
        delay(10);
    }

#if defined(ARDUINO_ARCH_RP2040)
    CLICK_I2C.setSDA(OLED_SDA_PIN);
    CLICK_I2C.setSCL(OLED_SCL_PIN);
    CLICK_I2C.begin();
#else
    CLICK_I2C.begin(OLED_SDA_PIN, OLED_SCL_PIN);
#endif

    if (!display.begin(SSD1306_SWITCHCAPVCC, 0x3C)) {
        while (1) {
            handleSerialTelemetry();
            delay(100);
        }
    }

    display.setRotation(2); // Rotate display 180 degrees
    display.ssd1306_command(SSD1306_SETCONTRAST);
    display.ssd1306_command(0x3F); // High-contrast crisp white without burning 20mA

    // Solutions 43, 44, 45: SSD1306 Low-Power Controller Configuration
    display.ssd1306_command(0xD5); // Set Display Clock Divide Ratio / Oscillator Frequency
    display.ssd1306_command(0x80); // Optimal lower-power oscillator frequency
    display.ssd1306_command(0xD9); // Set Pre-charge Period
    display.ssd1306_command(0x22); // Phase 1: 2 DCLKs, Phase 2: 2 DCLKs (drops charge pump load)
    display.ssd1306_command(0xDB); // Set VCOMH Deselect Level
    display.ssd1306_command(0x20); // 0.77 x Vcc (reduces drive current)

    // Solution 73: Disable PCF8563 RTC CLKOUT pin to eliminate continuous 32.768kHz high-frequency switching
    CLICK_I2C.beginTransmission(0x51);
    CLICK_I2C.write(0x0D); // CLKOUT_control register
    CLICK_I2C.write(0x00); // 0 = Disable CLKOUT (tri-state pin, 0µA current)
    CLICK_I2C.endTransmission();

    // Initialize RGB LEDs, Sound Buzzer, and Battery Monitoring
    WS2812Driver::init();
    SoundFX::init();
    BatteryManager::init();
    SoundFX::playStartup(); // Requirement 2: Startup chime on boot
    WS2812Driver::flash(0, 180, 255, 500);

    // Set 400kHz Fast I2C mode for smooth SSD1306 refresh
    CLICK_I2C.setClock(400000);

    // Boot screen: display custom device name (default: CLICKER) and "Starting up..."
    display.clearDisplay();

    const char* bootName = DeviceInfo::getCustomName();
    if (!bootName || bootName[0] == '\0') {
        bootName = "Click";
    }

    const GFXfont* nameFont = &Rajdhani24pt7b;
    int16_t xA = 0, yA = 0, xB = 0, yB = 0;
    uint16_t wA = 0, hA = 0, wB = 0, hB = 0;
    ThemeFonts::measure(nameFont, bootName, xA, yA, wA, hA);
    if (wA + 1 > 120) {
        nameFont = &Rajdhani18pt7b;
        ThemeFonts::measure(nameFont, bootName, xA, yA, wA, hA);
    }
    if (wA + 1 > 120) {
        nameFont = &Rajdhani12pt7b;
        ThemeFonts::measure(nameFont, bootName, xA, yA, wA, hA);
    }

    const GFXfont* subFont = &Rajdhani12pt7b;
    ThemeFonts::measure(subFont, "Starting up...", xB, yB, wB, hB);

    // Treat name and "Starting up..." as a single unified visual group
    const int16_t gap = 4;
    const int16_t effectiveWA = static_cast<int16_t>(wA + 1);
    const int16_t totalH = static_cast<int16_t>(hA + gap + hB);
    const int16_t topY = static_cast<int16_t>((64 - totalH) / 2);

    // Pixel-perfect baseline cursor calculation for both texts
    const int16_t cursorYA = static_cast<int16_t>(topY - yA);
    const int16_t cursorYB = static_cast<int16_t>(topY + hA + gap - yB);

    const int16_t cursorXA = static_cast<int16_t>((128 - effectiveWA) / 2 - xA);
    const int16_t cursorXB = static_cast<int16_t>((128 - static_cast<int16_t>(wB)) / 2 - xB);

    // Draw device name with thicker / bold weight (1px horizontal overstrike)
    display.setFont(nameFont);
    display.setTextSize(1);
    display.setTextColor(SSD1306_WHITE);
    display.setCursor(cursorXA, cursorYA);
    display.print(bootName);
    display.setCursor(cursorXA + 1, cursorYA);
    display.print(bootName);

    // Draw subtitle
    display.setFont(subFont);
    display.setTextSize(1);
    display.setTextColor(SSD1306_WHITE);
    display.setCursor(cursorXB, cursorYB);
    display.print("Starting up...");

    display.display();

    // Bootscreen delay (500ms): service serial telemetry & LED timing, then shut LED off cleanly
    for (int i = 0; i < 50; i++) {
        handleSerialTelemetry();
        WS2812Driver::update();
        delay(10);
    }
    WS2812Driver::clear();

    // Register playable main applets (index 0 is active on boot)
    osManager.registerApplet(&counterApplet);     // index 0: Clicker (Default on boot)
    osManager.registerApplet(&timingGameApplet);  // index 1: Just Ten
    osManager.registerApplet(&flappyBirdApplet);  // index 2: Flappy Bird
    osManager.registerApplet(&settingsApplet);    // index 3: Settings (Hold MODE)
    
    // Set snowfall applet as screensaver on inactivity
    osManager.setScreensaverApplet(&homeApplet);

    osManager.init();
    counterApplet.preloadState();

    InputManager* inputMgr = osManager.getInputManager();
    inputMgr->onModeClick    = onModeButtonClick;
    inputMgr->onModeHold     = onModeButtonHold;
    inputMgr->onActionClick  = onActionButtonClick;
    inputMgr->onActionHold   = onActionButtonHold;
}

static void handleSerialTelemetry() {
    if (!Serial.available()) return;
    static char cmdBuf[64];
    static char rawCmdBuf[64];
    static uint8_t cmdIdx = 0;
    while (Serial.available()) {
        char c = static_cast<char>(Serial.read());
        if (c == '\n' || c == '\r') {
            if (cmdIdx > 0) {
                cmdBuf[cmdIdx] = '\0';
                memcpy(rawCmdBuf, cmdBuf, cmdIdx + 1);
                // Case-insensitive uppercase conversion for cmdBuf commands
                for (uint8_t i = 0; i < cmdIdx; i++) {
                    if (cmdBuf[i] >= 'a' && cmdBuf[i] <= 'z') {
                        cmdBuf[i] -= 32;
                    }
                }
                if (strstr(cmdBuf, "GET_STATS") != nullptr || strstr(cmdBuf, "STATS") != nullptr) {
                    // Flush any active session clicks immediately to NVS before reading
                    counterApplet.persistNow();

                    String idStr = DeviceInfo::getID();
                    const char* chipId = idStr.c_str();
                    const char* dName = DeviceInfo::getCustomName();
                    if (!dName || dName[0] == '\0') {
                        dName = "Click";
                    }

                    uint64_t clicks = counterApplet.getLifetimeClicks();
                    uint16_t flappy = flappyBirdApplet.getHighScore();
                    double justTen = timingGameApplet.getBestTimeSec();
                    uint32_t uptimeHrs = totalUptimeMinutes / 60;

                    Serial.printf("{\"event\":\"stats\",\"name\":\"%s\",\"chip_id\":\"%s\",\"clicks\":%llu,\"flappy\":%u,\"just_ten\":%.4f,\"uptime_hrs\":%u}\n",
                                  dName, chipId, clicks, flappy, justTen, uptimeHrs);
                } else if (strstr(cmdBuf, "SET_NAME") != nullptr || strstr(cmdBuf, "RENAME") != nullptr) {
                    char* p = strstr(cmdBuf, "SET_NAME");
                    uint8_t kwLen = p ? 8 : 6;
                    if (!p) p = strstr(cmdBuf, "RENAME");
                    int offset = (p - cmdBuf) + kwLen;
                    char* rawP = rawCmdBuf + offset;
                    while (*rawP == ' ' || *rawP == '=') rawP++;
                    char* end = rawP;
                    while (*end && *end != '\r' && *end != '\n') end++;
                    *end = '\0';
                    if (strlen(rawP) > 0) {
                        DeviceInfo::setCustomName(rawP);
                        Serial.printf("{\"event\":\"name_updated\",\"name\":\"%s\"}\n", DeviceInfo::getCustomName());
                    }
                } else if (strstr(cmdBuf, "SET_CLICKS") != nullptr) {
                    char* p = strstr(cmdBuf, "SET_CLICKS") + 10;
                    while (*p == ' ' || *p == '=') p++;
                    uint64_t val = strtoull(p, nullptr, 10);
                    if (val > 0) {
                        counterApplet.setLifetimeClicks(val);
                        Serial.printf("{\"event\":\"clicks_updated\",\"clicks\":%llu}\n", val);
                    }
                } else if (strstr(cmdBuf, "SET_STATS") != nullptr || strstr(cmdBuf, "RESTORE") != nullptr) {
                    char* pName = strstr(cmdBuf, "NAME=");
                    if (pName) {
                        int nameOffset = (pName - cmdBuf) + 5;
                        char* rawName = rawCmdBuf + nameOffset;
                        char* end = rawName;
                        while (*end && *end != ' ' && *end != ',' && *end != '\r' && *end != '\n') end++;
                        char saved = *end;
                        *end = '\0';
                        if (strlen(rawName) > 0) {
                            DeviceInfo::setCustomName(rawName);
                        }
                        *end = saved;
                    }
                    char* pClicks = strstr(cmdBuf, "CLICKS=");
                    if (pClicks) {
                        uint64_t val = strtoull(pClicks + 7, nullptr, 10);
                        if (val > counterApplet.getLifetimeClicks()) {
                            counterApplet.setLifetimeClicks(val);
                        }
                    }
                    char* pFlappy = strstr(cmdBuf, "FLAPPY=");
                    if (pFlappy) {
                        uint16_t val = static_cast<uint16_t>(strtoul(pFlappy + 7, nullptr, 10));
                        flappyBirdApplet.setHighScore(val);
                    }
                    char* pJustTen = strstr(cmdBuf, "JUST_TEN=");
                    if (pJustTen) {
                        double sec = strtod(pJustTen + 9, nullptr);
                        if (sec > 0.0) {
                            timingGameApplet.setBestTimeUs(static_cast<uint32_t>(sec * 1000000.0));
                        }
                    }
                    Serial.printf("{\"event\":\"stats_restored\",\"name\":\"%s\",\"clicks\":%llu,\"flappy\":%u,\"just_ten\":%.4f}\n",
                                  DeviceInfo::getCustomName(),
                                  counterApplet.getLifetimeClicks(),
                                  flappyBirdApplet.getHighScore(),
                                  timingGameApplet.getBestTimeSec());
                } else if (strstr(cmdBuf, "PING") != nullptr) {
                    Serial.println("{\"event\":\"pong\"}");
                }
                cmdIdx = 0;
            }
        } else if (cmdIdx < sizeof(cmdBuf) - 1) {
            cmdBuf[cmdIdx++] = c;
        } else {
            // Buffer overflow recovery
            cmdIdx = 0;
        }
    }
}

void loop() {
    uint32_t frameStart = millis();

    // During charging, maintain an uninterrupted breathing LED of multi-colors,
    // but allow game effects (flashes, celebrations) to temporarily display
    static bool wasCharging = false;
    bool charging = BatteryManager::isCharging();
    if (charging) {
        if (!WS2812Driver::isChargingBreatheActive() && !WS2812Driver::isBusy()) {
            WS2812Driver::startChargingBreathe();
        }
    } else if (wasCharging) {
        WS2812Driver::stopChargingBreathe();
    }
    wasCharging = charging;

    SoundFX::update();
    WS2812Driver::update();

    osManager.update();
    osManager.draw();

    // Check serial telemetry requests (non-blocking)
    handleSerialTelemetry();

    // Track active runtime (persist once every hour to safeguard flash longevity)
    uint32_t now = millis();
    if (now - lastUptimeCheckMs >= 60000) {
        lastUptimeCheckMs = now;
        totalUptimeMinutes++;
        if (totalUptimeMinutes % 60 == 0) {
            sysPrefs.putUInt("minutes", totalUptimeMinutes);
        }
    }

    // Dynamic low-power frame pacing:
    // Cap rendering to ~30 FPS (33ms). Sleeping during idle frame time invokes
    // ARM __wfi() (Wait For Interrupt), dramatically cutting active MCU current!
    uint32_t elapsed = millis() - frameStart;
    if (elapsed < 33) {
        delay(33 - elapsed);
    } else {
        delay(2);
    }
}

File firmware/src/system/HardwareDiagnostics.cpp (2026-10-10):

#include "HardwareDiagnostics.h"
#include "Display.h"
#include "PinConfig.h"
#include "WS2812.h"
#include "battery.hpp"
#include "device_info.hpp"
#include <Wire.h>

static void drawOledHeader(const char* title) {
    display.clearDisplay();
    display.setTextSize(1);
    display.setTextColor(SSD1306_WHITE);
    display.setCursor(0, 0);
    display.print("== ");
    display.print(title);
    display.println(" ==");
    display.drawLine(0, 10, 127, 10, SSD1306_WHITE);
    display.setCursor(0, 14);
}

// BCD helper for PCF8563
static uint8_t bcdToDec(uint8_t val) {
    return ((val / 16 * 10) + (val % 16));
}

void HardwareDiagnostics::testBuzzer() {
    Serial.println("\n--- [1] Testing Buzzer on GP27 ---");
    drawOledHeader("BUZZER TEST");
    display.println("Pin: GP27 (NPN Driver)");
    display.println("1. Click Ticks");
    display.display();

    pinMode(BUZZER_PIN, OUTPUT);

    // 1. Click ticks
    Serial.println(" -> Playing click ticks (2400 Hz)...");
    for (int i = 0; i < 3; i++) {
        tone(BUZZER_PIN, 2400, 30);
        delay(120);
    }

    // 2. Chime (C5, E5, G5, C6)
    drawOledHeader("BUZZER TEST");
    display.println("Pin: GP27");
    display.println("2. Chime (C-E-G-C)");
    display.display();
    Serial.println(" -> Playing ascending chime...");
    const uint16_t notes[] = {523, 659, 784, 1046};
    for (uint16_t n : notes) {
        tone(BUZZER_PIN, n, 80);
        delay(100);
    }
    noTone(BUZZER_PIN);

    // 3. Frequency Sweep
    drawOledHeader("BUZZER TEST");
    display.println("Pin: GP27");
    display.println("3. Frequency Sweep");
    display.display();
    Serial.println(" -> Playing frequency sweep (600 Hz -> 2600 Hz)...");
    for (uint16_t f = 600; f <= 2600; f += 100) {
        tone(BUZZER_PIN, f, 15);
        delay(15);
    }
    noTone(BUZZER_PIN);

    drawOledHeader("BUZZER TEST");
    display.println("Buzzer test completed!");
    display.display();
    Serial.println(" [OK] Buzzer test completed.");
}

void HardwareDiagnostics::testRGBLEDs() {
    Serial.println("\n--- [2] Testing WS2812 / SK6812 RGB LEDs on GP11 (DIN) ---");
    WS2812Driver::init();

    struct ColorTest {
        const char* name;
        uint8_t r, g, b;
    } tests[] = {
        {"RED",     255,   0,   0},
        {"GREEN",     0, 255,   0},
        {"BLUE",      0,   0, 255},
        {"YELLOW",  255, 200,   0},
        {"CYAN",      0, 255, 255},
        {"MAGENTA", 255,   0, 255},
        {"WHITE",   255, 255, 255},
        {"OFF",       0,   0,   0}
    };

    for (const auto& c : tests) {
        Serial.printf(" -> LED Color: %s\n", c.name);
        drawOledHeader("RGB LED TEST");
        display.println("Type: WS2812 (GP11 DIN)");
        display.printf("Color: %s\n", c.name);
        display.display();

        WS2812Driver::setAll(c.r, c.g, c.b);
        delay(350);
    }

    // Rainbow cycle animation
    Serial.println(" -> Running smooth rainbow cycle...");
    drawOledHeader("RGB LED TEST");
    display.println("Rainbow Cycle...");
    display.display();

    for (int hue = 0; hue < 360; hue += 15) {
        float h = hue / 60.0f;
        int i = static_cast<int>(h);
        float f = h - i;
        uint8_t q = static_cast<uint8_t>(255 * (1.0f - f));
        uint8_t t = static_cast<uint8_t>(255 * f);

        uint8_t r = 0, g = 0, b = 0;
        switch (i) {
            case 0: r = 255; g = t;   b = 0;   break;
            case 1: r = q;   g = 255; b = 0;   break;
            case 2: r = 0;   g = 255; b = t;   break;
            case 3: r = 0;   g = q;   b = 255; break;
            case 4: r = t;   g = 0;   b = 255; break;
            default:r = 255; g = 0;   b = q;   break;
        }

        WS2812Driver::setPixel(0, r, g, b);
        WS2812Driver::setPixel(1, b, r, g);
        WS2812Driver::show();
        delay(30);
    }

    WS2812Driver::clear();
    Serial.println(" [OK] WS2812 RGB LEDs test completed.");
}
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

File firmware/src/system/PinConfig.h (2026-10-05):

#pragma once

#include <Arduino.h>

#if defined(TARGET_RP2354) || defined(ARDUINO_ARCH_RP2040)
#include <Wire.h>
// ==============================================================================
// Hardware Pinout: Click 4 PCBA (Raspberry Pi RP2354A)
// ==============================================================================
#ifndef I2C_SDA
#define I2C_SDA             2   // GP2: I2C1 SDA (SSD1306 OLED & PCF8563 RTC)
#endif

#ifndef I2C_SCL
#define I2C_SCL             3   // GP3: I2C1 SCL (SSD1306 OLED & PCF8563 RTC)
#endif

#ifndef OLED_SDA_PIN
#define OLED_SDA_PIN        I2C_SDA
#endif

#ifndef OLED_SCL_PIN
#define OLED_SCL_PIN        I2C_SCL
#endif

#ifndef OLED_RST_PIN
#define OLED_RST_PIN        -1
#endif

#ifndef OLED_EN_PIN
#define OLED_EN_PIN         -1
#endif

#ifndef MODE_BUTTON_PIN
#define MODE_BUTTON_PIN     0   // GP0: MODE Button (Active LOW)
#endif

#ifndef ACTION_BUTTON_PIN
#define ACTION_BUTTON_PIN   -1  // QSPI_SS / BOOTSEL (Active LOW)
#endif

#ifndef BATTERY_ADC_PIN
#define BATTERY_ADC_PIN     29  // GP29: Battery Voltage Sensor (ADC3)
#endif

#ifndef CHARGER_STAT_PIN
#define CHARGER_STAT_PIN    1   // GP1: ETA6003 STAT pin (Active LOW when charging, pulled up to 3.3V via R9)
#endif

#ifndef WS2812_PIN
#define WS2812_PIN          11  // GP11: WS2812 / SK6812 Addressable RGB LEDs (DIN)
#endif

#ifndef RGB_LED_PIN
#define RGB_LED_PIN         WS2812_PIN
#endif

#ifndef RGB_DATA_PIN
#define RGB_DATA_PIN        WS2812_PIN
#endif

#ifndef BUZZER_PIN
#define BUZZER_PIN          27  // GP27: Sound Buzzer (via NPN transistor)
#endif

#define CLICK_I2C           Wire1

#else
// ==============================================================================
// Hardware Pinout: Click 1 Prototype (ESP32-WROOM-32E)
// ==============================================================================
#ifndef I2C_SDA
#define I2C_SDA             21  // GPIO 21: I2C SDA
#endif

#ifndef I2C_SCL
#define I2C_SCL             22  // GPIO 22: I2C SCL
#endif

#ifndef OLED_SDA_PIN
#define OLED_SDA_PIN        I2C_SDA
#endif

#ifndef OLED_SCL_PIN
#define OLED_SCL_PIN        I2C_SCL
#endif

#ifndef OLED_RST_PIN
#define OLED_RST_PIN        -1
#endif

#ifndef OLED_EN_PIN
#define OLED_EN_PIN         -1
#endif

#ifndef MODE_BUTTON_PIN
#define MODE_BUTTON_PIN     14  // GPIO 14: MODE Button
#endif

#ifndef ACTION_BUTTON_PIN
#define ACTION_BUTTON_PIN   32  // GPIO 32: ACTION Button
#endif

#ifndef BATTERY_ADC_PIN
#define BATTERY_ADC_PIN     35  // GPIO 35: Battery ADC
#endif

#ifndef CHARGER_STAT_PIN
#define CHARGER_STAT_PIN    33  // GPIO 33: ETA6003 STAT
#endif

#ifndef WS2812_PIN
#define WS2812_PIN          -1
#endif

#ifndef BUZZER_PIN
#define BUZZER_PIN          -1
#endif

#define CLICK_I2C           Wire

#endif

// ==============================================================================
// Unified Button Reading Helpers
// ==============================================================================
static inline bool isActionButtonPressed() {
#if defined(TARGET_RP2354) || defined(ARDUINO_ARCH_RP2040)
    return BOOTSEL;
#else
    return digitalRead(ACTION_BUTTON_PIN) == LOW;
#endif
}

static inline bool isModeButtonPressed() {
    return digitalRead(MODE_BUTTON_PIN) == LOW;
}

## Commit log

2026-08-25 power management
2026-08-25 power issues and pin swap
2026-09-01 new app, new board.
2026-09-09 Bug fixes
    Fixed the 10000+ count format issue and the random pixel stuck issue.
    [Click4.kicad_pcb, Click4.kicad_sch, Click4.step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]
2026-09-10 correct pcb folder
    [Click4.kicad_pcb]
2026-09-11 power settings
2026-09-12 Sisyphus UI fixes and PCB LED changes
    [Click4.kicad_pcb, Click4.step]
2026-09-12 readme and docs changes
    with AI
    [Click4.kicad_pcb, click.kicad_pcb, click.kicad_sch]
2026-09-13 leaderboard management and stats syncing
    [Click4.kicad_pcb, Click4.kicad_sch]
2026-09-14 PCB LED changes and simple re-routing
    [Click4.kicad_pcb, Click4.kicad_sch, Click4_bom.csv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]
2026-09-14 enclosure fiels
    [Assem4.SLDASM, Back Plate w Hook.STL, Back Plate w window.STL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]
2026-09-15 pcb changes
    [Click4.kicad_pcb]
2026-09-15 kicad new production file
    [Click4.kicad_pcb]
2026-09-15 pcb silkscreen changes
    [Click4.kicad_pcb]
2026-09-15 pcb silk changes
    [Click4.kicad_pcb]
2026-09-17 PCB LED Updates
    [Click4.kicad_pcb, Click4.kicad_sch, Click4_bom.csv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]
2026-09-17 silk screen changes.
    [Click4.kicad_pcb]
2026-09-17 PCB files updates
    [Click4.kicad_pcb]
2026-10-04 kiforge file generations
    [Click4_v0.1.0_bom.csv, Click4_v0.1.0_bom_jlc.csv, QFN-60_L7.0-W7.0-P0.40-TL-EP3.4.step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]
2026-10-05 LED fixes, power issue fixes from software.
    [CounterApplet.cpp, OSManager.cpp, PinConfig.h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]
2026-10-10 wake with button issue fixed
    [CounterApplet.cpp, HardwareDiagnostics.cpp, OSManager.cpp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]
2026-10-10 Fix deployed site auto-detect, device renaming, and auto-sync stats on flash
2026-10-11 enclosure fies
2026-10-11 back plate
